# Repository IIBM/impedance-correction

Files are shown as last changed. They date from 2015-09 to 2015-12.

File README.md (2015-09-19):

# impedance-correction

This project involves the design, development and prototyping of an automated
**electrode impedance meter and corrector** for biological applications.

This will be achieved in the context of a basic embedded systems subject of the
Electronic Engineering career at the University of Buenos Aires:
[Laboratorio de Microcomputadoras](http://materias.fi.uba.ar/6609/).

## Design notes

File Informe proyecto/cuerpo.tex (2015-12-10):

%|//////////////////////////////////////|\\\\\\\\\\\\\\\\\\\\\\\\\\\\\\\\\\\\\|%
%|//////////////////////////| Objetivo del Proyecto |\\\\\\\\\\\\\\\\\\\\\\\\\|%
%|//////////////////////////////////////|\\\\\\\\\\\\\\\\\\\\\\\\\\\\\\\\\\\\\|%
\section{Objetivo del Proyecto}
% El objetivo es la respuesta a la pregunta “¿para qué?”; tiene que satisfacer alguna necesidad del usuario.

El presente proyecto consiste en el diseño y desarrollo de un sistema de calibración de impedancia y ajuste por electrodeposición (galvanoplastía). Este instrumento se utilizará en el futuro en aplicaciones biomédicas, más precisamente en la fabricación de electrodos de registro extracelular.

%|//////////////////////////////////////|\\\\\\\\\\\\\\\\\\\\\\\\\\\\\\\\\\\\\|%
%|////////////////////////| Descripción del Proyecto |\\\\\\\\\\\\\\\\\\\\\\\\|%
%|//////////////////////////////////////|\\\\\\\\\\\\\\\\\\\\\\\\\\\\\\\\\\\\\|%
\section{Descripción del Proyecto}
% En esta sección se responde la pregunta “¿cómo?”. Aquí se enumeran las prestaciones, las funciones y el comportamiento o uso del equipo.
El equipo consiste en un circuito con un microcontrolador que genera señales senoidales y continuas para medir y corregir las impedancias, respectivamente. Incluye una cuba conductora, que contiene una solución acuosa donde se colocan los electrodos. Éstos son similares a un filamento de cobre recubierto con esmalte aislante en su totalidad, excepto en los extremos, los cuales uno va sumergido en la solución y el otro conectado al equipo por medio de un conector especial.

El sistema funciona con 1, 4, 8, 12 ó 16 electrodos, corrigiendo de a uno por vez. El usuario coloca los electrodos procurando que no se produzcan cortocircuitos entre los mismos (se debería detectar esto antes de comenzar). Hay tres opciones: medir, calibrar y corregir. La primera permite ver el/los valor/es de la/s impedancia/s colocada/s en los conectores. La segunda, calibrar el equipo, tal como su nombre lo indica. La opción de corregir permite que el usuario seleccione la impedancia final deseada, el tiempo máximo de espera para la corrección y dé la orden de inicio. Luego de algunos chequeos básicos se da comienzo al proceso. Al terminar con todos los electrodos, se muestra la impedancia final de cada uno.

En líneas generales, el sistema consta de módulos de amplificación y filtros de PWM que permiten generar una señal senoidal con el microcontrolador, además de controlar la señal de offset. Asimismo, hay una fuente de corriente controlada por tensión que permite inyectar corriente continua al sistema para poder disminuir las impedancias necesarias por galvanoplastía.

La señal de salida del PWM es una corriente senoidal de \SI{1}{\kilo\hertz}, con uno de los siguientes valores de amplitud: $\{\SI{30}{\nano\ampere}, \SI{80}{\nano\ampere}, \SI{120}{\nano\ampere}, \SI{200}{\nano\ampere}\}$. Éstos se seleccionan con un multiplexor dependiendo del rango de impedancias: $\{0-\SI{2}{\mega\ohm}, 0-\SI{8}{\mega\ohm}, 0-\SI{20}{\mega\ohm}, 0-\SI{60}{\mega\ohm}\}$. Considerando la ley de Ohm y midiendo el valor pico de tensión, se calcula la impedancia del electrodo en estudio como $Z@\SI{1}{\kilo\hertz} = \frac{\hat{v}}{\hat{\imath}}$. Este valor se puede disminuir porque la solución acuosa contiene oro o plata, de modo de que se produce un recubrimiento por galvanoplastía sobre el electrodo y así disminuye la impedancia. Si este proceso es necesario o no, dependerá del resultado previo y de la comparación entre el valor obtenido en la medición y el de referencia establecido previamente por el usuario. Se emplea un multiplexor analógico para ir seleccionando cada electrodo y otro en paralelo con éste, que será eventualmente utilizado para verificar que no haya cortocircuitos entre electrodos.

Cada \SI{1}{\minute} se mide la impedancia y se corrige de ser necesario. Este proceso se repite tantas veces como se requiera hasta llegar al valor de impedancia deseada determinado previamente en la configuración. Los valores aceptables para empezar el proceso están entre \SI{1}{\mega\ohm} y \SI{8}{\mega\ohm}. Además, hay que pautar un tiempo máximo de sensado y corrección, para que el sistema deje de actuar en caso de haber pasado ese tiempo sin haber llegado al valor buscado. Éste puede valer 10, 20, 30, 40, 50 ó 60 minutos.

%|//////////////////////////////////////|\\\\\\\\\\\\\\\\\\\\\\\\\\\\\\\\\\\\\|%
%|/////////////////////////| Periféricos Principales |\\\\\\\\\\\\\\\\\\\\\\\\|%
%|//////////////////////////////////////|\\\\\\\\\\\\\\\\\\\\\\\\\\\\\\\\\\\\\|%

% Los periféricos son los elementos ajenos al microcontrolador con los que interactúa el equipo y deben estar claramente definidos (por ejemplo: motores, display, teclado, puertos de comunicación, sensores, etc.)

El dispositivo tiene una pantalla LCD donde se muestran las opciones de configuración para seleccionar a través de un menú y también los resultados del proceso, además de los mensajes de error o alerta (en caso de ocurrir algún imprevisto o no llegar al valor deseado en el tiempo pautado, por ejemplo). Las opciones se seleccionan desde un teclado de 4 botones (\texttt{ok}, \texttt{cancelar}, \texttt{mover izquierda}, \texttt{mover derecha}).

Además, como periféricos principales están los circuitos mencionados antes, a través de los cuales se interactúa directamente con los electrodos. Asimismo, otros elementos importantes con los que interactúa el microcontrolador son los multiplexores, que tienen 2 ó 4 entradas de control, según sean de 4 canales o 16, y la cuba electrolítica donde se produce la reacción química para disminuir la impedancia, que está compuesta por un material conductor, el cual también debe conectarse.

%|//////////////////////////////////////|\\\\\\\\\\\\\\\\\\\\\\\\\\\\\\\\\\\\\|%
%|///////////////| Características y Especificaciones Mínimas |\\\\\\\\\\\\\\\|%
%|//////////////////////////////////////|\\\\\\\\\\\\\\\\\\\\\\\\\\\\\\\\\\\\\|%

% Las especificaciones acotan las bondades del equipo. Deben listarse los rangos de funcionamiento o requerimientos externos (por ejemplo: tensión de alimentación, consumo, temperatura de funcionamiento, protocolos de comunicaciones, rangos de medición, etc.)

Las especificaciones del sistema son:

\begin{table}[H]
\begin{center}
\begin{tabular}{|r|l|}
    \hline
    Tensión de alimentación &
    \SI{5}{\volt} \\ \hline
    Rango de impedancias de los electrodos medidos &
    \SI{0}{\mega\ohm} - \SI{60}{\mega\ohm} (@ \SI{1}{\kilo\hertz})\\ \hline
    Impedancia buscada & $\simeq$ \SI{1}{\mega\ohm}\\ \hline
    Cantidad de electrodos a conectar &
    1, 4, 8, 12 ó 16 \\ \hline
    Tiempo máximo de corrección por electrodo &
    \SI{90}{\minute} (*)\\ \hline
    Modo medición & señal senoidal, \SI{1}{\kilo\hertz} \\ \hline
    Modo corrección & señal continua, 30/80/120/\SI{200}{\nano\ampere} \\ \hline
    Error de medición / corrección & $<$ 20\% / $<$ 20\% \\ \hline
\end{tabular}
\end{center}
\end{table}

(*) una vez cumplido este tiempo se abandonan los esfuerzos.

%|//////////////////////////////////////|\\\\\\\\\\\\\\\\\\\\\\\\\\\\\\\\\\\\\|%
%|/////////////////////| Diagrama en Bloques (hardware) |\\\\\\\\\\\\\\\\\\\\\|%
%|//////////////////////////////////////|\\\\\\\\\\\\\\\\\\\\\\\\\\\\\\\\\\\\\|%
\pagebreak
\section{Diagrama en Bloques (hardware)}
% El esquema general de interconexión de todos los dispositivos importantes se representa mediante un diagrama en bloques.
El diagrama de bloques aquí abajo muestra la interconexión de los dispositivos más relevantes del sistema.
\begin{center}
    
\end{center}

%|//////////////////////////////////////|\\\\\\\\\\\\\\\\\\\\\\\\\\\\\\\\\\\\\|%
%|//////////////////////| Diagrama de Flujo (firmware) |\\\\\\\\\\\\\\\\\\\\\\|%
%|//////////////////////////////////////|\\\\\\\\\\\\\\\\\\\\\\\\\\\\\\\\\\\\\|%
\section{Diagrama de Flujo  (firmware)}
% El diagrama de flujo ilustra de manera general la interacción entre los distintos bloques (o rutinas) de código.
El diagrama de flujo final del proyecto es el siguiente:
\begin{center}
    
\end{center}

%|//////////////////////////////////////|\\\\\\\\\\\\\\\\\\\\\\\\\\\\\\\\\\\\\|%
%|//////////////////////////| Circuito Esquemático |\\\\\\\\\\\\\\\\\\\\\\\\\\|%
%|//////////////////////////////////////|\\\\\\\\\\\\\\\\\\\\\\\\\\\\\\\\\\\\\|%
\section{Circuito Esquemático}
% La representación del circuito eléctrico final del prototipo debe realizarse en algún sistema CAD; no es necesario el diseño del circuito impreso (PCB), basta con el circuito esquemático.
A continuación se muestra el circuito esquemático correspondiente al prototipo, así como también el diseño del PCB. Ambos fueron realizados con el programa KiCad.\\

\hspace{-1.8cm}
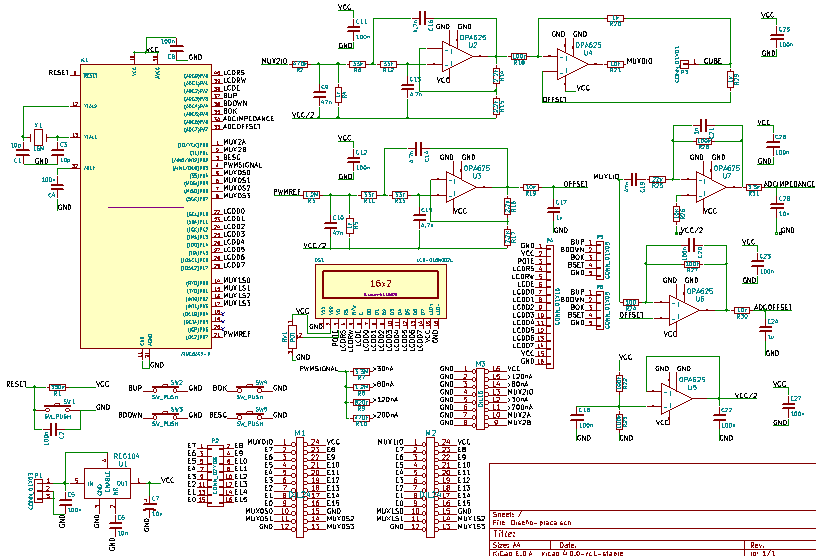
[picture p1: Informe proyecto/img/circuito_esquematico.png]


\hspace{-1cm}
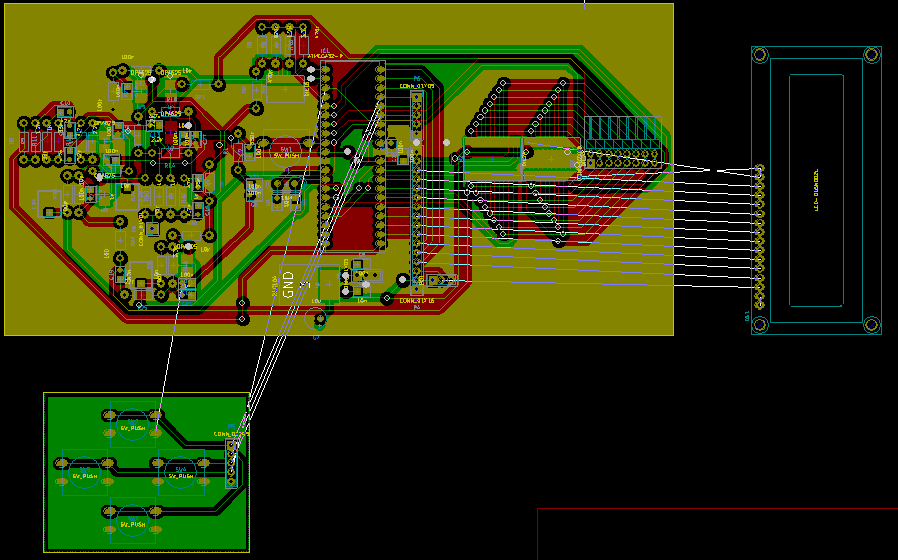
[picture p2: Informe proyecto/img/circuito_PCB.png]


%|//////////////////////////////////////|\\\\\\\\\\\\\\\\\\\\\\\\\\\\\\\\\\\\\|%
%|////////////////| Listado de Componentes y Costos Estimados |\\\\\\\\\\\\\\\|%
%|//////////////////////////////////////|\\\\\\\\\\\\\\\\\\\\\\\\\\\\\\\\\\\\\|%
\section{Listado de Componentes y Costos}
% En esta sección se debe incluir el listado final de componentes con sus respectivos costos. Además deben incorporar la estimación de horas-hombre insumidas en la realización del proyecto.
Los componentes que se emplearon para la construcción del dispositivo se muestran en la tabla siguiente:

\begin{table}[H]
\begin{center}
\begin{tabular}{|l|rr|}
    \hline
    \textbf{Componente} & \multicolumn{2}{c|}{\textbf{Costo}} \\ \hline
    Atmega32            & \hspace{2.8cm}\$ &   164.5 \\ \hline
    OPA625 x6 (*)       & \$               &   166.2 \\ \hline
    REG104 (*)          & \$               &   70.0 \\ \hline
    CD74HC4067 x2 (*)   & \$               &   16.8 \\ \hline
    SN74LV4052 (*)      & \$               &   5.0 \\ \hline
    Resistencias x30    & \$               &   9.6 \\ \hline
    Potenciómetro       & \$               &   6.7 \\ \hline
    Capacitores x31     & \$               &   43.1 \\ \hline
    Display LCD         & \$               &   120.0 \\ \hline
    Pulsadores x5       & \$               &   18.8 \\ \hline
    Cristal 16 Mhz      & \$               &   6.0 \\ \hline
    Conectores          & \$               &   8.6 \\ \hline
    Placa Epoxy         & \$               &   120.0 \\ \hline
    Zócalo              & \$               &   3.0 \\ \hline
    Jack power          & \$               &   3.2 \\ \hline
    TOTAL               & \$               &   761.5 \\ \hline
\end{tabular}
\end{center}
\end{table}

Los componentes marcados con un asterisco(*) son de Texas Instruments y en el marco del IIBM y de la Facultad se obtuvieron como muestras gratis. Por ende, para este trabajo en particular el costo de los componentes utilizados fue de $\$ 503.5$.\\

En cuanto a las horas-hombre involucradas, se puede estimar un número de 300 horas/hombre.

%|//////////////////////////////////////|\\\\\\\\\\\\\\\\\\\\\\\\\\\\\\\\\\\\\|%
%|///////////////////////////////| Resultados |\\\\\\\\\\\\\\\\\\\\\\\\\\\\\\\|%
%|//////////////////////////////////////|\\\\\\\\\\\\\\\\\\\\\\\\\\\\\\\\\\\\\|%
\section{Resultados}
% No siempre se logran los objetivos propuestos (o al menos en su totalidad); es importante que puedan validar y/o ajustar las expectativas indicando las limitaciones finales del prototipo construido.

Debido a las complicaciones en el diseño del hardware y los reiterados cambios que fueron hechos con el desarrollo del proyecto, se modificó el circuito de manera de poder medir impedancias del orden de los $k\Omega$, en vez de $M\Omega$, ya que las señales eran muy pequeñas y no se diferenciaban de las señales de ruido. Los nuevos rangos de medición son: $\{0-\SI{143}{\kilo\ohm}, \SI{143}{\kilo\ohm}-\SI{243}{\kilo\ohm}, \SI{243}{\kilo\ohm}-\SI{335}{\mega\ohm}, \SI{335}{\kilo\ohm}-\SI{900}{\mega\ohm}\}$.

Con estas modificaciones se pudo obtener un funcionamiento acorde a lo esperado, visualizando valores de impedancia en el display con un error aproximado del 15\%. Este error se debe a la alinealidad que genera el circuito. Como hipótesis, es posible considerar que se debe a que la fuente de corriente ya no se comporta linealmente con estos nuevos valores de corriente (se aumentaron 100 veces).

Fue posible observar el correcto funcionamiento de las rutinas de impresión por display, conversión ADC, obtención de la mediana a través de ordenamiento de tablas por burbujeo, utilización de pulsadores externos, timers, interrupciones, PWM. Se pudo observar, con el uso de un osciloscopio, el funcionamiento de la rutina de corrección de electrodos, observando un valor de continua. En la imagen a continuación se puede ver cómo en una primera etapa no hay corriente circulando, luego se observa la senoidal que sirve para medir y finalmente un valor de continua que permite corregir el valor de la impedancia.

\hspace{-1cm}


%|//////////////////////////////////////|\\\\\\\\\\\\\\\\\\\\\\\\\\\\\\\\\\\\\|%
%|//////////////////////////////| Conclusiones |\\\\\\\\\\\\\\\\\\\\\\\\\\\\\\|%
%|//////////////////////////////////////|\\\\\\\\\\\\\\\\\\\\\\\\\\\\\\\\\\\\\|%
\section{Conclusiones}
% En este punto tienen que describir mejoras posibles que podrían hacerse al equipo, cambios sugeridos en función de las experiencias aprendidas  y cualquier otra sugerencia relacionada con el proyecto.
Como mejoras, se puede mencionar que es altamente recomendable contar con una opción más en el menú para determinar si dos electrodos están o no en cortocircuito. Para ello, se emplea el segundo multiplexor (que aparece en el diseño pero no forma parte de este proyecto). Se podría realizar inyectando señal en cada electrodo y chequeando sobre cada uno de los restantes que no se reciba un nivel elevado de ésta. Además, agre

Por otro lado, sería útil para el usuario que hubiera alguna identificación para ver cuándo mide correctamente cada electrodo, si hay dos en cortocircuito y demás cuestiones que momentáneamente sólo aparecen al final del proceso (leds, por pantalla, etc), así el usuario no tiene que esperar hasta el final para ver si funcionó correctamente o no.

%|//////////////////////////////////////|\\\\\\\\\\\\\\\\\\\\\\\\\\\\\\\\\\\\\|%
%|////////////////////////////////| Apéndices |\\\\\\\\\\\\\\\\\\\\\\\\\\\\\\\|%
%|//////////////////////////////////////|\\\\\\\\\\\\\\\\\\\\\\\\\\\\\\\\\\\\\|%
\section{Apéndices}
% Como complemento al informe, en esta sección deben agregar el listado completo de software, las hojas de datos principales y cualquier otra información, referencia o cálculo relacionada con el proyecto (por ejemplo el uso de interrupciones).

\subsection{Cálculos}
A continuación se muestran los cálculos involucrados en la obtención de los parámetros $p$ por el que habrá que multiplicar a la medición del valor pico para obtener la impedancia. Vale aclarar que estos son valores iniciales y luego serán corregidos durante la calibración automática del equipo.

Los valores de lectura del ADC (8 bits), se procesan de la siguiente manera, para obtener un único valor pico, $\hat{L}$:
\begin{enumerate}
    \item Se muestrean 9 períodos.
    \item Se obtienen los máximos y mínimos locales de cada período.
    \item Se ordenan dichos máximos y mínimos en dos tablas, de menor a mayor.
    \item Se obtiene la mediana de cada tabla, eligiendo el valor central de la tabla ordenada.
    \item Se calcula $\hat{L} = \frac{<MAX>\,-\,<MIN>}{2}$.
\end{enumerate}

Una vez realizado esto se tiene en cuenta lo siguiente:
\begin{itemize}
    \item Como se dijo, $\hat{L}$ es el valor pico (en 8 bits) obtenido luego de procesar la señal muestreada.
    \item $k_{ADC}$ es la constante que lleva desde valores de lectura de 8 bits del ADC a \emph{volts}.
    \item $G$ es la ganancia de tensión del amplificador del ADC.
\end{itemize}

Entonces:
$$
    Z = \frac{\hat{v}}{\hat{\imath}} = \frac{G\,\hat{v}_{ADC}}{\hat{\imath}} = \frac{G\,k_{ADC}}{\hat{\imath}}\,\hat{L} = \alpha\,\hat{L}
$$

Como se ha visto, más allá de los factores que intervienen en la constante, la impedancia es proporcional al valor pico de lectura. Ahora, como la unidad interna de representación son \emph{décimas de mega ohm}, lo que se obtiene es $\beta = \frac{\alpha}{\SI{0.1}{\mega\ohm}}$, de forma tal que $\beta\,\hat{L}$ es la impedancia en la unidad deseada.

Dado que $\beta$ resulta menor a 1, y que no se dispone de una operación de división por hardware, se utilizará el parámetro $p = \lceil \gamma\,\beta \rceil$, donde $\gamma$ es una potencia de dos. En este caso se eligió $\gamma = 2^8 = 256$ y en consecuencia:
$$
    Z\ [[decimegohm]] = \beta\,\hat{L} = \frac{p\,\hat{L}}{\gamma} = \frac{p\,\hat{L}}{256} =  (p\,\hat{L})>>8
$$

Entonces el valor del parámetro $p$ está dado por:
$$
    p = \lceil \gamma\,\beta \rceil = \left\lceil \gamma\,\frac{\alpha}{\SI{0.1}{\mega\ohm}} \right\rceil = \left\lceil \gamma\,\frac{G\,k_{ADC}}{\SI{0.1}{\mega\ohm}\,\hat{\imath}} \right\rceil
$$

Dado que depende de $\hat{\imath}$, la cual es distinta en cada rango de medición, para esto y algunos cálculos extras de errores se utilizó la siguiente planilla.

\hspace{-2cm}

\subsection{Hojas de datos}

Los componentes empleados son:
\begin{table}[H]
\begin{center}
\begin{tabular}{|l|c|}
    \hline
    \textbf{Componente} & \textbf{Hoja de datos} \\ \hline
    Atmega32      & \url{http://www.atmel.com/images/doc2503.pdf} \\ \hline
    OPA625        & \url{http://www.ti.com/lit/ds/symlink/opa625.pdf} \\ \hline
    REG104        & \url{http://www.ti.com/lit/ds/symlink/reg104.pdf} \\ \hline
    CD74HC4067    & \url{http://www.ti.com/lit/ds/symlink/cd74hc4067.pdf} \\ \hline
    SN74LV4052    & \url{http://www.ti.com/lit/ds/symlink/sn74lv4052a.pdf} \\ \hline
    Display LCD   & \url{http://elmicro.com/files/lcd/gdm1602a\_datasheet.pdf} \\ \hline
\end{tabular}
\end{center}
\end{table}

%------------------------------------------------------------------------------%
%------------------------------- Códigos Fuente -------------------------------%
%------------------------------------------------------------------------------%
\subsection{Códigos fuente}
En las siguientes páginas se incluyen a modo de apéndice todos los archivos que conforman el firmware de equipo.

\subsubsection{configs.asm}
    \lstinputlisting[language=asmAVR]{src/configs.asm}

\subsubsection{main.asm}
    \lstinputlisting[language=asmAVR]{src/main.asm}

\subsubsection{MENU.asm}
    \lstinputlisting[language=asmAVR]{src/MENU.asm}

\subsubsection{MEDIR.asm}
    \lstinputlisting[language=asmAVR]{src/MEDIR.asm}

\subsubsection{CORREGIR\_FIN.asm}
    \lstinputlisting[language=asmAVR]{src/CORREGIR_FIN.asm}

\subsubsection{BCD.asm}
    \lstinputlisting[language=asmAVR]{src/BCD.asm}

\subsubsection{LCD.asm}
    \lstinputlisting[language=asmAVR]{src/LCD.asm}

\subsubsection{pwm.asm}
    \lstinputlisting[language=asmAVR]{src/pwm.asm}

\subsubsection{adc.asm}
    \lstinputlisting[language=asmAVR]{src/adc.asm}

\subsubsection{measure\_routines.asm}
    \lstinputlisting[language=asmAVR]{src/measure_routines.asm}

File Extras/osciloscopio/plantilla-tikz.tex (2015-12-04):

\documentclass{standalone}
\usepackage[utf8]{inputenc}
\usepackage[spanish]{babel}
\usepackage{siunitx}
\sisetup{output-decimal-marker = {,}} % Coma en vez de punto decimal
\usepackage{tikz}

\begin{document}
\newcommand{\Leg}[1]{{\footnotesize #1}}
\newcommand{\M}[1]{\Leg{$#1$}}

\input{_TIKZ_IMAGE_}
\end{document}

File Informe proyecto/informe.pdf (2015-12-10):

# F i u b a

# Facultad de Ingeniería

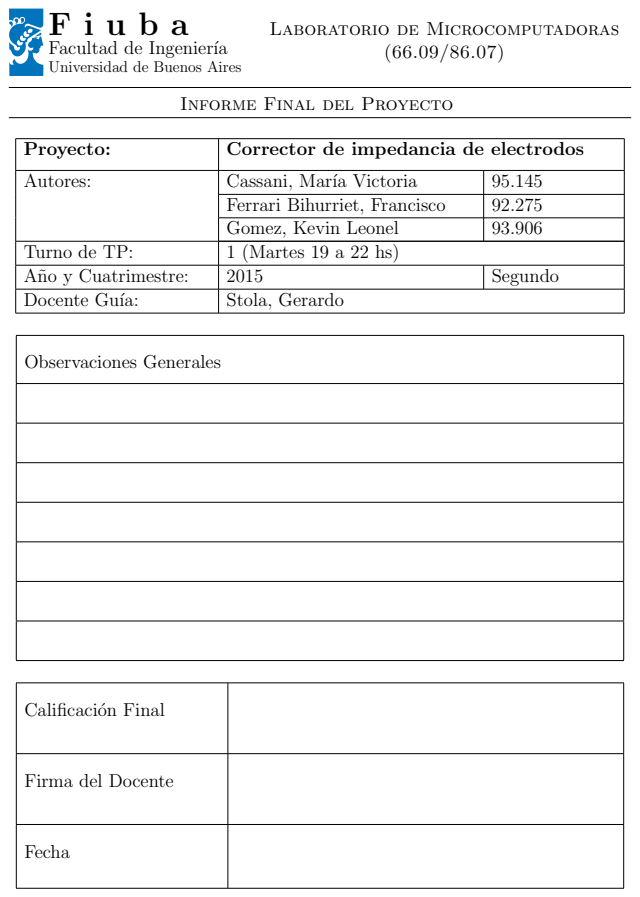
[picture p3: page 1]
Observaciones Generales

Laboratorio de Microcomputadoras

Universidad de Buenos Aires

Informe Final del Proyecto

Proyecto: | Corrector de impedancia de electrodos

Autores: | Cassani, María Victoria | 95.145

Ferrari Bihurriet, Francisco | 92.275
Gomez, Kevin Leonel | 93.906

Turno de TP: | 1 (Martes 19 a 22 hs)
Año y Cuatrimestre: | 2015 | Segundo
Docente Guía: | Stola, Gerardo

Calificación Final

Firma del Docente

Fecha

66.09/86.07 - Laboratorio de Microcomputadoras | Corrector de impedancia de electrodos

# Índice

1. Objetivo del Proyecto | 2
2. Descripción del Proyecto | 2
3. Diagrama en Bloques (hardware) | 4
4. Diagrama de Flujo (firmware) | 5
5. Circuito Esquemático | 6
6. Listado de Componentes y Costos | 7
7. Resultados | 8
8. Conclusiones | 9
9. Apéndices | 9
Cassani - Ferrari Bihurriet - Gomez | 1

# 1. Objetivo del Proyecto

## El presente proyecto consiste en el diseño y desarrollo de un sistema de calibración de

impedancia y ajuste por electrodeposición (galvanoplastía). Este instrumento se utilizará en el futuro en aplicaciones biomédicas, más precisamente en la fabricación de electrodos de registro extracelular.

# 2. Descripción del Proyecto

El equipo consiste en un circuito con un microcontrolador que genera señales senoidales y continuas para medir y corregir las impedancias, respectivamente. Incluye una cuba conducto-ra, que contiene una solución acuosa donde se colocan los electrodos. Estos son similares a un ´ filamento de cobre recubierto con esmalte aislante en su totalidad, excepto en los extremos, los cuales uno va sumergido en la solución y el otro conectado al equipo por medio de un conector especial.

## El sistema funciona con 1, 4, 8, 12 ó 16 electrodos, corrigiendo de a uno por vez. El

usuario coloca los electrodos procurando que no se produzcan cortocircuitos entre los mismos (se debería detectar esto antes de comenzar). Hay tres opciones: medir, calibrar y corregir. La primera permite ver el/los valor/es de la/s impedancia/s colocada/s en los conectores. La segunda, calibrar el equipo, tal como su nombre lo indica. La opción de corregir permite que el usuario seleccione la impedancia final deseada, el tiempo máximo de espera para la corrección y dé la orden de inicio. Luego de algunos chequeos básicos se da comienzo al proceso. Al terminar con todos los electrodos, se muestra la impedancia final de cada uno.

## En líneas generales, el sistema consta de módulos de amplificación y filtros de PWM que permiten generar una señal senoidal con el microcontrolador, además de controlar la

señal de offset. Asimismo, hay una fuente de corriente controlada por tensión que permite inyectar corriente continua al sistema para poder disminuir las impedancias necesarias por galvanoplastía.

## La señal de salida del PWM es una corriente senoidal de 1 kHz, con uno de los siguientes

valores de amplitud: {30 nA, 80 nA, 120 nA, 200 nA}. Estos se seleccionan con un multiplexor ´

## dependiendo del rango de impedancias: {0 − 2 MΩ, 0 − 8 MΩ, 0 − 20 MΩ, 0 − 60 MΩ}. Con-

siderando la ley de Ohm y midiendo el valor pico de tensión, se calcula la impedancia del

## electrodo en estudio como Z@1 kHz = vˆ

î

## . Este valor se puede disminuir porque la solución

acuosa contiene oro o plata, de modo de que se produce un recubrimiento por galvanoplastía sobre el electrodo y así disminuye la impedancia. Si este proceso es necesario o no, depen-derá del resultado previo y de la comparación entre el valor obtenido en la medición y el de referencia establecido previamente por el usuario. Se emplea un multiplexor analógico para ir seleccionando cada electrodo y otro en paralelo con éste, que será eventualmente utilizado para verificar que no haya cortocircuitos entre electrodos.

Cada 1 min se mide la impedancia y se corrige de ser necesario. Este proceso se repite tantas veces como se requiera hasta llegar al valor de impedancia deseada determinado previamente en la configuración. Los valores aceptables para empezar el proceso están entre 1 MΩ y 8 MΩ.

Además, hay que pautar un tiempo máximo de sensado y corrección, para que el sistema deje de actuar en caso de haber pasado ese tiempo sin haber llegado al valor buscado. Este puede ´ valer 10, 20, 30, 40, 50 ó 60 minutos.

## El dispositivo tiene una pantalla LCD donde se muestran las opciones de configuración

para seleccionar a través de un menú y también los resultados del proceso, además de los mensajes de error o alerta (en caso de ocurrir algún imprevisto o no llegar al valor deseado en el tiempo pautado, por ejemplo). Las opciones se seleccionan desde un teclado de 4 botones (ok, cancelar, mover izquierda, mover derecha).

Además, como periféricos principales están los circuitos mencionados antes, a través de los cuales se interactúa directamente con los electrodos. Asimismo, otros elementos importantes con los que interactúa el microcontrolador son los multiplexores, que tienen 2 ó 4 entradas de control, según sean de 4 canales o 16, y la cuba electrolítica donde se produce la reacción química para disminuir la impedancia, que está compuesta por un material conductor, el cual también debe conectarse.

## Las especificaciones del sistema son:

Tensión de alimentación | 5 V
Rango de impedancias de los electrodos medidos | 0 MΩ - 60 MΩ (@ 1 kHz)
Impedancia buscada | ' 1 MΩ
Cantidad de electrodos a conectar | 1, 4, 8, 12 ó 16
Tiempo máximo de corrección por electrodo | 90 min (*)
Modo medición | señal senoidal, 1 kHz
Modo corrección | señal continua, 30/80/120/200 nA
Error de medición / corrección | < 20 % / < 20 %

(*) una vez cumplido este tiempo se abandonan los esfuerzos.

# 3. Diagrama en Bloques (hardware)

El diagrama de bloques aquí abajo muestra la interconexión de los dispositivos más rele-vantes del sistema.

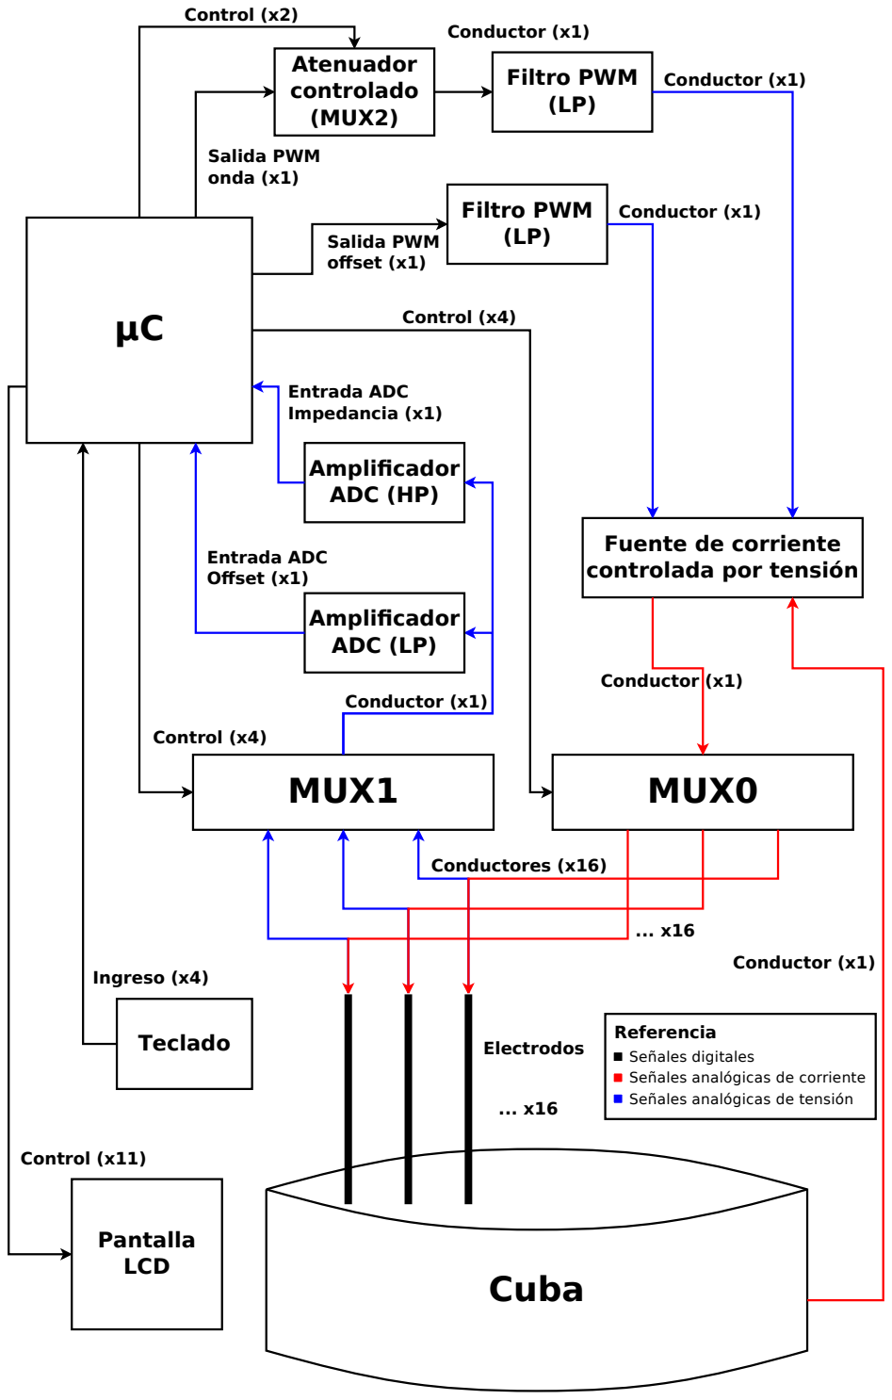
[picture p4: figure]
Fuente de corriente controlada por tensión; MUX1; MUX0; Teclado; Pantalla LCD; Control (x4); Entrada ADC Impedancia (x1); Ingreso (x4); Salida PWM onda (x1); Control (x2); Conductor (x1); Conductores (x16); Control (x11); Filtro PWM (LP); Atenuador controlado (MUX2); Amplificador ADC (HP); Amplificador ADC (LP); Cuba; Salida PWM offset (x1); Entrada ADC Offset (x1); Electrodos; Señales digitales Señales analógicas de corriente Señales analógicas de tensión; Referencia

# 4. Diagrama de Flujo (firmware)

## El diagrama de flujo final del proyecto es el siguiente:

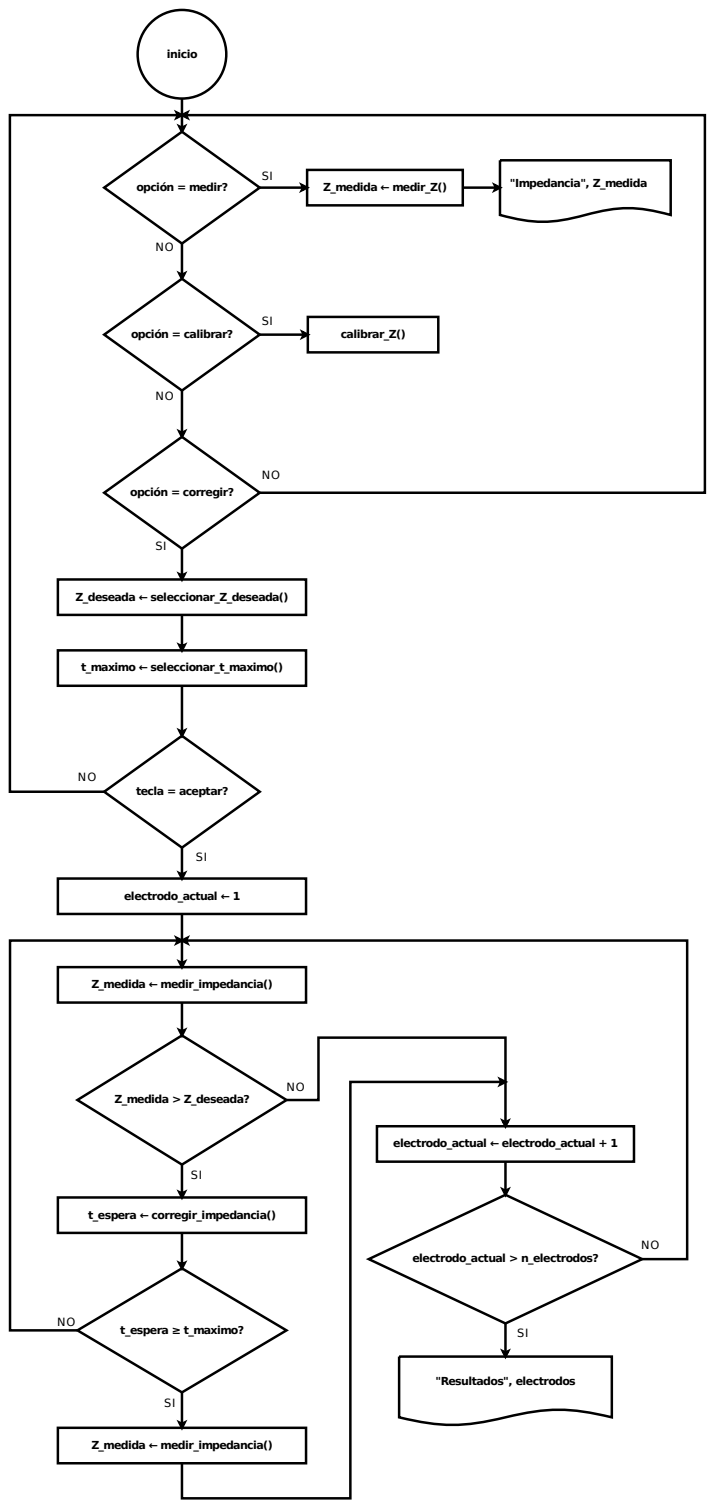
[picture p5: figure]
"Impedancia", Z_medida; inicio; Z_deseada ← seleccionar_Z_deseada(); t_maximo ← seleccionar_t_maximo(); tecla = aceptar?; electrodo_actual ← 1; Z_medida > Z_deseada?; t_espera ← corregir_impedancia(); t_espera ≥ t_maximo?; Z_medida ← medir_impedancia(); electrodo_actual ← electrodo_actual + 1; electrodo_actual > n_electrodos?; "Resultados", electrodos; opción = medir?; Z_medida ← medir_Z(); opción = calibrar?; calibrar_Z(); opción = corregir?

# 5. Circuito Esquemático

A continuación se muestra el circuito esquemático correspondiente al prototipo, así como

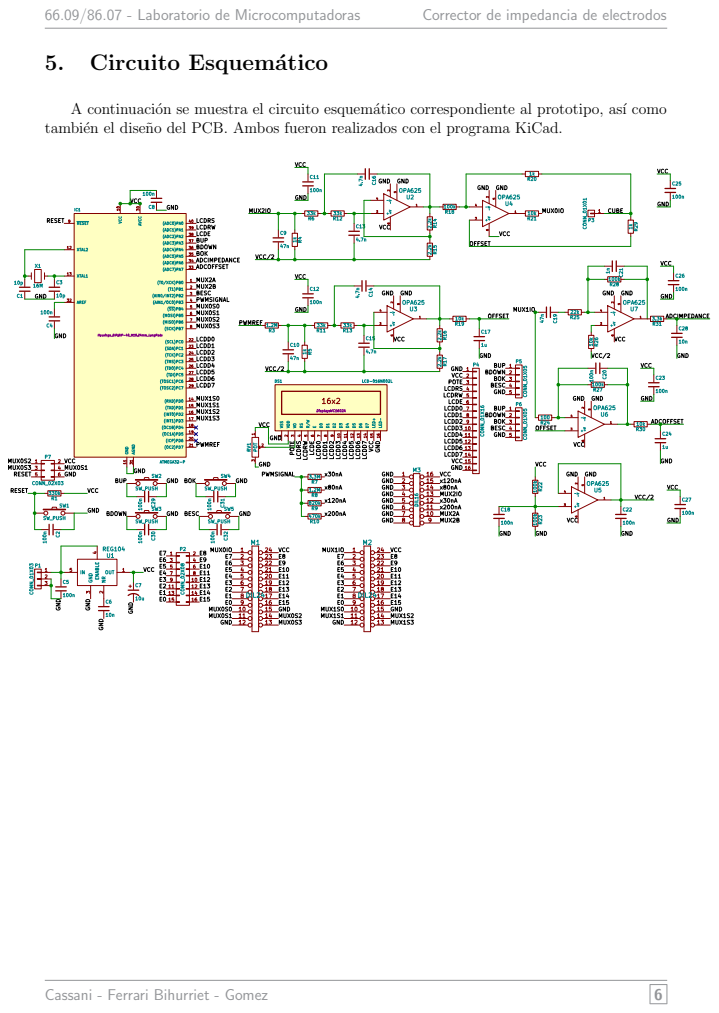
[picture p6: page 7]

también el diseño del PCB. Ambos fueron realizados con el programa KiCad.

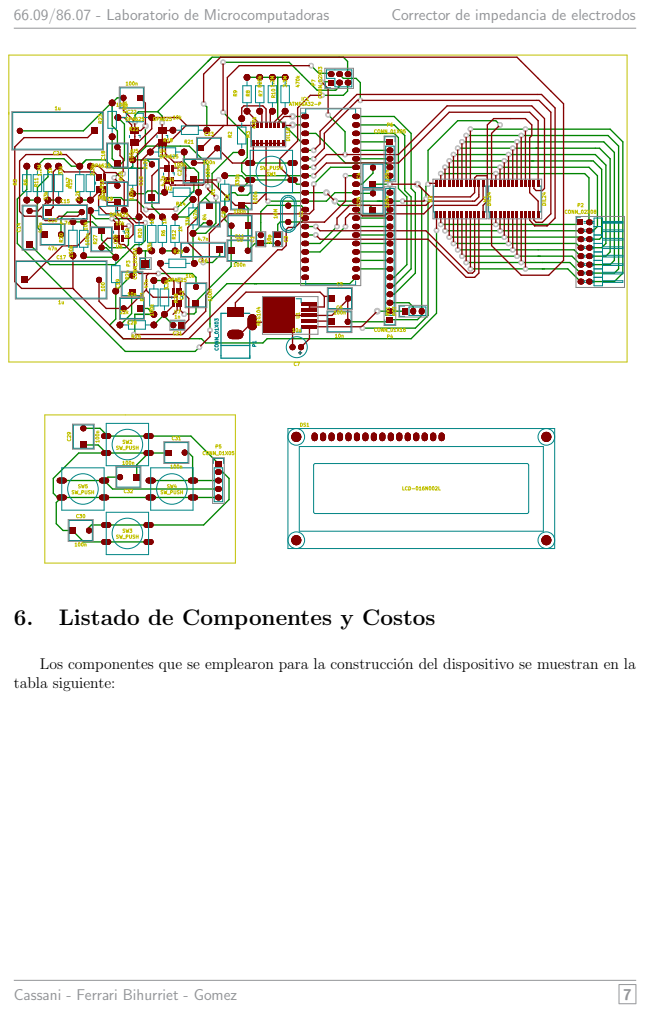
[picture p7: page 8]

6. Listado de Componentes y Costos

Los componentes que se emplearon para la construcción del dispositivo se muestran en la
tabla siguiente:

Componente | Costo
Atmega32 | $ 164.5
OPA625 x6 (*) | $ 166.2
REG104 (*) | $ 70.0
CD74HC4067 x2 (*) | $ 16.8
SN74LV4052 (*) | $ 5.0
Resistencias x30 | $ 9.6
Potenciómetro | $ 6.7
Capacitores x31 | $ 43.1
Display LCD | $ 120.0
Pulsadores x5 | $ 18.8
Cristal 16 Mhz | $ 6.0
Conectores | $ 8.6
Placa Epoxy | $ 120.0
Zócalo | $ 3.0
Jack power | $ 3.2
TOTAL | $ 761.5

## Los componentes marcados con un asterisco(*) son de Texas Instruments y en el marco

del IIBM y de la Facultad se obtuvieron como muestras gratis. Por ende, para este trabajo en particular el costo de los componentes utilizados fue de $503,5.

## En cuanto a las horas-hombre involucradas, se puede estimar un número de 300 hora-

s/hombre.

# 7. Resultados

## Debido a las complicaciones en el diseño del hardware y los reiterados cambios que fueron hechos con el desarrollo del proyecto, se modificó el circuito de manera de poder medir impedancias del orden de los kΩ, en vez de MΩ, ya que las señales eran muy pe-

queñas y no se diferenciaban de las señales de ruido. Los nuevos rangos de medición son: {0 − 143 kΩ, 143 kΩ − 243 kΩ, 243 kΩ − 335 MΩ, 335 kΩ − 900 MΩ}.

## Con estas modificaciones se pudo obtener un funcionamiento acorde a lo esperado, visua-

lizando valores de impedancia en el display con un error aproximado del 15 %. Este error se debe a la alinealidad que genera el circuito. Como hipótesis, es posible considerar que se debe a que la fuente de corriente ya no se comporta linealmente con estos nuevos valores de corriente (se aumentaron 100 veces).

Fue posible observar el correcto funcionamiento de las rutinas de impresión por display, conversión ADC, obtención de la mediana a través de ordenamiento de tablas por burbujeo, utilización de pulsadores externos, timers, interrupciones, PWM. Se pudo observar, con el uso de un osciloscopio, el funcionamiento de la rutina de corrección de electrodos, observando un valor de continua. En la imagen a continuación se puede ver cómo en una primera etapa no hay corriente circulando, luego se observa la senoidal que sirve para medir y finalmente un valor de continua que permite corregir el valor de la impedancia.

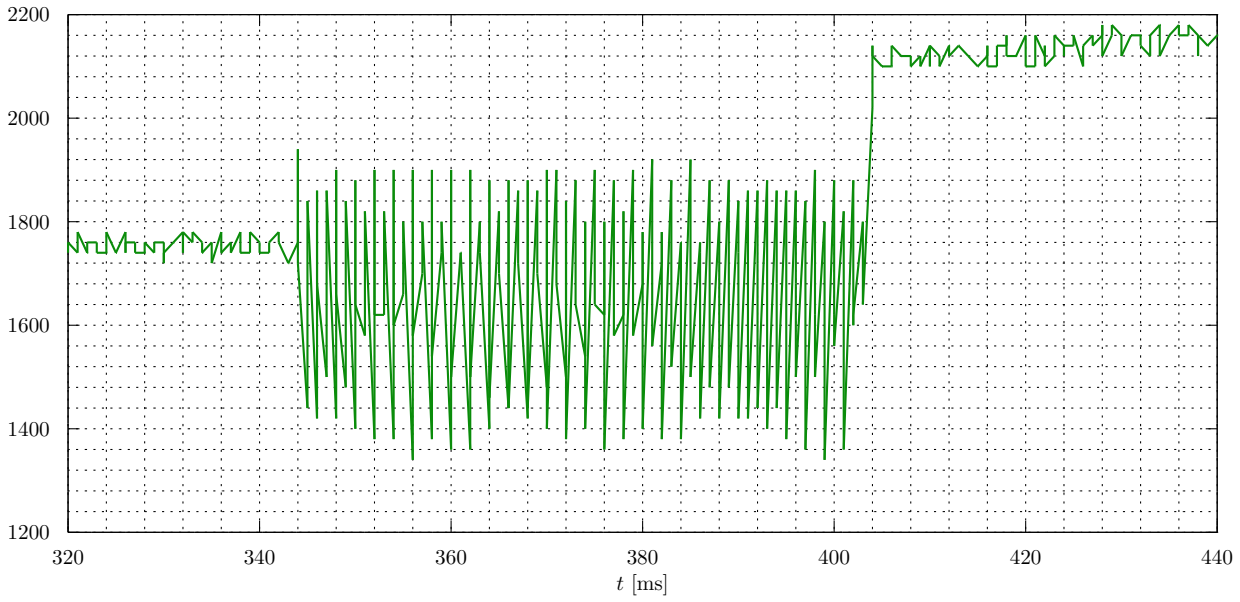
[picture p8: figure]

## V [mV]

# 8. Conclusiones

## Como mejoras, se puede mencionar que es altamente recomendable contar con una opción

más en el menú para determinar si dos electrodos están o no en cortocircuito. Para ello, se emplea el segundo multiplexor (que aparece en el diseño pero no forma parte de este proyecto). Se podría realizar inyectando señal en cada electrodo y chequeando sobre cada uno de los

## restantes que no se reciba un nivel elevado de ésta. Además, agre

Por otro lado, sería útil para el usuario que hubiera alguna identificación para ver cuándo mide correctamente cada electrodo, si hay dos en cortocircuito y demás cuestiones que mo-mentáneamente sólo aparecen al final del proceso (leds, por pantalla, etc), así el usuario no tiene que esperar hasta el final para ver si funcionó correctamente o no.

# 9. Apéndices

# 9.1. Cálculos

A continuación se muestran los cálculos involucrados en la obtención de los parámetros p por el que habrá que multiplicar a la medición del valor pico para obtener la impedancia. Vale aclarar que estos son valores iniciales y luego serán corregidos durante la calibración automática del equipo.

## Los valores de lectura del ADC (8 bits), se procesan de la siguiente manera, para obtener un único valor pico, Lˆ:

1. Se muestrean 9 períodos.
2. Se obtienen los máximos y mínimos locales de cada período.
3. Se ordenan dichos máximos y mínimos en dos tablas, de menor a mayor.
4. Se obtiene la mediana de cada tabla, eligiendo el valor central de la tabla ordenada.

## 5. Se calcula Lˆ =

<MAX> − <MIN>
2

## Una vez realizado esto se tiene en cuenta lo siguiente:

Como se dijo, Lˆ es el valor pico (en 8 bits) obtenido luego de procesar la señal muestreada.

kADC es la constante que lleva desde valores de lectura de 8 bits del ADC a volts.

G es la ganancia de tensión del amplificador del ADC.

## Entonces:

Z =

vˆ
î

=

## G vÂDC

î

=

G kADC
î

## Lˆ = α Lˆ

Como se ha visto, más allá de los factores que intervienen en la constante, la impedancia es proporcional al valor pico de lectura. Ahora, como la unidad interna de representación son

## décimas de mega ohm, lo que se obtiene es β =

α

## 0,1 MΩ, de forma tal que β Lˆ es la impedancia

en la unidad deseada.

## Dado que β resulta menor a 1, y que no se dispone de una operación de división por

hardware, se utilizará el parámetro p = dγ βe, donde γ es una potencia de dos. En este caso

## se eligió γ = 2⁸ = 256 y en consecuencia:

## Z [[decimegohm]] = β Lˆ =

## p Lˆ

γ

=

## p Lˆ

256

## = (p Lˆ) >> 8

## Entonces el valor del parámetro p está dado por:

## p = dγ βe =

γ

α

0,1 MΩ
=
γ

G kADC

## 0,1 MΩî

Dado que depende de î, la cual es distinta en cada rango de medición, para esto y algunos cálculos extras de errores se utilizó la siguiente planilla.

Rango [MΩ] | I máx [nA] | Escala: x/128 (por soft) | I [nA] | ΔV [mV] si ΔZ = 0,1MΩ | ΔZ [MΩ] si ΔV = kADC | ΔZ [MΩ] si ΔV = 96,5mV | Vexcursión [V] | α [kΩ] | β = α / 0,1 MΩ | p = γ β ⌈ ⌉ | Error absoluto [kΩ] | Error relativo [%]
0 2 | | 200,00 212,31 | 128 100,00% | 200,00 212,31 | 90,91 96,51 | 0,021 0,020 | 0,106 0,100 | 1,82 1,93 | 21,48 20,24 | 0,215 0,202 | 55 52 | 100 100 | 10,00% 10,00%
0 8 | | 80,00 83,26 | 84 65,63% | 52,50 54,64 | 23,86 24,84 | 0,082 0,079 | 0,404 0,389 | 1,91 1,99 | 81,85 78,64 | 0,818 0,786 | 210 202 | 100 100 | 2,50% 2,50%
0 | 20 | 30,00 30,29 | 92 71,88% | 21,56 21,77 | 9,80 9,90 | 0,199 0,197 | 0,985 0,975 | 1,96 1,98 | 199,28 197,34 | 1,993 1,973 | 511 506 | 100 200 | 1,00% 2,00%
0 | 60 | 30,00 30,29 | 30 23,44% | 7,03 7,10 | 3,20 3,23 | 0,611 0,605 | 3,020 2,990 | 1,92 1,94 | 611,11 605,18 | 6,111 6,052 | 1565 1550 | 100 400 | 0,33% 1,33%
G OpAmp ADC | Vexcursión deseado [V] | kADC [mV] | γ = 2^k
4,55 | 2,00 | 19,53 | 256
Corriente deseada [nA] | R multiplexada [kΩ] | Corriente final [nA]
30 | 3300 | 30,29
80 | 1200 | 83,26
120 | 820 | 121,80
200 | 470 | 212,31

# 9.2. Hojas de datos

## Los componentes empleados son:

Componente | Hoja de datos
Atmega32 | http://www.atmel.com/images/doc2503.pdf
OPA625 | http://www.ti.com/lit/ds/symlink/opa625.pdf
REG104 | http://www.ti.com/lit/ds/symlink/reg104.pdf
CD74HC4067 | http://www.ti.com/lit/ds/symlink/cd74hc4067.pdf
SN74LV4052 | http://www.ti.com/lit/ds/symlink/sn74lv4052a.pdf
Display LCD | http://elmicro.com/files/lcd/gdm1602a_datasheet.pdf

# 9.3. Códigos fuente

En las siguientes páginas se incluyen a modo de apéndice todos los archivos que conforman el firmware de equipo.

## 9.3.1. configs.asm

1 ; ||||||||||||||||||||||||||||||||||||||||||||||||||||||||||||||||||||||||||||||; 2 ; ||||||||||||||||||||||||||||||||| Constantes |||||||||||||||||||||||||||||||||; 3 ; ||||||||||||||||||||||||||||||||||||||||||||||||||||||||||||||||||||||||||||||;

4
5 ; ---------------------------- Configuraci ón del PWM -- ---- ----- ----- ---- ----- --;
6 ;
7 ; Compare Output Mode : COMn1 : COMn0 = 1:0 => Clear OCn on compare match
8 ; Waveform Generation Mode : WGMn1 : WGMn0 1:1 => Fast PWM
9 ; Clock select : CSn2 : CSn1 : CSn0 = 0:0:1 => CPU clock , no prescaling
10 ;
11 ; * Timer / Counter -n Control Register : (n = 0 , 2. Timer / Counter0 , Timer / Counter2 )
12 ; | | | FOCn | | | WGMn0 | | COMn1 | | COMn0 | | WGMn1 | | CSn2 | | | CSn1 | | | CSn0 | |
13 ; | | | 0 | | | 1 | | | 1 | | | 0 | | | 1 | | | 0 | | | 0 | | | 1 | |

14 ;
15 ; Timer0 Overflow Interrupt Enable : TOIE0 = 1 = > Enabled
16 ; Timer2 Overflow Interrupt Enable : TOIE2 = 0 = > Disabled
17 ;
18 ; * Timer / Counter Interrupt Mask Register :
19 ; | | | OCIE2 | | TOIE2 | TICIE1 | OCIE1A | OCIE1B | | TOIE1 | | OCIE0 | | TOIE0 |
20 ; | | | x | | | 0 | | | x | | | x | | | x | | | x | | | x | | | 1 | |

21 ;
22 .equ PWM_FAST_PWM_CONFIG_T1 = (1 < < COM01 ) | (1 < < WGM01 ) | (1 < < WGM00 ) | (1 < < CS00 )
23 .equ PWM_FAST_PWM_CONFIG_T2 = (1 < < COM21 ) | (1 < < WGM21 ) | (1 < < WGM20 ) | (1 < < CS20 )
24 .equ PWM_OFF_PWM_CONFIG | = 0
25 .equ PWM_OV_INTERRUPT_MASK | = (1 < < TOIE0 )
26 .equ PWM_SINE_TABLE_LEN | = 62
27 .equ PWM_SINE_MEDIAN | = 127

28
29 ; --------------------- Configuraci ón del Timer1 (16 bits ) -- ----- ----- ---- -----;

30 ;
31 ; Waveform Generation Mode : WGM13 : WGM12 : WGM11 : WGM10 0:0:0:0 => Normal mode
32 ; Clock select : CS12 : CS11 : CS10 = 0:1:1 => CPU clock , divided by 64 -> 250 kHz
33 ;
34 ; * Timer / Counter1 Control Register A:
35 ; | | COM1A1 | COM1A0 | COM1B1 | COM1B0 | | FOC1A | | FOC1B | | WGM11 | | WGM10 |
36 ; | | | 0 | | | 0 | | | 0 | | | 0 | | | 0 | | | 0 | | | 0 | | | 0 | |

37 ;
38 ; * Timer / Counter1 Control Register B:
39 ; | | | ICNC1 | | ICES1 | | * Res * | | WGM13 | | WGM12 | | CS12 | | | CS11 | | | CS10 | |

40 ; | | | 0 | | | 0 | | | 0 | | | 0 | | | 0 | | | 0 | | | 1 | | | 1 | |

41 ;
42 .equ TIMER1_CLOCK_64_PRESCALER = (1 < < CS11 ) | (1 < < CS10 )
43 .equ TIMER1_OFF | = 0
44 .equ TIMER1_50ms_DELAY_START | = -12500 ; 12500 / 250 kHz = 50 ms

45
46 ; ---------------------------- Configuraci ón del ADC -- ---- ----- ----- ---- ----- --;
47 ;
48 ; Reference Selection : REFS1 : REFS0 = 0:1 => AVCC with ext capacitor at AREF pin 49 ; ADC Left Adjust Result : ADLAR = 1 => On (8 bits precision reading ADCH only ) 50 ; Analog Channel and Gain Selection Bits : MUX4 : MUX3 : MUX2 : MUX1 : MUX0
51 ; | 1) ImpedanceMeasure | = 6
52 ; | 2) OffsetCalibration = 7

53 ;
54 ; * ADC Multiplexer Selection Register :
55 ; | | | REFS1 | | REFS0 | | ADLAR | | MUX4 | | | MUX3 | | | MUX2 | | | MUX1 | | | MUX0 | |
56 ; | | | 0 | | | 1 | | | 1 | | | 0 | | | 0 | | | x | | | x | | | x | |

57 ;
58 ; ADC enable : ADEN = 1 => Enabled
59 ; ADC Auto Trigger Mode : ADATE = 0 => Disabled
60 ; ADC Interrupt Enable : ADIE = 1 => Enabled
61 ; ADC Prescaler Select Bits : ADPS2 : ADPS1 : ADPS0 = 1:0:1 => fCk_ADC = fCk /32

62 ;
63 ; * ADC Control and Status Register A:
64 ; | | | ADEN | | | ADSC | | | ADATE | | ADIF | | | ADIE | | | ADPS2 | | ADPS1 | | ADPS0 |
65 ; | | | 1 | | | 0 | | | 0 | | | 0 | | | 1 | | | 1 | | | 0 | | | 1 | |

66 ;

67
68 .equ ADC_AREF_LEFT_ADJUST_CONFIG = (1 < < REFS0 ) | (1 < < ADLAR )
69 .equ ADC_ENABLE_AUTO_INT_PRESC | = (1 < < ADEN ) | | (1 < < ADIE ) | \
70 | (1 < < ADPS2 ) | (1 < < ADPS0 )
71 .equ ADC_DISABLE | = 0
72 .equ ADC_PERIODS_TO_SAMPLE | = 9
73 .equ ADC_SAMPLES_PER_PERIOD = 37 ; Ya que fADC = 37 ,037 kHz ( sampling freq ) 74 .equ ADC_SAMPLES_TABLE_LEN = ADC_PERIODS_TO_SAMPLE * ADC_SAMPLES_PER_PERIOD

75
76 ; Enumerativo para la entrada a medir
77 .equ ADC_IMPEDANCE_MEASURE = 6
78 .equ ADC_OFFSET_CALIBRATION = 7

79
80 ; --------------------- Configuraci ón de rangos de medici ón --- ---- ----- ----- ---; 81 ; Valores del multiplexor MUX2
82 .equ MUX2_x30nA | = 0
83 .equ MUX2_x80nA | = 1
84 .equ MUX2_x120nA = 2
85 .equ MUX2_x200nA = 3

86
87 ; Enumerativo para los rangos de medici ón 88 .equ MEAS_RANGE_1 = 0
89 .equ MEAS_RANGE_2 = 1
90 .equ MEAS_RANGE_3 = 2
91 .equ MEAS_RANGE_4 = 3
92 ; ---------------------------- Registros especiales --- ---- ----- ----- ---- ----- --;
93 .def tmp | = R16 | ; Temporario , siempre se podr á pisar sin salvarlo
94 .def param = R17 | ; Par á metro para rutinas
95 .def iter | = R18 | ; Iterador , mú ltiple uso , salvar al pisarlo
96 .def iter2 = R19 | ; Iterador , mú ltiple uso , salvar al pisarlo

97
98 ; XXX XXX XXX XXX XXX XXX -- NOTE -- XXX XXX XXX XXX XXX XXX
99 ; Registros siempre en uso por interrupciones , no usar para otra cosa durante 100 ; las mediciones ! --> R20 , X ( R27 : R26 ), R25:R24 , Y (R29 :R28)
101 .def tbl_i = R20 ; Iterador de tabla en RAM , en uso durante mediciones !
102 .def tbl_jl = R24 ; Iterador de 16 - bits ( parte baja ), en uso durante mediciones ! 103 .def tbl_jh = R25 ; Iterador de 16 - bits ( parte alta ), en uso durante mediciones !

104
105
106 ; |//////////////////////////////////////|\\\\\\\\\\\\\\\\\\\\\\\\\\\\\\\\\\\\\|; 107 ; |//////////////////////| Direcciones reservadas en RAM |\\\\\\\\\\\\\\\\\\\\\|; 108 ; |//////////////////////////////////////|\\\\\\\\\\\\\\\\\\\\\\\\\\\\\\\\\\\\\|;
109 .dseg

110 .org SRAM_START

111
112 ; Tabla : seno escalado , listo para actualizar el PWM 113 PWM_SINE_RAM_TABLE :
114 | .byte PWM_SINE_TABLE_LEN

115
116 ; Tabla : entrada del ADC muestreada durante ADC_PERIODS_TO_SAMPLE per í odos 117 ADC_SAMPLES_RAM_TABLE :
118 | .byte ADC_SAMPLES_TABLE_LEN

119
120 ; Tabla : má ximos de cada per íodo , luego se ordenar á para obtener la mediana 121 ADC_MAXS_RAM_TABLE :
122 | .byte ADC_PERIODS_TO_SAMPLE

123
124 ; Tabla : mí nimos de cada per íodo , luego se ordenar á para obtener la mediana 125 ADC_MINS_RAM_TABLE :
126 | .byte ADC_PERIODS_TO_SAMPLE

127
128 ; Conversi ón de BCD a ASCII , en esta posici ón queda el resultado en ASCII 129 BCD_TO_ASCII_CONVERT_RAM :
130 | .byte 5*16

131
132
133 ; |//////////////////////////////////////|\\\\\\\\\\\\\\\\\\\\\\\\\\\\\\\\\\\\\|; 134 ; |////////////////////////| Vector de interrupciones |\\\\\\\\\\\\\\\\\\\\\\\\|; 135 ; |//////////////////////////////////////|\\\\\\\\\\\\\\\\\\\\\\\\\\\\\\\\\\\\\|;
136 .cseg

137
138 ; Interrupci ón reset -> MAIN
139 .org 0 x0
140 | jmp | MAIN

141
142 ; Interrupci ón de overflow del Timer0 143 .org OVF0addr
144 | jmp | PWM_DUTY_CYCLE_UPDATE_ISR

145
146 ; Interrupci ón de conversi ón completa del ADC 147 .org ADCCaddr
148 | jmp | ADC_SAMPLE_STORE_TO_RAM_ISR

149
150 ; Interrupci ón de bot ón de ESC ( INT2 ) 151 .org INT2addr
152 | jmp | INT2_ESC_BUTTON_ISR

153
154 ; Final del vector de interrupciones 155 .org INT_VECTORS_SIZE

156
157
158 ; |//////////////////////////////////////|\\\\\\\\\\\\\\\\\\\\\\\\\\\\\\\\\\\\\|; 159 ; |/////////////////////////////| Datos en flash |\\\\\\\\\\\\\\\\\\\\\\\\\\\\\|; 160 ; |//////////////////////////////////////|\\\\\\\\\\\\\\\\\\\\\\\\\\\\\\\\\\\\\|;
161 PWM_SINE_FLASH_TABLE :
162 | .db 0 x00 , 0 x0D , 0 x19 , 0 x26 , 0 x32 , 0 x3D , 0 x48 , 0 x52 , 0 x5B , 0 x64 , 0 x6B , 0 x72
163 | .db 0 x77 , 0 x7B , 0 x7D , 0 x7F , 0 x7F , 0 x7E , 0 x7B , 0 x78 , 0 x73 , 0 x6D , 0 x66 , 0 x5E
164 | .db 0 x55 , 0 x4B , 0 x40 , 0 x35 , 0 x29 , 0 x1C , 0 x10 , 0 x03 , 0 xF6 , 0 xEA , 0 xDD , 0 xD1
165 | .db 0 xC6 , 0 xBB , 0 xB0 , 0 xA7 , 0 x9E , 0 x97 , 0 x90 , 0 x8B , 0 x86 , 0 x83 , 0 x81 , 0 x81
166 | .db 0 x82 , 0 x84 , 0 x87 , 0 x8C , 0 x91 , 0 x98 , 0 xA0 , 0 xA9 , 0 xB3 , 0 xBD , 0 xC8 , 0 xD4
167 | .db 0 xE0 , 0 xED

168
169 ; === Multiplexor MUX2 para cada rango de medici ón ===
170 MEAS_RANGE_FLASH_SIN_MUX2_VALUES :
171 | .db MUX2_x200nA , MUX2_x120nA , MUX2_x80nA , MUX2_x30nA

172
173 ; === Valor de amplitud para cada rango de medici ón === 174 ; 128 --> 100 ,0 % --> 200 ,0 nA de corriente pico
175 ; | 84 --> | 65 ,6 % --> | 52 ,5 nA de corriente pico
176 ; | 92 --> | 71 ,9 % --> | 21 ,6 nA de corriente pico
177 ; | 30 --> | 23 ,4 % --> | 7 ,0 nA de corriente pico
178 MEAS_RANGE_FLASH_SINAMPS :
179 | .db 128 , 128 , 128 , 128

180
181 ; === Valores de piso para cada rango de medici ón, en kilo ohm (16 bit !) === 182 MEAS_RANGE_FLASH_FLOOR_VALUES :
183 | .dw 0, 143 , 243 , 335 ; Unidad : kohm

184
185 ; === Valores del par á metro p inicial para cada rango de medici ón (16 bit !) === 186 MEAS_RANGE_FLASH_P_FACTOR_DEFAULTS :
187 | .dw 421 , 649 , 901 , 2607

188
189 ; === Valores de continua de correcci ón para cada rango de medici ón === 190 MEAS_RANGE_FLASH_CONTINUE_MUX2_VALUES :
191 | .db MUX2_x30nA , MUX2_x80nA , MUX2_x120nA , MUX2_x200nA

192
193 ; === Valor inicial de calibraci ón del PWM de Offset === 194 PWM_OFFSET_FLASH_CALIB_VALUE :
195 | .db 210 , 218 , 218 , 223

## 9.3.2. main.asm

1 # ifdef AVRA
2 | .nolist
3 | .include " m32def.inc "
4 | .list
5 # endif

6
7
8 .include " configs.asm "
9 .include " pwm.asm "
10 .include " adc.asm "
11 .include " measure_routines.asm " 12 .include " MEDIR.asm "
13 .include " BCD.asm "
14 .include " LCD.asm "
15 .include " MENU.asm "
16 .include " CORREGIR_FIN.asm "

17
18
19 ; ||||||||||||||||||||||||||||||||||||||||||||||||||||||||||||||||||||||||||||||; 20 ; |||||||||||||||||||||||||||||||||||| Main ||||||||||||||||||||||||||||||||||||; 21 ; ||||||||||||||||||||||||||||||||||||||||||||||||||||||||||||||||||||||||||||||;
22 MAIN :
23 | ldi | tmp , HIGH ( RAMEND )
24 | out | SPH , tmp
25 | ldi | tmp , LOW ( RAMEND )
26 | out | SPL , tmp | ; Stack pointer
27 | sei | ; Habilita las interrupciones ( global )

28
29 ; ------------------------ Configuraci ón de los puertos -- ----- ----- ---- ----- ---;
30 ;
31 ; | PA0 --> RS | | | PC0 --> D0 | |
32 ; | PA1 --> R/W | LCD | PC1 --> D1 | |
33 ; | PA2 --> E | | | PC2 --> D2 | |
34 ; | PA3 <-- ButtonLeft | PC3 --> D3 | | LCD
35 ; | PA4 <-- ButtonRight | PC4 --> D4 | |
36 ; | PA5 <-- ButtonOk | PC5 --> D5 | |
37 ; | PA6 <== ADC : ImpedanceMeasure | PC6 --> D6 | |
38 ; | PA7 <== ADC : OffsetCalibration | PC7 --> D7 | |

39 ;
40 ;
41 ; | PB0 --> A | | MUX2 | PD0 --> S0 | |
42 ; | PB1 --> B | | | PD1 --> S1 | | MUX1
43 ; | PB2 <== INT2 : ButtonEsc | PD2 --> S2 | |
44 ; | PB3 == > OC0 : PWMSineWave | PD3 --> S3 | |
45 ; | PB4 --> S0 | | | PD4 * Unused *
46 ; | PB5 --> S1 | | MUX0 | PD5 * Unused *
47 ; | PB6 --> S2 | | | PD6 * Unused *
48 ; | PB7 --> S3 | | | PD7 == > OC2 : PWMOffsetAdjust

49 ;
50 | ; Salidas y entradas

51 | ldi | tmp ,0 b00000111
52 | out | DDRA , tmp
53 | ldi | tmp ,0 b11111011
54 | out | DDRB , tmp
55 | ldi | tmp ,0 b11111111
56 | out | DDRC , tmp
57 | ldi | tmp ,0 b10001111
58 | out | DDRD , tmp

59
60 | ; Resistencias pull -up
61 | ldi | tmp ,0 b00111000
62 | out | PORTA , tmp
63 | ldi | tmp ,0 b00000100
64 | out | PORTB , tmp
65 | ldi | tmp ,0 b01110000
66 | out | PORTD , tmp

67
68 | ; Interrupci ón de escape
69 | ldi | tmp ,(1 < < INT2 ) ; Interrupci ón INT2 ( flanco descendente por defecto )
70 | out | GICR , tmp

71
72 ; - ----- ---- ----- ----- ---- ----- ----- ---- ----- ----- ---- ----- ----- ---- ----- ----- --;
73 | jmp | MENU

74
75 | rjmp | MAIN ; Si se llega hasta aqu í por error , se comienza de nuevo

76
77
78 ; |//////////////////////////////////////|\\\\\\\\\\\\\\\\\\\\\\\\\\\\\\\\\\\\\|; 79 ; |////////////////////////| Delay de 50 milisegundos |\\\\\\\\\\\\\\\\\\\\\\\\|; 80 ; |//////////////////////////////////////|\\\\\\\\\\\\\\\\\\\\\\\\\\\\\\\\\\\\\|;

81 ;
82 ; Utiliza el Timer1. Solo usa el registro temporal , este nunca se salva.
83 ;
84 DELAY_50ms :
85 | ldi | tmp , HIGH ( TIMER1_50ms_DELAY_START )
86 | out | TCNT1H , tmp
87 | ldi | tmp , LOW ( TIMER1_50ms_DELAY_START )
88 | out | TCNT1L , tmp | ; Carga del contador del Timer1

89
90 | ldi | tmp , TIMER1_CLOCK_64_PRESCALER
91 | out | TCCR1B , tmp | ; Activaci ón del Timer1

92
93 keep_waiting :
94 | in | tmp , TIFR
95 | sbrs | tmp , TOV1 | ; Saltea si el flag de overflow está encendido
96 | rjmp | keep_waiting

97
98 | ldi | tmp , TIMER1_OFF
99 | out | TCCR1B , tmp | ; Desactivaci ón del Timer1
100 | ldi | tmp ,(1 < < TOV1 )
101 | out | TIFR , tmp | ; Borrado del flag de overflow

102
103 | ret

104
105
106 ; |//////////////////////////////////////|\\\\\\\\\\\\\\\\\\\\\\\\\\\\\\\\\\\\\|; 107 ; |///////////////////////| Delay en segundos (1 a 255) |\\\\\\\\\\\\\\\\\\\\\\|; 108 ; |//////////////////////////////////////|\\\\\\\\\\\\\\\\\\\\\\\\\\\\\\\\\\\\\|;

109 ;
110 ; param ( R17 ) <- cantidad de segundos , 1 < param < 255
111 ; Utiliza la rutina de delay de 50 ms. Salva todos los registros que arruina.
112 ;
113 DELAY_PARAM_SECONDS :
114 | push | iter
115 | push | iter2 ; Registros salvados en el stack

116
117 | mov | iter , param ; Contador de segundos , se carga con el par á metro
118 loop_1s :
119 | ldi | iter2 ,20 | ; Contador de 50 milisegundos : 20 * 50 ms = 1000 ms = 1 s
120 loop_50ms :

121 | rcall | DELAY_50ms
122 | dec | iter2 | ; Decremento del contador de 50 milisegundos
123 | brne | loop_50ms | ; Si se contaron 20 vueltas de 50 ms se deja de repetir
124 | dec | iter | ; Decremento del contador de segundos
125 | brne | loop_1s | ; Si se contaron 60 vueltas de 1 s se deja de repetir

126
127 | pop | iter2
128 | pop | iter | ; Registros recuperados del stack
129 | ret

## 9.3.3. MENU.asm

1 INT2_ESC_BUTTON_ISR :
2 | POP R16
3 | POP R16
4 | SEI | ; Deshace los cambios de la llamada a la interrupci ón y contin úa hacia
MENU

5
6 MENU :
7 | LDI param , MEAS_RANGE_4
8 | CALL PWM_SINE_STOP | ; Se inicializa el PWM de senoidal
9 | CALL PWM_OFFSET_START ; Se inicializa la referencia del OpAmp

10
11 | ; Se limpia la RAM de pantalla LCD
12 | LDI R16 ,80
13 | LDI ZH , HIGH ( BCD_TO_ASCII_CONVERT_RAM )
14 | LDI ZL , LOW ( BCD_TO_ASCII_CONVERT_RAM )
15 | LDI R17 ,'*'
16 LCD_RAM_INIT :
17 | ST Z+ , R17
18 | DEC R16
19 | BRNE LCD_RAM_INIT
20 | CALL LCD_INIT

21
22 MED :
23 | LDI R16 , 0 X01
24 | CALL CMNDWRT | ; Pone el cursor al principio de la 1ra lí nea
25 | CALL DELAY_1_6ms

26
27
28 | LDI R16 ,'M'
29 | CALL DATAWRT
30 | LDI R16 ,'E'
31 | CALL DATAWRT
32 | LDI R16 ,'D'
33 | CALL DATAWRT
34 | LDI R16 ,'I'
35 | CALL DATAWRT
36 | LDI R16 ,'R'
37 | CALL DATAWRT
38 | LDI R16 ,' '
39 | CALL DATAWRT
40 | LDI R16 ,' '
41 | CALL DATAWRT
42 | LDI R16 ,' '
43 | CALL DATAWRT
44 | LDI R16 ,'O'
45 | CALL DATAWRT
46 | LDI R16 ,'K'
47 | CALL DATAWRT

48
49
50 | LDI R16 , $C0
51 | CALL CMNDWRT

52
53 | LDI R16 ,60
54 | CALL DATAWRT
55 | LDI R16 ,62
56 | CALL DATAWRT

57
58 BOTONES :

59
60 | IN R17 , PINA
61 | BST R17 ,3
62 | BRTC CALIBRAR_1
63 | BST R17 ,4
64 | BRTC CORREGIR_JMP
65 | BST R17 ,5
66 | BRTC MEDIR_JMP

67
68 JMP BOTONES

69
70 MEDIR_JMP :
71 | JMP MEDIR_MENU

72
73 CORREGIR_JMP :
74 | JMP CORREGIR_1

75
76 CALIBRAR_1 :
77 | LDI R16 , 0 X01
78 | CALL CMNDWRT | ; Pone el cursor al principio de la 1ra lí nea
79 | CALL DELAY_1_6ms

80
81
82 | LDI R16 ,'C'
83 | CALL DATAWRT
84 | LDI R16 ,'A'
85 | CALL DATAWRT
86 | LDI R16 ,'L'
87 | CALL DATAWRT
88 | LDI R16 ,'I'
89 | CALL DATAWRT
90 | LDI R16 ,'B'
91 | CALL DATAWRT
92 | LDI R16 ,'R'
93 | CALL DATAWRT
94 | LDI R16 ,'A'
95 | CALL DATAWRT
96 | LDI R16 ,'R'
97 | CALL DATAWRT
98 | LDI R16 ,' '
99 | CALL DATAWRT
100 | LDI R16 ,' '
101 | CALL DATAWRT
102 | LDI R16 ,' '
103 | CALL DATAWRT
104 | LDI R16 ,'O'
105 | CALL DATAWRT
106 | LDI R16 ,'K'
107 | CALL DATAWRT

108
109
110 | LDI R16 , $C0
111 | CALL CMNDWRT

112
113 | LDI R16 ,60
114 | CALL DATAWRT
115 | LDI R16 ,62
116 | CALL DATAWRT

117
118 | CALL DELAY_50ms
119 BOT :
120 | IN R17 , PINA
121 | BST R17 ,3
122 | BRTC CORREGIR_1
123 | BST R17 ,4
124 | BRTC MED_JMP
125 | BST R17 ,5
126 | BRTC CALIBRAR_JMP

127 JMP BOT

128
129 CALIBRAR_JMP :
130 | JMP CALIBRAR

131
132 MED_JMP :
133 | JMP MED

134
135
136 MEDIR_MENU :
137 | CALL MEDIR
138 | JMP RESULTADOS_INIC
139 | RET

140
141 CALIBRAR :
142 | RJMP CALIBRAR

143
144 CORREGIR_1 :
145 | LDI R16 , 0 X01
146 | CALL CMNDWRT | ; Pone el cursor al principio de la 1ra lí nea
147 | CALL DELAY_1_6ms

148
149
150 | LDI R16 ,'C'
151 | CALL DATAWRT
152 | LDI R16 ,'O'
153 | CALL DATAWRT
154 | LDI R16 ,'R'
155 | CALL DATAWRT
156 | LDI R16 ,'R'
157 | CALL DATAWRT
158 | LDI R16 ,'E'
159 | CALL DATAWRT
160 | LDI R16 ,'G'
161 | CALL DATAWRT
162 | LDI R16 ,'I'
163 | CALL DATAWRT
164 | LDI R16 ,'R'
165 | CALL DATAWRT
166 | LDI R16 ,' '
167 | CALL DATAWRT
168 | LDI R16 ,' '
169 | CALL DATAWRT
170 | LDI R16 ,' '
171 | CALL DATAWRT
172 | LDI R16 ,'O'
173 | CALL DATAWRT
174 | LDI R16 ,'K'
175 | CALL DATAWRT

176
177
178 | LDI R16 , $C0
179 | CALL CMNDWRT

180
181 | LDI R16 ,60
182 | CALL DATAWRT
183 | LDI R16 ,62
184 | CALL DATAWRT

185
186 | CALL DELAY_50ms
187 BOT2 :
188 | IN R17 , PINA
189 | BST R17 ,3
190 | BRTC MED_JMP1
191 | BST R17 ,4
192 | BRTC CALIBRAR_JMP1
193 | BST R17 ,5
194 | BRTC CORREGIR
195 JMP BOT2

196

197 MED_JMP1 :
198 | JMP MED

199
200 CALIBRAR_JMP1 :
201 | JMP CALIBRAR_1

202
203 CORREGIR :
204 | LDI R22 , 0
205 | LDI R16 , 0 X01
206 | CALL CMNDWRT
207 | CALL DELAY_1_6ms

208
209 | LDI R16 ,'I'
210 | CALL DATAWRT
211 | LDI R16 ,'M'
212 | CALL DATAWRT
213 | LDI R16 ,'P'
214 | CALL DATAWRT
215 | LDI R16 ,'E'
216 | CALL DATAWRT
217 | LDI R16 ,'D'
218 | CALL DATAWRT
219 | LDI R16 ,'A'
220 | CALL DATAWRT
221 | LDI R16 ,'N'
222 | CALL DATAWRT
223 | LDI R16 ,'C'
224 | CALL DATAWRT
225 | LDI R16 ,'I'
226 | CALL DATAWRT
227 | LDI R16 ,'A'
228 | CALL DATAWRT

229
230 | LDI R16 , $C0
231 | CALL CMNDWRT

232
233 | LDI R16 ,0 X30
234 | CALL DATAWRT
235 | LDI R16 ,0 X30
236 | CALL DATAWRT
237 | LDI R16 ,'k'
238 | CALL DATAWRT
239 | LDI R16 ,'O'
240 | CALL DATAWRT
241 | LDI R16 ,'h'
242 | CALL DATAWRT
243 | LDI R16 ,'m'
244 | CALL DATAWRT

245
246 | CALL DELAY_50ms

247
248 | LDI R20 ,0
249 | LDI R21 ,0

250
251 BOTONES_2 :
252 | IN R17 ,PINA
253 | BST R17 ,3 | ; Pin 3 del puerto A ( AUMENTAR )
254 | BRTC AUMENTAR
255 | BST R17 ,4 | ; Pin 4 del puerto A ( REDUCIR )
256 | BRTC REDUCIR_OK
257 | BST R17 ,5 | ; PIN 5 DEL PUERTO A (OK)
258 | BRTC TMAX_OK
259 JMP BOTONES_2

260
261 REDUCIR_OK :JMP REDUCIR ; CON EL BRANCH NO ALCANZA PARA SALTAR 262 TMAX_OK :JMP TMAX

263
264 AUMENTAR :
265 | INC R20
266 | CPI R20 ,10

267 | BRNE AUMENTAR_A
268 | INC R21
269 | LDI R20 ,0

270
271
272 AUMENTAR_A :

273
274 | CPI | R21 ,8 | ; DEJA HASTA 7 ,9 MOHM
275 | BRSH BOTONES_2

276
277 | LDI R16 , 0 X01
278 | CALL CMNDWRT
279 | CALL DELAY_1_6ms

280
281 | LDI R16 ,'I'
282 | CALL DATAWRT
283 | LDI R16 ,'M'
284 | CALL DATAWRT
285 | LDI R16 ,'P'
286 | CALL DATAWRT
287 | LDI R16 ,'E'
288 | CALL DATAWRT
289 | LDI R16 ,'D'
290 | CALL DATAWRT
291 | LDI R16 ,'A'
292 | CALL DATAWRT
293 | LDI R16 ,'N'
294 | CALL DATAWRT
295 | LDI R16 ,'C'
296 | CALL DATAWRT
297 | LDI R16 ,'I'
298 | CALL DATAWRT
299 | LDI R16 ,'A'
300 | CALL DATAWRT

301
302 | LDI R16 , $C0
303 | CALL CMNDWRT

304
305 | LDI R22 ,48 | ; PARA PASAR A ASCII
306 | ADD R21 , R22
307 | ADD R20 , R22

308
309 | MOV R16 , R21
310 | CALL DATAWRT
311 | MOV R16 , R20
312 | CALL DATAWRT
313 | LDI R16 ,'k'
314 | CALL DATAWRT
315 | LDI R16 ,'O'
316 | CALL DATAWRT
317 | LDI R16 ,'h'
318 | CALL DATAWRT
319 | LDI R16 ,'m'
320 | CALL DATAWRT

321
322 | SUB R21 , R22 | ; VUELVO A LA VARIABLE
323 | SUB R20 , R22

324
325 | CALL DELAY_50ms
326 | CALL DELAY_50ms

327
328 | JMP BOTONES_2

329
330 REDUCIR :
331 | CPI R20 ,0
332 | BREQ REDUCIR_B
333 | DEC R20
334 | JMP REDUCIR_A
335 REDUCIR_B :
336 | CPI R21 ,0

337 | BREQ SALIDA
338 | DEC R21
339 | LDI R20 ,9
340 | JMP REDUCIR_A
341 SALIDA :
342 | JMP BOTONES_2

343
344
345
346 REDUCIR_A :

347
348 | LDI R16 , 0 X01
349 | CALL CMNDWRT
350 | CALL DELAY_1_6ms

351
352 | LDI R16 ,'I'
353 | CALL DATAWRT
354 | LDI R16 ,'M'
355 | CALL DATAWRT
356 | LDI R16 ,'P'
357 | CALL DATAWRT
358 | LDI R16 ,'E'
359 | CALL DATAWRT
360 | LDI R16 ,'D'
361 | CALL DATAWRT
362 | LDI R16 ,'A'
363 | CALL DATAWRT
364 | LDI R16 ,'N'
365 | CALL DATAWRT
366 | LDI R16 ,'C'
367 | CALL DATAWRT
368 | LDI R16 ,'I'
369 | CALL DATAWRT
370 | LDI R16 ,'A'
371 | CALL DATAWRT

372
373 | LDI R16 , $C0
374 | CALL CMNDWRT

375
376 | LDI R22 ,48 | ; PARA PASAR A ASCII
377 | ADD R21 , R22
378 | ADD R20 , R22

379
380 | MOV R16 , R21 | ; CAMBIAR
381 | CALL DATAWRT
382 | MOV R16 , R20 | ; CAMBIAR
383 | CALL DATAWRT
384 | LDI R16 ,'k'
385 | CALL DATAWRT
386 | LDI R16 ,'O'
387 | CALL DATAWRT
388 | LDI R16 ,'h'
389 | CALL DATAWRT
390 | LDI R16 ,'m'
391 | CALL DATAWRT

392
393 | SUB R21 , R22 | ; VUELVO A LA VARIABLE
394 | SUB R20 , R22

395
396 | CALL DELAY_50ms
397 | CALL DELAY_50ms

398
399 | JMP BOTONES_2

400
401 TMAX :
402 | LDI R16 , 0 X01
403 | CALL CMNDWRT
404 | CALL DELAY_1_6ms

405
406 | LDI R16 ,'T'

407 | CALL DATAWRT
408 | LDI R16 ,'M'
409 | CALL DATAWRT
410 | LDI R16 ,'A'
411 | CALL DATAWRT
412 | LDI R16 ,'X'
413 | CALL DATAWRT

414
415 | LDI R16 , $C0
416 | CALL CMNDWRT

417
418 | LDI R16 ,0 X30
419 | CALL DATAWRT
420 | LDI R16 ,0 X30
421 | CALL DATAWRT

422
423 | LDI R16 ,'M'
424 | CALL DATAWRT
425 | LDI R16 ,'I'
426 | CALL DATAWRT
427 | LDI R16 ,'N'
428 | CALL DATAWRT

429
430 | LDI R23 ,0
431 | LDI R22 ,48

432
433 | CALL DELAY_50ms

434
435
436 | BOTONES_3 :
437 | IN R17 ,PINA
438 | BST R17 ,3 | ;Pin 3 del puerto A ( AUMENTAR )
439 | BRTC AUMENTAR_T
440 | BST R17 ,4 | ;Pin 4 del puerto A ( REDUCIR )
441 | BRTC REDUCIR_T
442 | BST R17 ,5 | ;PIN 5 DEL PUERTO A (OK)
443 | BRTC FIN
444 | JMP BOTONES_3
445 | FIN :
446 | LDI R16 , 0 X01
447 | CALL CMNDWRT
448 | CALL DELAY_1_6ms

449
450 | LDI R16 ,'E'
451 | CALL DATAWRT
452 | LDI R16 ,'S'
453 | CALL DATAWRT
454 | LDI R16 ,'P'
455 | CALL DATAWRT
456 | LDI R16 ,'E'
457 | CALL DATAWRT
458 | LDI R16 ,'R'
459 | CALL DATAWRT
460 | LDI R16 ,'E'
461 | CALL DATAWRT
462 | LDI R16 ,'.'
463 | CALL DATAWRT
464 | LDI R16 ,'.'
465 | CALL DATAWRT
466 | LDI R16 ,'.'
467 | CALL DATAWRT
468 | JMP CORREGIR_ELECTRODO

469
470 | REDUCIR_T :

471
472 | CPI R23 ,0
473 | BRNE REDUCIR_TP
474 | JMP BOTONES_3

475
476

477 | AUMENTAR_T :
478 | CPI R23 ,9
479 | BRSH BOTONES_3
480 | INC R23

481
482
483 | AUMENTAR_TP :

484
485 | LDI R16 , 0 X01
486 | CALL CMNDWRT
487 | CALL DELAY_1_6ms

488
489 | LDI R16 ,'T'
490 | CALL DATAWRT
491 | LDI R16 ,'M'
492 | CALL DATAWRT
493 | LDI R16 ,'A'
494 | CALL DATAWRT
495 | LDI R16 ,'X'
496 | CALL DATAWRT

497
498 | LDI R16 , $C0
499 | CALL CMNDWRT

500
501 | ADD R23 , R22

502
503 | MOV R16 , R23
504 | CALL DATAWRT
505 | LDI R16 ,0 X30
506 | CALL DATAWRT

507
508 | LDI R16 ,'M'
509 | CALL DATAWRT
510 | LDI R16 ,'I'
511 | CALL DATAWRT
512 | LDI R16 ,'N'
513 | CALL DATAWRT

514
515 | SUB R23 , R22

516
517 | CALL DELAY_50ms

518
519 | JMP BOTONES_3

520
521
522 | REDUCIR_TP :

523
524 | DEC R23
525 | LDI R16 , 0 X01
526 | CALL CMNDWRT
527 | CALL DELAY_1_6ms

528
529 | LDI R16 ,'T'
530 | CALL DATAWRT
531 | LDI R16 ,'M'
532 | CALL DATAWRT
533 | LDI R16 ,'A'
534 | CALL DATAWRT
535 | LDI R16 ,'X'
536 | CALL DATAWRT

537
538 | LDI R16 , $C0
539 | CALL CMNDWRT

540
541 | ADD R23 , R22

542
543 | MOV R16 , R23
544 | CALL DATAWRT
545 | LDI R16 ,'0'
546 | CALL DATAWRT

547
548 | LDI R16 ,'M'
549 | CALL DATAWRT
550 | LDI R16 ,'I'
551 | CALL DATAWRT
552 | LDI R16 ,'N'
553 | CALL DATAWRT

554
555 | SUB R23 , R22

556
557 | CALL DELAY_50ms

558
559 | JMP BOTONES_3

560
561
562
563
564 | FIN2 : RJMP FIN2

565
566 | ;
| ***************************************************************************************************************************

567
568 | LCD_INIT :
569 | CBI PORTA ,2
570 | CALL DELAY_50ms
571 | LDI R16 ,0 X38
572 | CALL CMNDWRT
573 | LDI R16 ,0 X0E
574 | CALL CMNDWRT
575 | LDI R16 ,0 X01
576 | CALL CMNDWRT
577 | CALL DELAY_50ms
578 | LDI R16 ,0 X06
579 | CALL CMNDWRT
580 | RET

581
582 | ;
| **********************************************************************************************************************************

583
584 | DELAY_40ms :
585 | | LDI R17 ,25
586 | DR2 :
587 | | CALL DELAY_1_6ms
588 | | DEC R17
589 | | BRNE DR2
590 | | RET

591
592 | ;
| | *********************************************************************************************************************************
593 | DELAY_1_6ms :
594 | | PUSH R17
595 | | LDI R17 ,16
596 | DR1 :
597 | CALL DELAY_100us
598 | DEC R17
599 | BRNE DR1
600 | POP R17
601 | RET

602
603 | ;
| | ********************************************************************************************************************************
604 | DELAY_100us :
605 | | PUSH R17
606 | | LDI R17 ,13
607 | DR0 : | CALL SDELAY
608 | DEC R17

609 | BRNE DR0
610 | POP R17
611 | RET

612
613 | ;
| **************************************************************************************************************************

614
615 | SDELAY :
616 | NOP
617 | NOP
618 | RET

619
620 | ;
| **************************************************************************************************************************
621 | CMNDWRT :
622 | OUT PORTC , R16
623 | CBI PORTA ,0
624 | CBI PORTA ,1
625 | SBI PORTA ,2
626 | CALL DELAY_100us
627 | CBI PORTA ,2
628 | CALL DELAY_50ms
629 | RET
630 | ;
| *************************************************************************************************************************
631 | DATAWRT :
632 | OUT PORTC , R16
633 | SBI PORTA ,0
634 | CBI PORTA ,1
635 | SBI PORTA ,2
636 | CALL DELAY_100us
637 | CBI PORTA ,2
638 | CALL DELAY_50ms
639 | RET

## 9.3.4. MEDIR.asm

1 MEDIR :
2 | ldi | param , MEAS_RANGE_4
3 | call | PWM_OFFSET_START

4
5 medir_gral :
6 | call | PWM_SINE_START
7 | call | DELAY_50ms
8 | call | ADC_SAMPLING_TO_RAM_FROM_IMPEDANCE_MEASURE_IN
9 | call | PWM_SINE_STOP
10 | call | GET_THE_PEAK_VALUE_IN_R2_FROM_ADC_RAM_TABLE
11 | call | GET_DECIMEG_IMPEDANCE_FROM_PARAM_RANGE_R2_PEAK_VALUE_IN_R1_R0

12
13 | ldi | ZH , HIGH ( MEAS_RANGE_FLASH_FLOOR_VALUES < <1)
14 | ldi | ZL , LOW ( MEAS_RANGE_FLASH_FLOOR_VALUES < <1)

15
16 | mov | R2 , param
17 | lsl | R2 | ; R2 = param * 2
18 | clr | tmp
19 | add | ZL , R2 | ; Z = Z + param * 2
20 | adc | ZH , tmp | ; Actualizaci ón de la parte alta con el carry ( tmp = 0)

21
22 | lpm | R2 ,Z+ ; Lectura del par á metro P desde flash , little - endian (L)
23 | lpm | R3 ,Z | ; Lectura del par á metro P desde flash , little - endian (H)

24
25 | cp | R0 , R2 | ; Comparaci ón, parte baja
26 | cpc | R1 , R3 | ; Comparaci ón, parte alta
27 | brsh | medir_listo ; Si R1:R0 ( medici ón actual ) >= R3:R2 ( piso de rango )
28 | dec | param | ; Si no , paso a un rango más bajo
29 | brne | medir_gral | ; Repetir medici ón

30
31 medir_listo :
32 | call | BCD
33 | ret

## 9.3.5. CORREGIR FIN.asm

1 CORREGIR_ELECTRODO :
2 | ; R21 -> R11 Tiene las decenas de la impedancia en kohms
3 | ; R20 -> R10 Tiene la unidad de la impedancia en kohms
4 | ; R23 -> R12 Tiene TMAX en cantidades de a 10 min

5
6 | clr | iter | ; iterador de la cantidad de minutos de correcci ón
7 | mov | R10 , R20 ; copia hacia registros no utilizados por las rutinas
8 | mov | R11 , R21 ; copia hacia registros no utilizados por las rutinas
9 | mov | R12 , R23 ; copia hacia registros no utilizados por las rutinas

10
11 continuar_corrigiendo :
12 | ; Se mide para saber en qué rango corregir ( queda en param )
13 | ; o si no es necesario hacerlo ( medici ón en R1:R0)
14 | call | MEDIR

15
16 | ; Se copia la impedancia medida hacia R3:R2
17 | mov | R3 , R1
18 | mov | R2 , R0

19
20 | ; Verificaci ón de la impedancia
21 | ldi | tmp ,10
22 | mul | tmp , R11 ; R1:R0 <- Decenas de la impedancia en kohms * 10
23 | add | R0 , R10 | ; R1:R0 <- R1:R0 + Unidad de la impedancia en kohms
24 | clr | tmp
25 | adc | R1 , tmp | ; Suma del carry a la parte alta (ya que tmp = 0)

26
27 | ; R1:R0 <- valor de impedancia deseada que se comparar á con R3:R2 ( medida )
28 | cp | R0 , R2
29 | cpc | R1 , R3
30 | brsh | final_correccion ; Si R1:R0 ( deseada ) >= R3:R2 ( medida )

31
32 | call | PWM_CONTINUE_CORRECTION_START
33 | ldi | param ,60
34 | call | DELAY_PARAM_SECONDS
35 | inc | iter

36
37 | ; Verificaci ón de TMAX
38 | ldi | tmp ,10
39 | mul | tmp , R12 ; R1:R0 <- TMAX en minutos , como es < 90 , sólo interesa R0
40 | ; Aquí: R0 = TMAX ; iter = TACTUAL (en minutos )
41 | cp | iter , R0
42 | brsh | final_correccion ; Si iter >= R0 , se ha cumplido el tiempo má ximo

43
44 | rjmp | continuar_corrigiendo

45
46 final_correccion :
47 | call | PWM_SINE_STOP
48 | call | DELAY_50ms
49 | call | MEDIR
50 | jmp | RESULTADOS_INIC

## 9.3.6. BCD.asm

1
2 | BCD :

3
4 | LDI ZH , HIGH ( BCD_TO_ASCII_CONVERT_RAM )
5 | LDI ZL , LOW ( BCD_TO_ASCII_CONVERT_RAM )
6 | .def rBin1H = r1 | ; REGISTROS MULTIPLICACION
7 | .def rBin1L = r0
8 | .def rBin2H = r19

9 | .def rBin2L = r20
10 | .def rmp = r18

11
12
13 | Bin2ToAsc5 :
14 | rcall Bin2ToBcd5
15 | ldi rmp ,4
16 | mov rBin2L , rmp
17 Bin2ToAsc5a :
18 | ld rmp ,z
19 | tst rmp
20 | brne Bin2ToAsc5b
21 | ldi rmp ,' '
22 | st z+ , rmp
23 | dec rBin2L
24 | brne Bin2ToAsc5a
25 | ld rmp ,z
26 Bin2ToAsc5b :
27 | inc rBin2L
28 Bin2ToAsc5c :
29 | subi rmp ,-'0'
30 | st z+ , rmp
31 | ld rmp ,z
32 | dec rBin2L ;
33 | brne Bin2ToAsc5c
34 | sbiw ZL ,5 ; DIRECCI ÓN FINAL
35 | ret

36
37
38
39 | Bin2ToBcd5 :
40 | push rBin1H
41 | push rBin1L
42 | ldi rmp , HIGH (10000)
43 | mov rBin2H , rmp
44 | ldi rmp , LOW (10000)
45 | mov rBin2L , rmp
46 | rcall Bin2ToDigit
47 | ldi rmp , HIGH (1000)
48 | mov rBin2H , rmp
49 | ldi rmp , LOW (1000)
50 | mov rBin2L , rmp
51 | rcall Bin2ToDigit
52 | ldi rmp , HIGH (100)
53 | mov rBin2H , rmp
54 | ldi rmp , LOW (100)
55 | mov rBin2L , rmp
56 | rcall Bin2ToDigit
57 | ldi rmp , HIGH (10)
58 | mov rBin2H , rmp
59 | ldi rmp , LOW (10)
60 | mov rBin2L , rmp
61 | rcall Bin2ToDigit
62 | st z , rBin1L
63 | sbiw ZL ,4
64 | pop rBin1L
65 | pop rBin1H
66 | ret

67
68
69 Bin2ToDigit :
70 | clr rmp
71 Bin2ToDigita :
72 | cp rBin1H , rBin2H
73 | brcs Bin2ToDigitc
74 | brne Bin2ToDigitb
75 | cp rBin1L , rBin2L
76 | brcs Bin2ToDigitc
77 Bin2ToDigitb :
78 | sub rBin1L , rBin2L

79 | sbc rBin1H , rBin2H
80 | inc rmp
81 | rjmp Bin2ToDigita
82 Bin2ToDigitc :
83 | st z+ , rmp
84 | ret

## 9.3.7. LCD.asm

1
2
3 RESULTADOS_INIC :
4 | LDI R19 ,1 ; Electrodo 1
5 | LDI ZH , HIGH ( BCD_TO_ASCII_CONVERT_RAM )
6 | LDI ZL , LOW ( BCD_TO_ASCII_CONVERT_RAM )
7 | LDI R22 ,48

8
9
10 RESULTADOS :

11
12 | CALL LCD_INIT ; Funcion para inicializar la LCD
13 | MOV R21 , R19

14
15 | CPI R21 ,10
16 | BRLO RESULTADOS_1

17
18 | DIEZ : JMP DIEZ_I

19
20 RESULTADOS_1 :

21
22 | ADD R19 , R22
23 | LDI R16 ,'E'
24 | CALL DATAWRT
25 | LDI R16 ,'l'
26 | CALL DATAWRT
27 | LDI R16 ,'e'
28 | CALL DATAWRT
29 | LDI R16 ,'c'
30 | CALL DATAWRT
31 | LDI R16 ,'t'
32 | CALL DATAWRT
33 | LDI R16 ,'r'
34 | CALL DATAWRT
35 | LDI R16 ,'o'
36 | CALL DATAWRT
37 | LDI R16 ,'d'
38 | CALL DATAWRT
39 | LDI R16 ,'o'
40 | CALL DATAWRT
41 | LDI R16 ,' '
42 | CALL DATAWRT
43 | MOV R16 , R19 | ;El numero del electrodo (1 ,2 , ..16 )
44 | CALL DATAWRT
45 | LDI R16 , $C0 | ; Esto hay que revisarlo , es para bajar a la segunda linea del
| LCD
46 | CALL CMNDWRT
47 | LD R16 ,Z+ | ;El resultado de la correcci ón
48 | CALL DATAWRT
49 | LD R16 ,Z+ | ;El resultado de la correcci ón
50 | CALL DATAWRT
51 | LD R16 ,Z+ | ;El resultado de la correcci ón
52 | CALL DATAWRT
53 | LD R16 ,Z+ | ;El resultado de la correcci ón
54 | CALL DATAWRT
55 | LD R16 ,Z | ;El resultado de la correcci ón
56 | CALL DATAWRT
57 | LDI R16 ,'k'
58 | CALL DATAWRT
59 | LDI R16 ,'O'

60 | CALL DATAWRT
61 | LDI R16 ,'h'
62 | CALL DATAWRT
63 | LDI R16 ,'m'
64 | CALL DATAWRT
65 | SUB R19 , R22

66
67 | LDI R16 ,0 X0F
68 | CALL CMNDWRT

69
70 | CALL DELAY_50ms

71
72
73 BOTONES_4 :
74 | IN R17 , PINA
75 | BST R17 ,3 | ;Pin 3 del puerto A ( AUMENTAR )
76 | BRTC SUBIR
77 | BST R17 ,4 | ;Pin 4 del puerto A ( REDUCIR )
78 | BRTC BAJAR
79 JMP BOTONES_4

80
81 SUBIR :
82 | ADIW ZL ,1 ; Avanza el puntero
83 | INC R19
84 | CPI R19 ,17 ;Si se pasa del 16 , vuelve al 1
85 | BREQ PRIMERO
86 | JMP RESULTADOS
87 PRIMERO :
88 | LDI R19 ,16
89 | SBIW ZL ,1
90 | JMP BOTONES_4
91 BAJAR :
92 | DEC R19
93 | CPI R19 ,0 | ; Si se pasa del 1, vuelve al 16
94 | BREQ ULTIMO
95 | SBIW ZL ,9 | ; Retrocede el puntero
96 | JMP RESULTADOS
97 ULTIMO :
98 | LDI R19 ,1
99 | LDI ZH , HIGH ( BCD_TO_ASCII_CONVERT_RAM )
100 | LDI ZL , LOW ( BCD_TO_ASCII_CONVERT_RAM )
101 | LDI R16 , 0 X01
102 | CALL CMNDWRT | ; Pone el cursor al principio de la 1ra lí nea
103 | CALL DELAY_1_6ms
104 | JMP RESULTADOS_1

105
106
107 DIEZ_I :
108 | SUBI R21 ,10
109 | ADD R21 , R22

110
111 | LDI R16 ,'E'
112 | CALL DATAWRT
113 | LDI R16 ,'l'
114 | CALL DATAWRT
115 | LDI R16 ,'e'
116 | CALL DATAWRT
117 | LDI R16 ,'c'
118 | CALL DATAWRT
119 | LDI R16 ,'t'
120 | CALL DATAWRT
121 | LDI R16 ,'r'
122 | CALL DATAWRT
123 | LDI R16 ,'o'
124 | CALL DATAWRT
125 | LDI R16 ,'d'
126 | CALL DATAWRT
127 | LDI R16 ,'o'
128 | CALL DATAWRT
129 | LDI R16 ,' '

130 | CALL DATAWRT
131 | LDI R16 ,0 x31
132 | CALL DATAWRT
133 | MOV R16 , R21 | ;El numero del electrodo (1 ,2 , ..16 )
134 | CALL DATAWRT
135 | LDI R16 , $C0 | ; Esto hay que revisarlo , es para bajar a la segunda linea del
LCD
136 | CALL CMNDWRT
137 | | LD R16 ,Z+ | ;El resultado de la correcci ón
138 | CALL DATAWRT
139 | | LD R16 ,Z+ | ;El resultado de la correcci ón
140 | CALL DATAWRT
141 | | LD R16 ,Z+ | ;El resultado de la correcci ón
142 | CALL DATAWRT
143 | | LD R16 ,Z+ | ;El resultado de la correcci ón
144 | CALL DATAWRT
145 | | LD R16 ,Z | ;El resultado de la correcci ón
146 | CALL DATAWRT
147 | LDI R16 ,'k'
148 | CALL DATAWRT
149 | LDI R16 ,'O'
150 | CALL DATAWRT
151 | LDI R16 ,'h'
152 | CALL DATAWRT
153 | LDI R16 ,'m'
154 | CALL DATAWRT

155
156 | SUB R21 , R22 | ; VUELVO A LA VARIABLE

157
158
159 | LDI R16 ,0 X0F
160 | CALL CMNDWRT

161
162 | CALL DELAY_50ms

163
164
165 | JMP BOTONES_4

## 9.3.8. pwm.asm

1 ; ||||||||||||||||||||||||||||||||||||||||||||||||||||||||||||||||||||||||||||||;
2 ; ||||||||| Interrupci ón de actualizaci ón del ciclo de trabajo del PWM |||||||||; 3 ; ||||||||||||||||||||||||||||||||||||||||||||||||||||||||||||||||||||||||||||||;
4 PWM_DUTY_CYCLE_UPDATE_ISR :
5 | push | tmp ; En una interrupci ón hay que salvar el registro temporal
6 | in | tmp , SREG
7 | push | tmp ; Tambi én hay que salvar el status register

8
9 | ld | tmp , X+ | ; Pró ximo valor del ciclo de trabajo desde RAM
10 | out | OCR0 , tmp | ; Valor actualizado de ciclo de trabajo
11 | dec | tbl_i | ; Decremento del iterador de la tabla en RAM
12 | brne | skip_go_beginning ; Saltea si tbl_i no es cero
13 | ; Go beginning
14 | rcall | SINE_RAM_TABLE_GO_BEGINNING
15 skip_go_beginning :
16 | pop | tmp
17 | out | SREG , tmp ; Se recupera el status register
18 | pop | tmp ; Se recupera el registro temporal
19 | reti

20
21
22 ; |//////////////////////////////////////|\\\\\\\\\\\\\\\\\\\\\\\\\\\\\\\\\\\\\|;
23 ; |///| Apuntado de la tabla del seno en RAM e inicializaci ón del contador |\\\|; 24 ; |//////////////////////////////////////|\\\\\\\\\\\\\\\\\\\\\\\\\\\\\\\\\\\\\|;

25 ;
26 ; NOTA : tbl_i ( R18 ) y X ( R27 : R26 ) siempre en uso.

27 ;
28 SINE_RAM_TABLE_GO_BEGINNING :
29 | ldi | XH , HIGH ( PWM_SINE_RAM_TABLE )

30 | ldi | XL , LOW ( PWM_SINE_RAM_TABLE ) ; Tabla de onda escalada en RAM
31 | ldi | tbl_i , PWM_SINE_TABLE_LEN | ; Iterador de la tabla en RAM
32 | ret

33
34
35 ; |//////////////////////////////////////|\\\\\\\\\\\\\\\\\\\\\\\\\\\\\\\\\\\\\|; 36 ; |///////////////////////| Carga de la tabla del seno |\\\\\\\\\\\\\\\\\\\\\\\|; 37 ; |//////////////////////////////////////|\\\\\\\\\\\\\\\\\\\\\\\\\\\\\\\\\\\\\|;

38 ;
39 ; param ( R17 ) <- escalado de amplitud x 128 , ejemplo : 25 % = 32/128 = > param = 32 40 ; Al finalizar la tabla estar á cargada en PWM_SINE_RAM_TABLE , escalada por
41 ; param /128 y con un valor medio de PWM_SINE_MEDIAN. Salva todos los registros 42 ; que arruina.
43 ;
44 LOAD_SINE_RAM_TABLE_SCALED :
45 | push | R0
46 | push | R1
47 | push | tbl_i
48 | push | ZH
49 | push | ZL
50 | push | XH
51 | push | XL ; Registros salvados en el stack

52
53 | ldi | ZH , HIGH ( PWM_SINE_FLASH_TABLE < <1)
54 | ldi | ZL , LOW ( PWM_SINE_FLASH_TABLE < <1) ; Inicializaci ón de puntero en flash
55 | rcall | SINE_RAM_TABLE_GO_BEGINNING ; Carga el puntero X y el contador tbl_i

56
57 loop_sine_table :
58 | lpm | tmp , Z+ | ; Lectura desde flash , del sample original
59 | mulsu | tmp , param ; Sample escalado y multiplicado x 128 en R1:R0
60 | rol | R0 ;> Divisi ón por 128: se multiplica por 2 el entero de 16 bits
61 | rol | R1 ;> con shifts y luego se divide por 256 qued á ndose con R1 ( MSB )
62 | ldi | tmp , PWM_SINE_MEDIAN
63 | add | R1 , tmp | ; En R1 queda el sample más la media
64 | st | X+, R1 | ; Carga en RAM del sample final
65 | dec | tbl_i | ; Decremento del contador
66 | brne | loop_sine_table

67
68 | pop | XL
69 | pop | XH
70 | pop | ZL
71 | pop | ZH
72 | pop | tbl_i
73 | pop | R1
74 | pop | R0 ; Registros recuperados del stack
75 | ret

76
77
78 ; -- ---- ----- ---- ----- ----- ---- ----- ----- ---- ----- ----- ---- ----- ----- ---- ----- --; 79 ; ---------------- Macros que utilizar án las siguientes rutinas - ----- ---- ----- -; 80 ; - ----- ----- ---- ----- ----- ---- ----- ----- ---- ----- ----- ---- ----- ----- ---- ----- --;

81
82 ; Carga en el puntero Z la direcci ón de flash recibida como argumento + param 83 .macro flash_point_Z_plus_param
84 | ldi | ZH , HIGH (@0 < <1)
85 | ldi | ZL , LOW (@0 < <1) ; Puntero en flash
86 | clr | tmp | ; Se borra el registro temporario
87 | add | ZL , param ; Se desplaza en la tabla seg ún el par á metro de entrada
88 | adc | ZH , tmp | ; Se suma el acarreo a la parte alta ( tmp = 0)
89 .endmacro

90
91 ; Escribe el valor del MUX2 según R0 , sin chequear su contenido
92 .macro set_MUX2_with_R0_value
93 | cli | ; Se desactivan las interrupciones para hacer el cambio
94 | in | tmp , PORTB | ; Lectura desde el puerto B
95 | cbr | tmp ,(1 < < PORTB0 ) |(1 < < PORTB1 ) ; Limpieza de los bit del MUX2
96 | or | tmp , R0 | ; Se graban los bit del MUX2 con R0
97 | out | PORTB , tmp | ; Escritura hacia el puerto B
98 | sei | ; Se vuelven a activar las interrupciones
99 .endmacro

100
101
102 ; |//////////////////////////////////////|\\\\\\\\\\\\\\\\\\\\\\\\\\\\\\\\\\\\\|;
103 ; |/////////| Encender la senoidal , para el rango de medici ón deseado |\\\\\\\\|; 104 ; |//////////////////////////////////////|\\\\\\\\\\\\\\\\\\\\\\\\\\\\\\\\\\\\\|;

105 ;
106 ; param ( R17 ) <- rango , 4 opciones : MEAS_RANGE_X con X en {1 , 2, 3, 4}
107 ; Encender á el PWM de la senoidal para un rango de medici ón determinado ,
108 ; especificado en el pará metro de entrada , por medio de un valor " enumerativo " 109 ; MEAS_RANGE_X , no hace chequeos de borde , se asume que se recibe un valor 110 ; correcto. Salva todos los registros que arruina.
111 ;
112 PWM_SINE_START :
113 | push | R0
114 | push | param
115 | push | ZH
116 | push | ZL ; Registros salvados en el stack

117
118 | ; Selecci ón del multiplexor MUX2
119 | flash_point_Z_plus_param MEAS_RANGE_FLASH_SIN_MUX2_VALUES
120 | lpm | R0 ,Z
121 | set_MUX2_with_R0_value

122
123 | ; Creaci ón de tabla en RAM
124 | flash_point_Z_plus_param MEAS_RANGE_FLASH_SINAMPS
125 | lpm | param ,Z | ; Valor correspondiente de amplitud para la rutina
126 | rcall | LOAD_SINE_RAM_TABLE_SCALED

127
128 | ; Inicializaci ón del puntero X y el contador tbl_i , no se pueden usar más!
129 | rcall | SINE_RAM_TABLE_GO_BEGINNING

130
131 | ; Configuraci ón del Timer0 como PWM
132 | ldi | tmp , PWM_FAST_PWM_CONFIG_T1
133 | out | TCCR0 , tmp | ; Habilita el PWM en modo rá pido
134 | in | tmp , TIMSK
135 | sbr | tmp , PWM_OV_INTERRUPT_MASK
136 | out | TIMSK , tmp | ; Habilita la interrupci ón de overflow Timer0

137
138 | pop | ZL
139 | pop | ZH
140 | pop | param
141 | pop | R0 ; Registros recuperados del stack
142 | ret

143
144
145 ; |//////////////////////////////////////|\\\\\\\\\\\\\\\\\\\\\\\\\\\\\\\\\\\\\|;
146 ; |////////////| Apagar la onda de salida ( dejar PWM al 50 % fijo ) |\\\\\\\\\\\|; 147 ; |//////////////////////////////////////|\\\\\\\\\\\\\\\\\\\\\\\\\\\\\\\\\\\\\|;

148 ;
149 ; Apaga la onda del PWM , es decir que deja lo deja en su valor medio de forma 150 ; constante (50 % de duty cycle ). Salva todos los registros que arruina.

151 ;
152 PWM_SINE_STOP :
153 | push | R0 ; Registros salvados en el stack

154
155 | ; Se pone el MUX2 en x30nA para minimizar errores de offset
156 | ldi | tmp , MUX2_x30nA
157 | mov | R0 , tmp
158 | set_MUX2_with_R0_value

159
160 | ; Configuraci ón del Timer0 como PWM
161 | ldi | tmp , PWM_FAST_PWM_CONFIG_T1
162 | out | TCCR0 , tmp | ; Habilita el PWM en modo rá pido
163 | in | tmp , TIMSK
164 | cbr | tmp , PWM_OV_INTERRUPT_MASK
165 | out | TIMSK , tmp | ; Deshabilita la interrupci ón de overflow Timer0

166
167 | ldi | tmp , PWM_SINE_MEDIAN
168 | out | OCR0 , tmp | ; Pone el valor medio en la salida

169

170 | pop | R0 ; Registros recuperados del stack
171 | ret

172
173
174 ; |//////////////////////////////////////|\\\\\\\\\\\\\\\\\\\\\\\\\\\\\\\\\\\\\|;
175 ; |//| Encender la continua de correcci ón, para el rango de medici ón deseado |\|; 176 ; |//////////////////////////////////////|\\\\\\\\\\\\\\\\\\\\\\\\\\\\\\\\\\\\\|;

177 ;
178 ; param ( R17 ) <- rango , 4 opciones : MEAS_RANGE_X con X en {1 , 2, 3, 4}
179 ; Encender á el PWM en el modo de correcci ón, es decir , se~n ales continuas. Seg ún 180 ; el rango especificado en el par á metro de entrada , por medio de un valor
181 ; " enumerativo " MEAS_RANGE_X , no hace chequeos de borde , se asume que se recibe 182 ; un valor correcto. Salva todos los registros que arruina.
183 ;
184 PWM_CONTINUE_CORRECTION_START :
185 | push | R0
186 | push | ZH
187 | push | ZL ; Registros salvados en el stack

188
189 | ; Selecci ón del multiplexor MUX2
190 | flash_point_Z_plus_param MEAS_RANGE_FLASH_CONTINUE_MUX2_VALUES
191 | lpm | R0 ,Z
192 | set_MUX2_with_R0_value

193
194 | ; Deshabilitaci ón del Timer0 como PWM
195 | ldi | tmp , PWM_OFF_PWM_CONFIG
196 | out | TCCR0 , tmp | ; Deshabilita el PWM en modo rá pido
197 | in | tmp , TIMSK
198 | cbr | tmp , PWM_OV_INTERRUPT_MASK
199 | out | TIMSK , tmp | ; Deshabilita la interrupci ón de overflow Timer0

200
201 | ; Corriente continua máxima , 0 en un sentido , 1 en otro
202 | ; TODO : ver cuál es el correcto
203 | sbi | PORTB , PORTB3
204 | ; cbi | PORTB , PORTB3

205
206 | pop | ZL
207 | pop | ZH
208 | pop | R0 ; Registros recuperados del stack
209 | ret

210
211
212 ; |//////////////////////////////////////|\\\\\\\\\\\\\\\\\\\\\\\\\\\\\\\\\\\\\|; 213 ; |/////////////////| Encender el PWM de Offset de referencia |\\\\\\\\\\\\\\\\|; 214 ; |//////////////////////////////////////|\\\\\\\\\\\\\\\\\\\\\\\\\\\\\\\\\\\\\|;

215 ;
216 ; param ( R17 ) <- rango , 4 opciones : MEAS_RANGE_X con X en {1 , 2, 3, 4}
217 ; Lee desde flash ( TODO : EEPROM ) los datos de calibraci ón de Offset.
218 ; Salva todos los registros que arruina. Incluso param (R17) y R2.

219 ;
220 PWM_OFFSET_START :
221 | push | ZH
222 | push | ZL ; Registros salvados en el stack

223
224 | ; Configuraci ón del Timer2 como PWM
225 | ldi | tmp , PWM_FAST_PWM_CONFIG_T2
226 | out | TCCR2 , tmp | ; Habilita el PWM en modo rá pido

227
228 | flash_point_Z_plus_param PWM_OFFSET_FLASH_CALIB_VALUE
229 | lpm | tmp , Z | ; Carga el valor medio ( duty cycle ) desde flash
230 | out | OCR2 , tmp | ; Pone el valor medio en la salida

231
232 | pop | ZL
233 | pop | ZH ; Registros recuperados del stack
234 | ret

## 9.3.9. adc.asm

1 ; ||||||||||||||||||||||||||||||||||||||||||||||||||||||||||||||||||||||||||||||;

2 ; ||||||||||||| Interrupci ón del ADC para cada conversi ón realizada ||||||||||||; 3 ; ||||||||||||||||||||||||||||||||||||||||||||||||||||||||||||||||||||||||||||||;
4 ADC_SAMPLE_STORE_TO_RAM_ISR :
5 | push | tmp ; En una interrupci ón hay que salvar el registro temporal

6
7 | in | tmp , ADCH | ; Muestra de 8 bits , ya que el ajuste es a izquierda
8 | st | Y+, tmp
9 | sbiw | tbl_jl ,1 | ; Decremento del contador de 16 bits
10 | brne | skip_stop_sampling ; Saltea si tbl_j no es cero
11 | ; Stop sampling
12 | clt ; El borrado del flag T indica que la conversi ón ha terminado
13 | ldi | tmp , ADC_DISABLE
14 | out | ADCSRA , tmp ; Se desactiva el ADC
15 | out | ADCSRA , tmp ; Se desactiva el ADC
16 | rjmp | skip_adc_reenabling

17
18 skip_stop_sampling :
19 | sbi | ADCSRA , ADSC ; Inicio de la conversi ón
20 skip_adc_reenabling :
21 | pop | tmp ; Se recupera el registro temporal

22
23 | reti

24
25
26 ; |//////////////////////////////////////|\\\\\\\\\\\\\\\\\\\\\\\\\\\\\\\\\\\\\|;
27 ; |/////////| Registro de 9 per í odos en RAM a 37 muestras por per í odo |\\\\\\\\|; 28 ; |//////////////////////////////////////|\\\\\\\\\\\\\\\\\\\\\\\\\\\\\\\\\\\\\|;

29 ;
30 ; Al finalizar la tabla estar á cargada en ADC_SAMPLES_RAM_TABLE con
31 ; ADC_SAMPLES_TABLE_LEN muestras. Salva todos los registros que arruina.
32 ;
33 ADC_SAMPLING_TO_RAM_FROM_IMPEDANCE_MEASURE_IN :
34 | ldi | YH , HIGH ( ADC_SAMPLES_RAM_TABLE )
35 | ldi | YL , LOW ( ADC_SAMPLES_RAM_TABLE ) | ; Inicializaci ón del puntero
36 | ldi | tbl_jh , HIGH ( ADC_SAMPLES_TABLE_LEN )
37 | ldi | tbl_jl , LOW ( ADC_SAMPLES_TABLE_LEN ) ; Inicializaci ón del contador
38 | set ; El flag T de SREG indicar á que el muestreo est á en curso

39
40 | ldi | tmp , ADC_AREF_LEFT_ADJUST_CONFIG | ADC_IMPEDANCE_MEASURE
41 | out | ADMUX , tmp

42
43 | ldi | tmp , ADC_ENABLE_AUTO_INT_PRESC
44 | out | ADCSRA , tmp

45
46 | sbi | ADCSRA , ADSC ; Inicio de la conversi ón

47
48 | ; Esperar hasta que todo esté muestreado en RAM
49 wait_for_sampling_completion :
50 | brts | wait_for_sampling_completion

51
52 | ret

## 9.3.10. measure routines.asm

1 ; |//////////////////////////////////////|\\\\\\\\\\\\\\\\\\\\\\\\\\\\\\\\\\\\\|;
2 ; |///////| Bú squeda de extremos locales (má ximo y mí nimo por per í odo ) |\\\\\\\|; 3 ; |//////////////////////////////////////|\\\\\\\\\\\\\\\\\\\\\\\\\\\\\\\\\\\\\|;

4 ;
5 ; Genera ADC_MAXS_RAM_TABLE y ADC_MINS_RAM_TABLE con los má ximos y mí nimos
6 ; locales de cada per íodo , luego las tablas son ordenadas por otra rutina para 7 ; encontrar ambas medianas. Salva todos los registros que arruina.
8 ;
9 SEARCH_FOR_LOCAL_EXTREMES_AND_LOAD_MIN_MAX_TABLES :
10 | push | R1
11 | push | R2
12 | push | R3
13 | push | iter
14 | push | iter2
15 | push | XH

16 | push | XL
17 | push | YH
18 | push | YL
19 | push | ZH
20 | push | ZL ; Registros salvados en el stack

21
22 | ldi | XH , HIGH ( ADC_SAMPLES_RAM_TABLE )
23 | ldi | XL , LOW ( ADC_SAMPLES_RAM_TABLE ) ; Puntero a la tabla de muestras
24 | ldi | YH , HIGH ( ADC_MAXS_RAM_TABLE )
25 | ldi | YL , LOW ( ADC_MAXS_RAM_TABLE ) | ; Puntero a la tabla de má ximos
26 | ldi | ZH , HIGH ( ADC_MINS_RAM_TABLE )
27 | ldi | ZL , LOW ( ADC_MINS_RAM_TABLE ) | ; Puntero a la tabla de mí nimos

28
29 | ldi | iter , ADC_PERIODS_TO_SAMPLE | ; Contador para cada per í odo
30 loop_periods :
31 | ldi | iter2 , ADC_SAMPLES_PER_PERIOD | ; Contador para cada sample
32 | ld | R2 ,X | ; Registro para alojar el máximo , se carga con el primer valor
33 | ld | R3 ,X | ; Registro para alojar el mínimo , se carga con el primer valor
34 loop_samples_one_period :
35 | ; Se buscar á mí nimo y má ximo ( enteros no signados ) dentro de este loop
36 | ld | R1 ,X + ; Carga de un sample y post incremento
37 | cp | R2 , R1 ; Si R2 >= R1 NO hay que actualizar el má ximo (R2)
38 | brsh | skip_update_max
39 | mov | R2 , R1 ; Actualizaci ón del máximo , si R1 > R2
40 skip_update_max :
41 | cp | R1 , R3 ; Si R1 >= R3 NO hay que actualizar el mí nimo (R3)
42 | brsh | skip_update_min
43 | mov | R3 , R1 ; Actualizaci ón del mínimo , si R1 < R3
44 skip_update_min :
45 | dec | iter2 ; Decremento del contador de samples
46 | brne | loop_samples_one_period
47 | ; En este punto , el má ximo del per í odo est á en R2 y el mí nimo en R3
48 | st | Y+, R2 ; Agregado del má ximo en la tabla y post incremento
49 | st | Z+, R3 ; Agregado del mí nimo en la tabla y post incremento
50 | dec | iter | ; Decremento del contador de per í odos
51 | brne | loop_periods

52
53 | pop | ZL
54 | pop | ZH
55 | pop | YL
56 | pop | YH
57 | pop | XL
58 | pop | XH
59 | pop | iter2
60 | pop | iter
61 | pop | R3
62 | pop | R2
63 | pop | R1 ; Registros recuperados del stack
64 | ret

65
66
67 ; |//////////////////////////////////////|\\\\\\\\\\\\\\\\\\\\\\\\\\\\\\\\\\\\\|;
68 ; |///| Obtenci ón de la mediana de la tabla apuntada por Z, de largo param |\\\|; 69 ; |//////////////////////////////////////|\\\\\\\\\\\\\\\\\\\\\\\\\\\\\\\\\\\\\|;

70 ;
71 ; param ( R17 ) <- largo de la tabla apuntada por Z
72 ; Ordena por el mé todo de burbujeo una tabla de enteros no signados en memoria , 73 ; apuntada por Z, de largo param ( R17 ). Luego toma el valor del medio para el 74 ; caso en que la cantidad de elementos sea impar , o el izquierdo de los dos
75 ; centrales , en el caso en que la cantidad de elementos es par. De esta forma 76 ; devuelve la mediana en R1. Salva todos los registros que arruina , incluso R17 77 ; y Z. NOTA : en el caso en que la cantidad de elementos fuera par , deber ía
78 ; devolver la media aritm é tica de ambos valores centrales , pero este caso no se 79 ; va a dar.
80 ;
81 CALCULATE_TO_R1_MEDIAN_IN_TABLE_POINTED_BY_Z_LENGTH_IN_PARAM :
82 | push | R2
83 | push | R3
84 | push | iter
85 | push | YH

86 | push | YL ; Registros salvados en el stack

87
88 | ; Ordenamiento por burbujeo , en una tabla peque ~na no es un algoritmo tan
89 | ; ineficiente , para la aplicaci ón se justifica
90 table_has_changed_loop :
91 | clt ; El flag T de SREG indicar á si la tabla ha cambiado , en principio no
92 | mov | iter , param ; Se inicializa el contador
93 | dec | iter | ; Se mirar á uno hacia adelante , se recorrer á uno menos
94 | mov | YH , ZH
95 | mov | YL , ZL | ; Se inicializa el puntero Y en Z
96 loop_table_elements :
97 | ld | R2 ,Y | ; Carga un elemento de la tabla
98 | ldd | R3 ,Y +1 | ; Carga el siguiente elemento de la tabla
99 | cp | R3 , R2 | ; Compara , si R3 >= R2 , no hay que intercambiarlos
100 | brsh | do_not_interchange
101 | set ; La tabla va a cambiar , entonces se indica en el flag T
102 | st | Y , R3 | ; En la primera posici ón se pone la segunda
103 | std | Y +1 , R2 | ; En la segunda posici ón se pone la primera
104 do_not_interchange :
105 | adiw | YL ,1 | ; Incremento de Y
106 | dec | iter | ; Decremento del contador
107 | brne | loop_table_elements
108 | brts | table_has_changed_loop

109
110 | ; En este punto la tabla est á ordenada , ahora la mediana se obtendr á de
111 | ; la mitad de la misma
112 | clr | R2
113 | mov | tmp , param
114 | asr | tmp | ; tmp /2: í ndice de la mitad de la tabla
115 | mov | YH , ZH
116 | mov | YL , ZL | ; Se inicializa el puntero Y en Z
117 | add | YL , tmp | ; Se le suma a Y el lugar de la mitad de la tabla
118 | adc | YH , R2 | ; Se suma el acarreo a la parte alta (R2 = 0)
119 | ld | R1 ,Y | ; Finalmente se obtiene la mediana en R1 para devolverla

120
121 | pop | YL
122 | pop | YH
123 | pop | iter
124 | pop | R3
125 | pop | R2 ; Registros recuperados del stack
126 | ret

127
128
129 ; |//////////////////////////////////////|\\\\\\\\\\\\\\\\\\\\\\\\\\\\\\\\\\\\\|;
130 ; |////| Procesamiento de muestras del ADC en RAM para obtener valor pico |\\\\|; 131 ; |//////////////////////////////////////|\\\\\\\\\\\\\\\\\\\\\\\\\\\\\\\\\\\\\|;

132 ;
133 ; Al finalizar , R2 contendr á el valor pico en bits , de la medici ón muestreada en 134 ; RAM por el ADC. Salva todos los registros que arruina.
135 ;
136 GET_THE_PEAK_VALUE_IN_R2_FROM_ADC_RAM_TABLE :
137 | push | R1
138 | push | param
139 | push | ZH
140 | push | ZL ; Registros salvados en el stack

141
142 | rcall | SEARCH_FOR_LOCAL_EXTREMES_AND_LOAD_MIN_MAX_TABLES

143
144 | ldi | param , ADC_PERIODS_TO_SAMPLE ; Cantidad de elementos en tablas
145 | ldi | ZH , HIGH ( ADC_MAXS_RAM_TABLE )
146 | ldi | ZL , LOW ( ADC_MAXS_RAM_TABLE ) | ; Puntero a la tabla de má ximos
147 | rcall | CALCULATE_TO_R1_MEDIAN_IN_TABLE_POINTED_BY_Z_LENGTH_IN_PARAM
148 | mov | R2 , R1 | ; R2 = MAX

149
150 | ldi | ZH , HIGH ( ADC_MINS_RAM_TABLE )
151 | ldi | ZL , LOW ( ADC_MINS_RAM_TABLE ) | ; Puntero a la tabla de mí nimos
152 | rcall | CALCULATE_TO_R1_MEDIAN_IN_TABLE_POINTED_BY_Z_LENGTH_IN_PARAM
153 | sub | R2 , R1 | ; R1 = MIN , valor pico = (MAX - MIN )/2
154 | lsr | R2 | ; R2 contiene el valor pico medido

155

156 | pop | ZL
157 | pop | ZH
158 | pop | param
159 | pop | R1 ; Registros recuperados del stack
160 | ret

161
162
163 ; |//////////////////////////////////////|\\\\\\\\\\\\\\\\\\\\\\\\\\\\\\\\\\\\\|;
164 ; |///| Obtener impedancia en dé cimas de mega ohms , seg ún rango de medici ón |\\|; 165 ; |//////////////////////////////////////|\\\\\\\\\\\\\\\\\\\\\\\\\\\\\\\\\\\\\|;

166 ;
167 ; param ( R17 ) <- rango , 4 opciones : MEAS_RANGE_X con X en {2 , 8, 20 , 60}
168 ; R2 <- valor pico de la medici ón en bits ( valor de lectura L)
169 ; Al finalizar R1:R0 contendr á el valor de impedancia en dé cimas de mega ohm. 170 ; Lee desde flash ( TODO : EEPROM ) los datos de calibraci ón de cada rango.
171 ; Salva todos los registros que arruina. Incluso param (R17) y R2.

172 ;
173 GET_DECIMEG_IMPEDANCE_FROM_PARAM_RANGE_R2_PEAK_VALUE_IN_R1_R0 :
174 | push | R2
175 | push | R3
176 | push | R4
177 | push | R5
178 | push | R6
179 | push | R7
180 | push | param
181 | push | ZH
182 | push | ZL ; Registros salvados en el stack

183
184 | ldi | ZH , HIGH ( MEAS_RANGE_FLASH_P_FACTOR_DEFAULTS < <1)
185 | ldi | ZL , LOW ( MEAS_RANGE_FLASH_P_FACTOR_DEFAULTS < <1)

186
187 | lsl | param | ; param = param * 2
188 | clr | tmp
189 | add | ZL , param | ; Z = Z + param
190 | adc | ZH , tmp | ; Actualizaci ón de la parte alta con el carry ( tmp = 0)

191
192 | lpm | R6 ,Z + ; Lectura del par á metro P desde flash , little - endian (L)
193 | lpm | R7 ,Z | ; Lectura del par á metro P desde flash , little - endian (H)

194
195 | ; Multiplicaci ón: R2:R1:R0 = R7:R6 * R2
196 | mul | R7 , R2 | ; R1:R0 = R2 * R7 , parte alta del producto
197 | mov | R5 , R1 | ; Se va a salvar en R5:R4
198 | mov | R4 , R0 | ; R5:R4 = R1:R0
199 | mul | R6 , R2 | ; R1:R0 = R2 * R6 , parte baja del producto
200 | clr | R2 | ; R2 = 0
201 | add | R1 , R4 | ; R1 = R1 + R4 , suma de ambas partes del producto
202 | adc | R2 , R5 | ; R2 = R5 + carry

203
204 | ; Divisi ón por 256 (el par á metro P fue calculado para esto )
205 | mov | R0 , R1 | ; Basta con desplazar los dos registros
206 | mov | R1 , R2 | ; Resultado de la medici ón en dé cimas de mega ohm en R1:R0

207
208 | pop | ZL
209 | pop | ZH
210 | pop | param
211 | pop | R7
212 | pop | R6
213 | pop | R5
214 | pop | R4
215 | pop | R3
216 | pop | R2 ; Registros recuperados del stack
217 | ret

218
219
220 ; ;;;;;;;;;;;;;;;;;;;;;;;;;;;;;;;;;;;;;;;;;;;;;;;;;;;;;;;;;;;;;;;;;;;;;;;;;;;;;;; 221 ; ;;;; Solo para testear , se cargan estos datos en RAM , generados con octave ;;;; 222 ; ;;;;;;;;;;;;;;;;;;;;;;;;;;;;;;;;;;;;;;;;;;;;;;;;;;;;;;;;;;;;;;;;;;;;;;;;;;;;;;; 223 ; TEST_SAMPLES_FLASH_TABLE :
224 ; | .db 0x81 , 0x90 , 0xA2 , 0xAF , 0xC0 , 0xC9 , 0xD5 , 0xDB , 0xE2 , 0xE4 , 0xE5 , 0 xDE
225 ; | .db 0xD9 , 0xD2 , 0xC4 , 0xB7 , 0xAB , 0x98 , 0x87 , 0x77 , 0x66 , 0x56 , 0x48 , 0 x3B

226 ; | .db 0x30 , 0x29 , 0x1F , 0x1E , 0x1B , 0x1C , 0x22 , 0x2A , 0x36 , 0x40 , 0x50 , 0 x5E
227 ; | .db 0x6F , 0x7E , 0x92 , 0xA2 , 0xAF , 0xBF , 0xCC , 0xD3 , 0xDD , 0xE0 , 0xE4 , 0 xE4
228 ; | .db 0xE0 , 0xD9 , 0xD1 , 0xC6 , 0xB9 , 0xA9 , 0x99 , 0x8B , 0x77 , 0x67 , 0x57 , 0 x48
229 ; | .db 0x3D , 0x2F , 0x25 , 0x20 , 0x1B , 0x1E , 0x20 , 0x23 , 0x2C , 0x34 , 0x40 , 0 x4E
230 ; | .db 0x5F , 0x6F , 0x80 , 0x8F , 0xA2 , 0xB1 , 0xC0 , 0xCB , 0xD5 , 0xDA , 0xE3 , 0 xE3
231 ; | .db 0xE2 , 0xDF , 0xDA , 0xD0 , 0xC5 , 0xBA , 0xAC , 0x9D , 0x89 , 0x79 , 0x69 , 0 x56
232 ; | .db 0x4A , 0x3C , 0x31 , 0x29 , 0x22 , 0x1D , 0x1D , 0x1E , 0x21 , 0x2B , 0x34 , 0 x41
233 ; | .db 0x4C , 0x5E , 0x6F , 0x7C , 0x8F , 0xA0 , 0xAD , 0xBF , 0xC9 , 0xD5 , 0xDA , 0 xE1
234 ; | .db 0xE3 , 0xE5 , 0xE0 , 0xDB , 0xD2 , 0xC6 , 0xB9 , 0xAC , 0x9B , 0x8B , 0x7C , 0 x67
235 ; | .db 0x5A , 0x4C , 0x3D , 0x30 , 0x29 , 0x23 , 0x1E , 0x1B , 0x1C , 0x24 , 0x28 , 0 x35
236 ; | .db 0x3D , 0x4B , 0x5E , 0x6C , 0x7F , 0x8D , 0xA0 , 0xAE , 0xBF , 0xCA , 0xD6 , 0 xDA
237 ; | .db 0xE3 , 0xE4 , 0xE2 , 0xE0 , 0xDB , 0xD1 , 0xC7 , 0xBB , 0xAE , 0x9B , 0x8C , 0 x79
238 ; | .db 0x68 , 0x5A , 0x4A , 0x3C , 0x2F , 0x2A , 0x22 , 0x1C , 0x1B , 0x1F , 0x24 , 0 x28
239 ; | .db 0x31 , 0x3F , 0x4C , 0x5D , 0x6C , 0x7E , 0x8F , 0x9D , 0xAE , 0xBC , 0xC8 , 0 xD2
240 ; | .db 0xDD , 0xE1 , 0xE4 , 0xE2 , 0xE2 , 0xDD , 0xD3 , 0xC9 , 0xBD , 0xAE , 0x9B , 0 x8C
241 ; | .db 0x7B , 0x6A , 0x59 , 0x4A , 0x3F , 0x32 , 0x27 , 0x20 , 0x1E , 0x1C , 0x1E , 0 x22
242 ; | .db 0x2B , 0x32 , 0x3F , 0x4C , 0x5D , 0x6C , 0x7B , 0x8E , 0x9F , 0xAD , 0xBB , 0 xCA
243 ; | .db 0xD2 , 0xDB , 0xDF , 0xE3 , 0xE4 , 0xE0 , 0xDA , 0xD2 , 0xC8 , 0xBB , 0xAD , 0 x9E
244 ; | .db 0x8C , 0x7B , 0x6A , 0x5A , 0x4C , 0x3F , 0x31 , 0x29 , 0x22 , 0x1D , 0x1D , 0 x1D
245 ; | .db 0x22 , 0x2A , 0x33 , 0x3D , 0x4A , 0x5C , 0x6A , 0x7B , 0x8C , 0x9C , 0xAC , 0 xBC
246 ; | .db 0xC7 , 0xD4 , 0xDA , 0xE2 , 0xE2 , 0xE4 , 0xE2 , 0xDC , 0xD5 , 0xCA , 0xBD , 0 xAE
247 ; | .db 0x9E , 0x8C , 0x7C , 0x6B , 0x59 , 0x4C , 0x3D , 0x31 , 0x2B , 0x20 , 0x1F , 0 x1D
248 ; | .db 0x1E , 0x23 , 0x29 , 0x31 , 0x3F , 0x4C , 0x5C , 0x6A , 0x79 , 0x8E , 0x9D , 0 xAD
249 ; | .db 0xBB , 0xC8 , 0xD3 , 0xDB , 0xDF , 0xE3 , 0xE2 , 0xE1 , 0xDA , 0xD3 , 0xCB , 0 xBC
250 ; | .db 0xB0 , 0xA0 , 0x8F , 0x7E , 0x6E , 0x5C , 0x4B , 0x3E , 0x34 , 0x2B , 0x21 , 0 x1C
251 ; | .db 0x1E , 0x1D , 0x20 , 0x29 , 0x30 , 0x3F , 0x4B , 0x59 , 0x69 , 0 x00
252 ;
253 ; TEST_SAMPLES_FLASH :
254 ; | ldi | ZH , HIGH ( TEST_SAMPLES_FLASH_TABLE < <1)
255 ; | ldi | ZL , LOW ( TEST_SAMPLES_FLASH_TABLE < <1)
256 ; | ldi | XH , HIGH ( ADC_SAMPLES_RAM_TABLE )
257 ; | ldi | XL , LOW ( ADC_SAMPLES_RAM_TABLE )
258 ; | ldi | YH , HIGH ( ADC_SAMPLES_TABLE_LEN ) ; Ojo : no es un puntero !
259 ; | ldi | YL , LOW ( ADC_SAMPLES_TABLE_LEN ) | ; Es un contador de 16 bits !
260 ; loop_test_samples_table :
261 ; | lpm | tmp ,Z+
262 ; | st | X+, tmp
263 ; | sbiw | YL ,1 ; Decremento del contador
264 ; | brne | loop_test_samples_table
265 ;
266 ; | rcall | GET_THE_PEAK_VALUE_IN_R2_FROM_ADC_RAM_TABLE
267 ; here :
268 ; | rjmp | here
269 ; ;;;;;;;;;;;;;;;;;;;;;;;;;;;;;;;;;;;;;;;;;;;;;;;;;;;;;;;;;;;;;;;;;;;;;;;;;;;;;;; 270 ; ;;;;;;;;;;;;;;;;;;;;;;;;;;;;;;;;;;;;;;;;;;;;;;;;;;;;;;;;;;;;;;;;;;;;;;;;;;;;;;;

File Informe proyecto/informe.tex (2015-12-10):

%||||||||||||||||||||||||||||||||||||||||||||||||||||||||||||||||||||||||||||||%
%|||||||||||||||||||||||||||||| Carga de paquetes |||||||||||||||||||||||||||||%
%||||||||||||||||||||||||||||||||||||||||||||||||||||||||||||||||||||||||||||||%

% Acá se define el tamaño de letra principal:
\documentclass[12pt]{article}

% Definición del tamaño de página y los márgenes:
\usepackage[a4paper,scale={0.80,0.80},
            headheight=15pt,headsep=20pt,voffset=15pt,footskip=50pt]{geometry}

% Vamos a escribir en castellano:
\usepackage[utf8x]{inputenc}
\usepackage[spanish]{babel}
\selectlanguage{spanish}

% El paquete amsmath agrega algunas funcionalidades extra a las fórmulas.
% Además defino la numeración de las tablas y figuras al estilo "Figura 2.3",
% en lugar de "Figura 7". (Por lo tanto, aunque no uses fórmulas, si querés
% este tipo de numeración dejá el paquete amsmath descomentado).
\usepackage{amsmath}
\numberwithin{equation}{section}
\numberwithin{figure}{section}
\numberwithin{table}{section}

% Agregado de algunos símbolos matemáticos
\usepackage{amssymb}

% Para tener cabecera y pie de página con un estilo personalizado:
\usepackage{fancyhdr}

% Para poner el texto "Figura X" en negrita:
% (Si no tenés el paquete 'caption2', probá con 'caption').
\usepackage[hang,bf]{caption}

% Para poder usar subfiguras: (al estilo Figura 2.3(b) )
%\usepackage{subfigure}

% Para poder agregar notas al pie en tablas:
%\usepackage{threeparttable}

% Para incluir imágenes, el siguiente código carga el paquete graphicx
% según se esté generando un archivo dvi o un pdf (con pdflatex).
%
% Para generar dvi, descomentá la linea siguiente:
%\usepackage[dvips]{graphicx}
%
% Para generar pdf, descomentá las dos lineas siguientes:
\usepackage[pdftex]{graphicx}
\pdfcompresslevel=9

% Directorio de imágenes:
\graphicspath{{\imgdir/}}

% Para ubicar las imágenes en un lugar específico
\usepackage{float}

% Para la utilización de colores
\usepackage[usenames,dvipsnames]{xcolor, colortbl}

% Para insertar codigo fuente (configuración en archivo externo)
\input{listings_config.tex}

% Para utilizar hipervínculos
\usepackage{hyperref}

% Para dibujar gráficos vectoriales (también añade el bucle 'for')
\usepackage{tikz}

% Agregado de caligrafía matemática
\usepackage{bbold}

% Tablas con filas y columnas colapsadas
\usepackage{multirow}

% Unidades del SI
\usepackage{siunitx}
\sisetup{per-mode=fraction} % Fración en vez de exponente -1
\sisetup{output-decimal-marker = {,}} % Coma en vez de punto decimal
\ifx \bit \undefined % Definición de bit, si falta
    \DeclareSIUnit\bit{bit}
\fi

% Flechas largas
% \usepackage{extarrows}

% Configuración de párrafos
\usepackage{parskip}
\setlength{\parindent}{20pt}

%------------------- Datos modificables desde archivo aparte ------------------%
\newcommand\integrante[3]{
    & #1, #2 & #3 \\ \cline{2-3}
}
\input{datos.tex}
%------------------------------------------------------------------------------%

% Título y autor(es):
\title{\titulo}
\author{\autores}

%||||||||||||||||||||||||||||||||||||||||||||||||||||||||||||||||||||||||||||||%
%|||||||||||||||||||||||||||| Inicio del documento ||||||||||||||||||||||||||||%
%||||||||||||||||||||||||||||||||||||||||||||||||||||||||||||||||||||||||||||||%
\begin{document}

% Estilo de encabezado y pie de página:
\pagestyle{fancy}
\renewcommand{\headrule}{\vspace{-3mm}\textcolor{Gray}{\hrule}}
\renewcommand{\footrule}{\textcolor{Gray}{\hrule}\vspace{1mm}}
\lhead{\textcolor{Gray}{\textsf{\codmateria\ - \nommateria}}}
\chead{}
\rhead{\textcolor{Gray}{\textsf{\titulo}}}
\lfoot{\textcolor{Gray}{\textsf{\autores}}}
\cfoot{}
\rfoot{\textcolor{Gray}{\boxed{\textbf{\textsf{\thepage}}}}}

% Carátula:
\begin{titlepage}

    \thispagestyle{empty}

    \begin{center}

        \minipage{0.4\textwidth}
            \minipage{0.16\textwidth}
                
            \endminipage
            \minipage{0.84\textwidth}
                \huge{\textbf{F\ i\ u\ b\ a}}\\
                \large{\textrm{Facultad de Ingeniería}}\\
                \normalsize{\textrm{Universidad de Buenos Aires}}
            \endminipage
        \endminipage
        \minipage{0.6\textwidth}
            \begin{center}
                \large{\textsc{\nommateria\\(\codmateria)}}
            \end{center}
        \endminipage

        \vfill

        \hrule
        \large{\textsc{Informe Final del Proyecto}}
        \vspace{2mm}\hrule

        \vfill

        \begin{tabular}{|p{0.3\textwidth}|p{0.4\textwidth}|p{0.2\textwidth}|}
            \hline
            \textbf{Proyecto:} &
                \multicolumn{2}{p{0.6\textwidth}|}{\textbf{\titulo}}\\[6pt]
            \hline
            Autores: \integrantes
            \hline
            Turno de TP: &
                \multicolumn{2}{p{0.6\textwidth}|}{\turno}\\
            \hline
            Año y Cuatrimestre: & \anio & \cuatrim \\
            \hline
            Docente Guía: &
                \multicolumn{2}{p{0.6\textwidth}|}{\docente}\\
            \hline
        \end{tabular}

        \vfill

        \begin{tabular}{|p{0.95\textwidth}|}
            \hline \vfill
            Observaciones Generales
            \\[6pt] \hline
            \\[12pt] \hline
            \\[12pt] \hline
            \\[12pt] \hline
            \\[12pt] \hline
            \\[12pt] \hline
            \\[12pt] \hline
            \\[12pt] \hline
        \end{tabular}

        \vfill

        \begin{tabular}{|p{0.314\textwidth}|p{0.61\textwidth}|}
            \hline
            \vfill Calificación Final \vfill & \\[36pt]
            \hline
            \vfill Firma del Docente \vfill & \\[36pt]
            \hline
            \vfill Fecha \vfill & \\[6pt]
            \hline
        \end{tabular}

    \end{center}

\end{titlepage}

% Hago que las páginas se comiencen a contar desde aquí
\setcounter{page}{1}

% Pongo el índice en una página aparte:
\ifx \indice \undefined
\else
    \tableofcontents
    \newpage
\fi

%||||||||||||||||||||||||||||||||||||||||||||||||||||||||||||||||||||||||||||||%
%||||||||||||||||||||||||| Definiciones para abreviado ||||||||||||||||||||||||%
%||||||||||||||||||||||||||||||||||||||||||||||||||||||||||||||||||||||||||||||%

% Gráficos comunes:
% \figuregraph{escala}{nombre/etiqueta}{pie de imagen}
\newcommand{\figuregraph}[3]{
    \begin{figure}[H]
        \center
        
        \caption{#3}\label{#2}
    \end{figure}
}

% Dos gráficos horizontales:
% \twofigures{escala1}{nombre/etiqueta1}{pie1}{escala2}{nombre/etiqueta2}{pie2}
\newcommand{\twofigures}[6]{
    \begin{figure}[H]
        \minipage{0.5\textwidth}
            \center
            
            \caption{#3}\label{#2}
        \endminipage
        \minipage{0.5\textwidth}
            \center
            
            \caption{#6}\label{#5}
        \endminipage
    \end{figure}
}

%------------------- Cuerpo del documento en archivo aparte -------------------%
\input{cuerpo.tex}
%------------------------------------------------------------------------------%

\end{document} % Fin!
%%%%%%%%%%%%%%%%%%%%%%%%%%%%%%%%%%%%%%%%%%%%%%%%%%%%%%%%%%%%%%%%%%%%%%%%%%%%%%%%

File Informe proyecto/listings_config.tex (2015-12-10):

% Paquete para insertar código fuente:
\usepackage{listings}

% Necesario para imprimir las comillas rectas y no las de LaTeX:
\usepackage{textcomp}

% ------------------------- Configuraciones generales ------------------------ %
\lstset
{
    extendedchars=\true,%               Incluir caracteres extendidos
    inputencoding=utf8x,%               Codificación utilizada
    linewidth=\textwidth,%              Ancho máximo de una linea de código
    xleftmargin=16pt,%                  Margen izquierdo
    xrightmargin=5pt,%                  Margen derecho
    breaklines=true,%                   Corte de lineas largas
    numbers=left,%                      Números de línea a la izquierda
    stepnumber=1,%                      Avance de los números de línea de a 1
    numbersep=5pt,%                     Separación de los números de línea
    tabsize=4,showtabs=false,%          Los TABs miden 4 espacios, y no se ven
    showstringspaces=false,%            Los espacios en las cadenas no se marcan
    upquote=true,%                      Impresión correcta de las comillas
    numberstyle=\tiny,%                 Estilo de los números de línea
    basicstyle=\ttfamily\scriptsize,%   Estilo básico del código fuente
    commentstyle=\color{Gray},%         Estilo de los comentarios
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

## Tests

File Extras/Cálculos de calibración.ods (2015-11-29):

Rango [MΩ] |  | I máx [nA] | Escala: x/128 (por soft) | I [nA] | ΔV [mV] si ΔZ = 0,1MΩ | ΔZ [MΩ] si ΔV = kADC | ΔZ [MΩ] si ΔV = 96,5mV | Vexcursión [V] | α [kΩ] | β = α / 0,1 MΩ | p = ⌈γ β⌉ | Error absoluto [kΩ] | Error relativo [%]
0 | 2 | 200,00 | 128 | 200,00 | 90,91 | 0,021 | 0,106 | 1,82 | 21,48 | 0,215 | 55 | 100 | 10,00%
0 |  | 212,31 | 100,00% | 212,31 | 96,51 | 0,020 | 0,100 | 1,93 | 20,24 | 0,202 | 52 | 100 | 10,00%
0 | 8 | 80,00 | 84 | 52,50 | 23,86 | 0,082 | 0,404 | 1,91 | 81,85 | 0,818 | 210 | 100 | 2,50%
 |  | 83,26 | 65,63% | 54,64 | 24,84 | 0,079 | 0,389 | 1,99 | 78,64 | 0,786 | 202 | 100 | 2,50%
0 | 20 | 30,00 | 92 | 21,56 | 9,80 | 0,199 | 0,985 | 1,96 | 199,28 | 1,993 | 511 | 100 | 1,00%
 |  | 30,29 | 71,88% | 21,77 | 9,90 | 0,197 | 0,975 | 1,98 | 197,34 | 1,973 | 506 | 200 | 2,00%
0 | 60 | 30,00 | 30 | 7,03 | 3,20 | 0,611 | 3,020 | 1,92 | 611,11 | 6,111 | 1565 | 100 | 0,33%
 |  | 30,29 | 23,44% | 7,10 | 3,23 | 0,605 | 2,990 | 1,94 | 605,18 | 6,052 | 1550 | 400 | 1,33%
 |  |  |  |  | G OpAmp ADC | Vexcursión deseado [V] | kADC [mV] | γ = 2^k
 |  |  |  |  | 4,55 | 2,00 | 19,53 | 256
 |  |  |  |  | Corriente deseada [nA] | R multiplexada [kΩ] | Corriente final [nA]
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

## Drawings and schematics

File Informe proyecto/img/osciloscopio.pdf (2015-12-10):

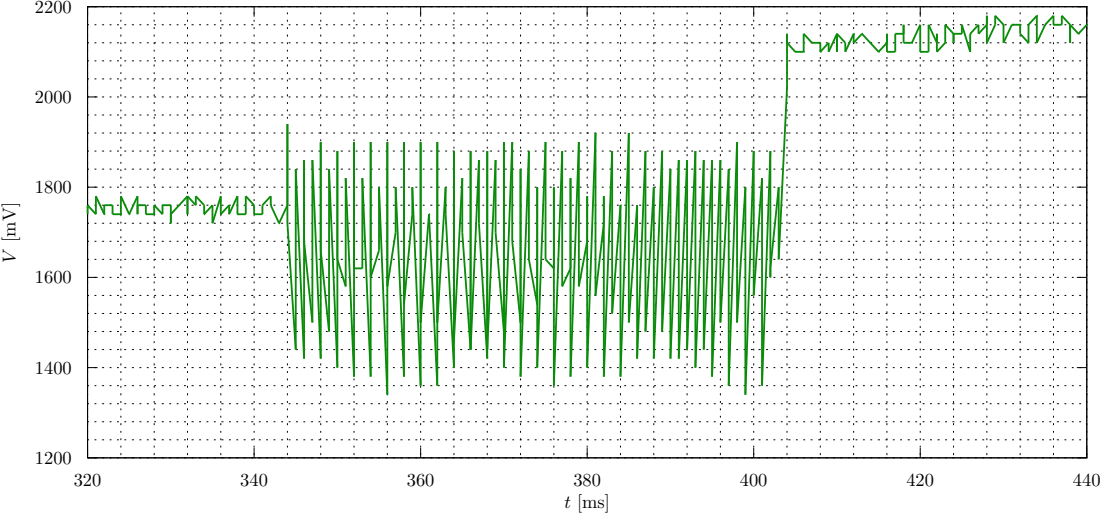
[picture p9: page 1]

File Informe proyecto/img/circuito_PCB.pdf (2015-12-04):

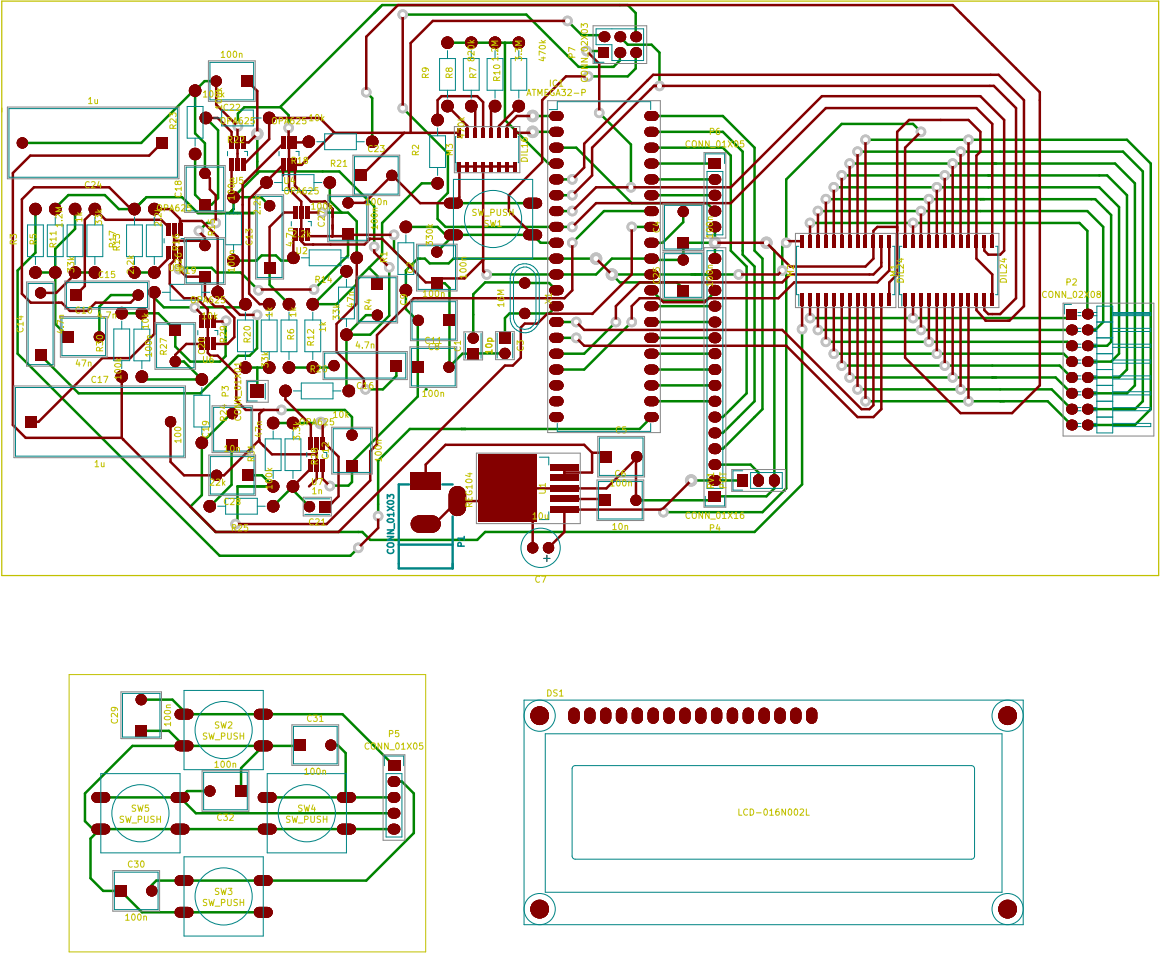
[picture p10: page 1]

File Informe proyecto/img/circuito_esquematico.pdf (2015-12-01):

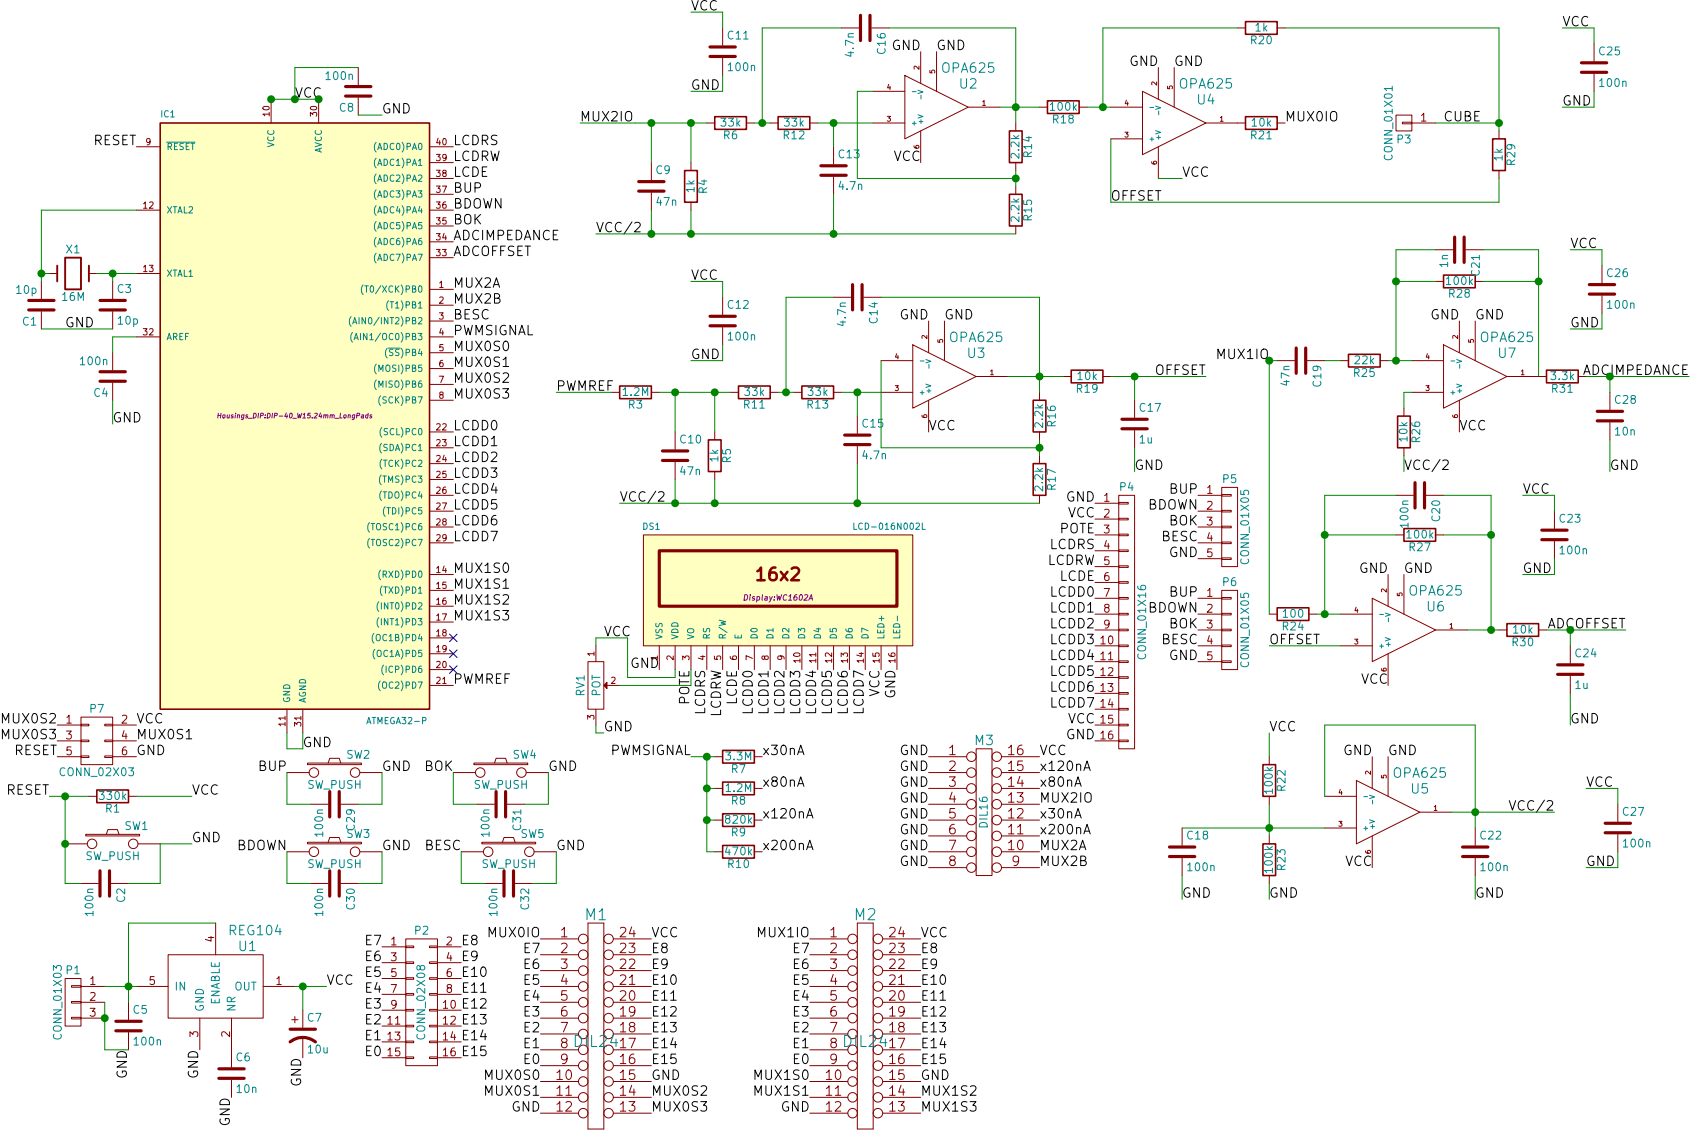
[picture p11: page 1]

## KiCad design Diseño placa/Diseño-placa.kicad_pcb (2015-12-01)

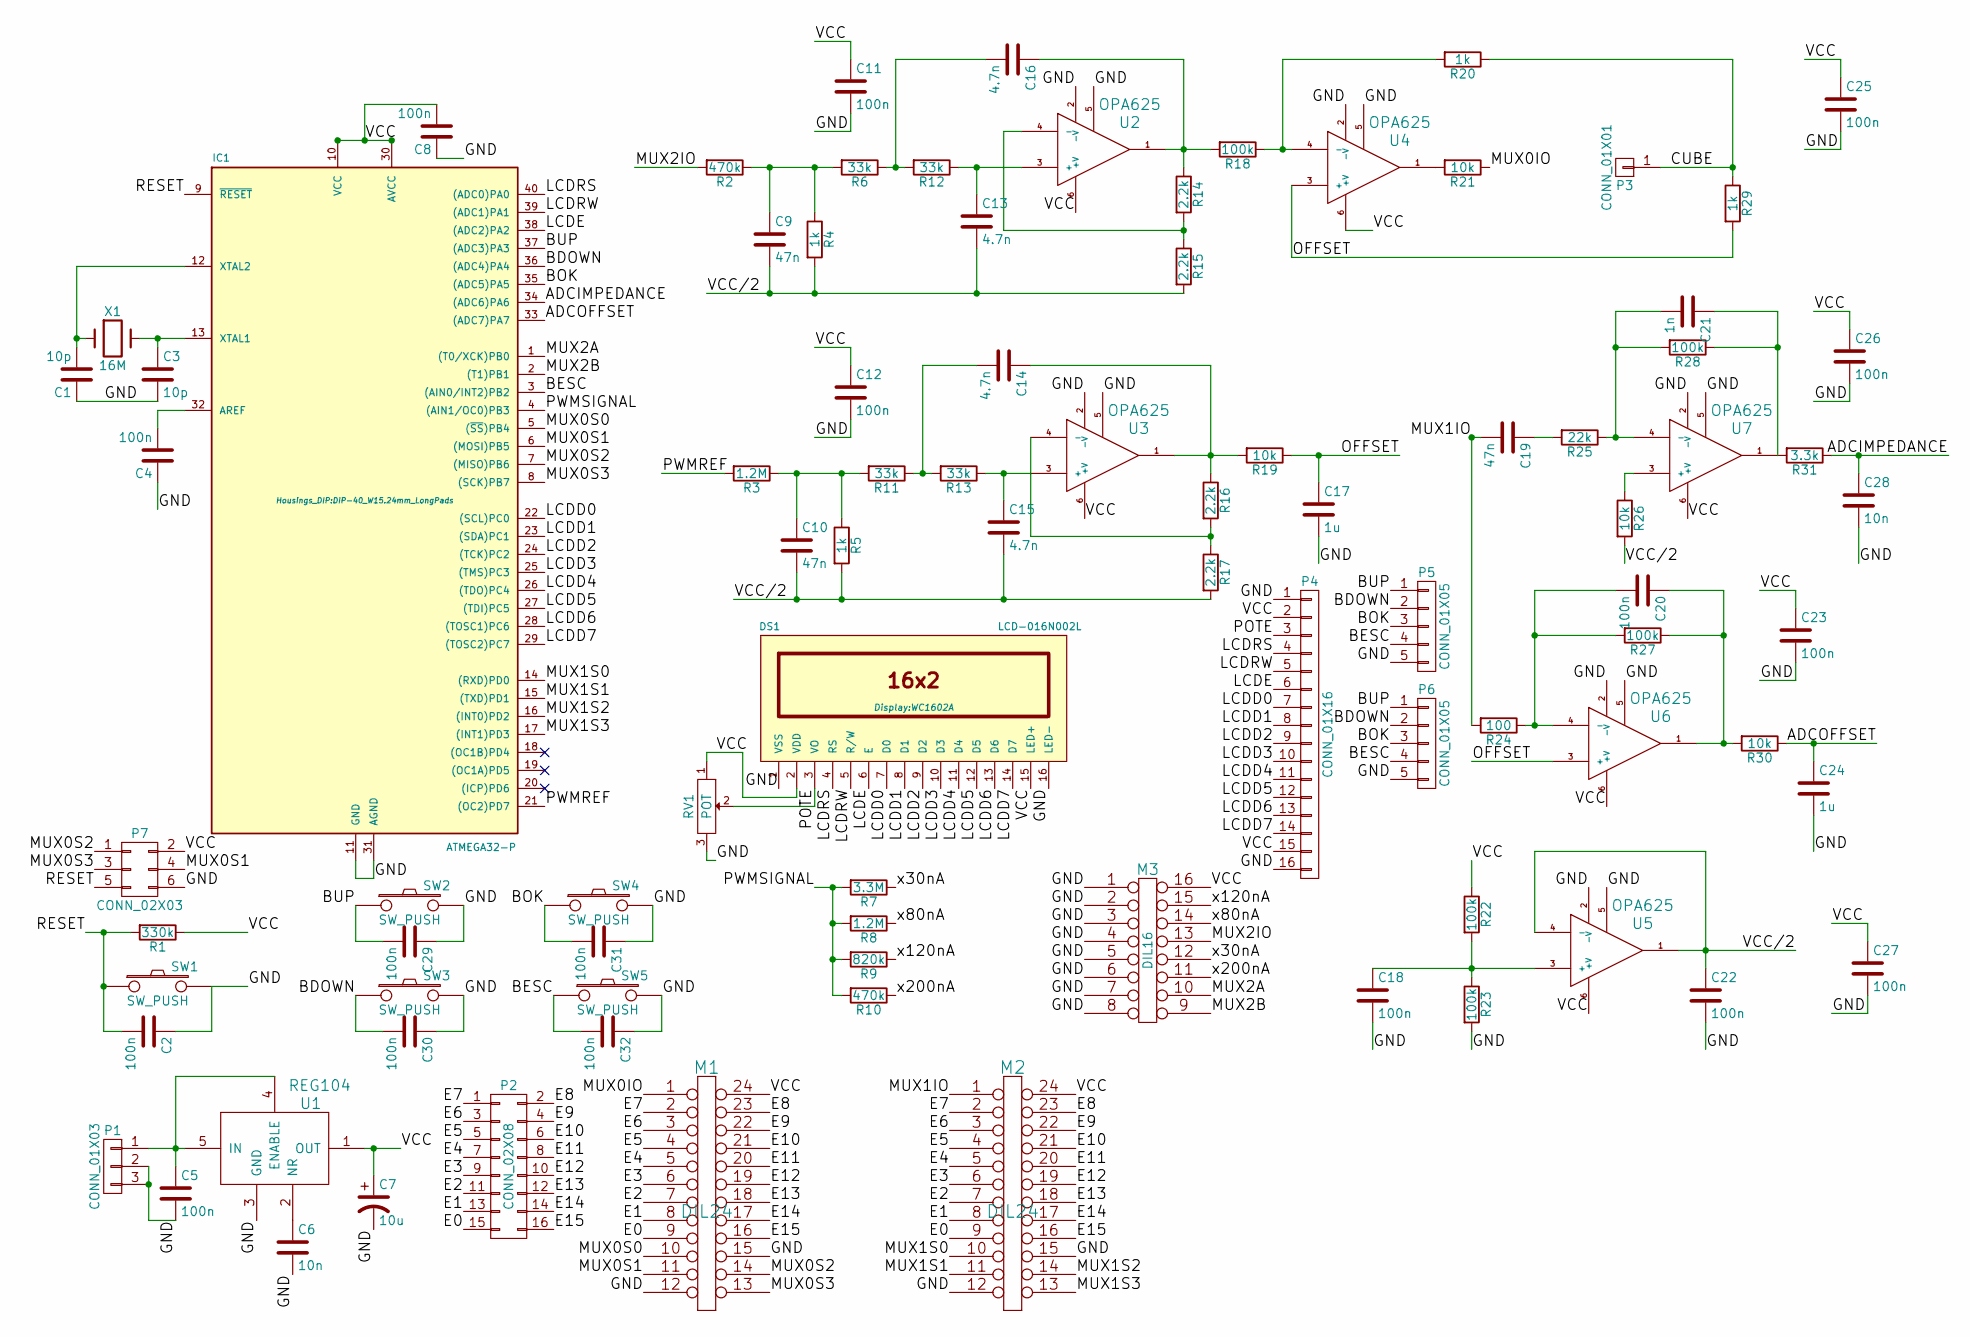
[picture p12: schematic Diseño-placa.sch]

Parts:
C1, C3: 10p; C_Rect_L4_W2.5_P2.5
C2, C4, C5, C8, C11, C12, C18, C20, C22, C23, C25, C26, C27, C29, C30, C31, C32: 100n; C_Rect_L7_W6_P5
C6, C28: 10n; C_Rect_L7_W6_P5
C7: 10u; Elko_vert_11.2x6.3mm_RM2.5
C9, C10, C19: 47n; C_Rect_L7_W6_P5
C13, C14, C15, C16: 4.7n; C_Rect_L13_W4_P10
C17, C24: 1u; C_Rect_L27_W11_P22
C21: 1n; C_Rect_L4_W2.5_P2.5
DS1: LCD-016N002L; WC1602A
IC1: ATMEGA32-P; DIP-40_W15.24mm_LongPads
M1, M2: DIL24; SOIC-24_7.5x15.4mm_Pitch1.27mm
M3: DIL16; SOIC-16_3.9x9.9mm_Pitch1.27mm
P1: CONN_01X03; JACK_PWR
P2: CONN_02X08; Pin_Header_Angled_2x08
P3: CONN_01X01; Pin_Header_Straight_1x01
P4: CONN_01X16; Pin_Header_Straight_1x16
P5, P6: CONN_01X05; Pin_Header_Straight_1x05
P7: CONN_02X03; Pin_Header_Straight_2x03
R1: 330k; Resistor_Horizontal_RM10mm
R2, R10: 470k; Resistor_Horizontal_RM10mm
R3, R8: 1.2M; Resistor_Horizontal_RM10mm
R4, R5, R20, R29: 1k; Resistor_Horizontal_RM10mm
R6, R11, R12, R13: 33k; Resistor_Horizontal_RM10mm
R7: 3.3M; Resistor_Horizontal_RM10mm
R9: 820k; Resistor_Horizontal_RM10mm
R14, R15, R16, R17: 2.2k; Resistor_Horizontal_RM10mm
R18, R22, R23, R27, R28: 100k; Resistor_Horizontal_RM10mm
R19, R21, R26, R30: 10k; Resistor_Horizontal_RM10mm
R24: 100; Resistor_Horizontal_RM10mm
R25: 22k; Resistor_Horizontal_RM10mm
R31: 3.3k; Resistor_Horizontal_RM10mm
RV1: POT; Pin_Header_Straight_1x03
SW1, SW2, SW3, SW4, SW5: SW_PUSH; SW_PUSH-12mm
U1: REG104; TO-263-5Lead
U2, U3, U4, U5, U6, U7: OPA625; TSOT-6-MK06A_Handsoldering
X1: 16M; Crystal_HC49-U_Vertical

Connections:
/ADCIMPEDANCE: C28.1, IC1.34 ((ADC6)PA6), R31.1
/ADCOFFSET: C24.1, IC1.33 ((ADC7)PA7), R30.1
/BDOWN: C30.2, IC1.36 ((ADC4)PA4), P5.2, P6.2, SW3.1
/BESC: C32.2, IC1.3 ((AIN0/INT2)PB2), P5.4, P6.4, SW5.1
/BOK: C31.2, IC1.35 ((ADC5)PA5), P5.3, P6.3, SW4.1
/BUP: C29.2, IC1.37 ((ADC3)PA3), P5.1, P6.1, SW2.1
/CUBE: P3.1, R20.1, R29.1
/E0: M1.9, M2.9, P2.15
/E1: M1.8, M2.8, P2.13
/E2: M1.7, M2.7, P2.11
/E3: M1.6, M2.6, P2.9
/E4: M1.5, M2.5, P2.7
/E5: M1.4, M2.4, P2.5
/E6: M1.3, M2.3, P2.3
/E7: M1.2, M2.2, P2.1
/E8: M1.23, M2.23, P2.2
/E9: M1.22, M2.22, P2.4
/E10: M1.21, M2.21, P2.6
/E11: M1.20, M2.20, P2.8
/E12: M1.19, M2.19, P2.10
/E13: M1.18, M2.18, P2.12
/E14: M1.17, M2.17, P2.14
/E15: M1.16, M2.16, P2.16
/GND: C1.1, C2.1, C3.2, C4.1, C5.2, C6.2, C7.2, C8.1, C11.2, C12.2, C17.2, C18.2, C22.2, C23.2, C24.2, C25.2, C26.2, C27.2, C28.2, C29.1, C30.1, C31.1, C32.1, DS1.1 (VSS), DS1.16 (LED-), IC1.11 (GND), IC1.31 (AGND), M1.12, M1.15, M2.12, M2.15, M3.1, M3.2, M3.3, M3.4, M3.5, M3.6, M3.7, M3.8, P1.2, P1.3, P4.1, P4.16, P5.5, P6.5, P7.6, R23.2, RV1.3, SW1.2, SW2.2, SW3.2, SW4.2, SW5.2, U1.3 (GND), U2.2 (-V), U2.5, U3.2 (-V), U3.5, U4.2 (-V), U4.5, U5.2 (-V), U5.5, U6.2 (-V), U6.5, U7.2 (-V), U7.5
/LCDD0: DS1.7 (D0), IC1.22 ((SCL)PC0), P4.7
/LCDD1: DS1.8 (D1), IC1.23 ((SDA)PC1), P4.8
/LCDD2: DS1.9 (D2), IC1.24 ((TCK)PC2), P4.9
/LCDD3: DS1.10 (D3), IC1.25 ((TMS)PC3), P4.10
/LCDD4: DS1.11 (D4), IC1.26 ((TDO)PC4), P4.11
/LCDD5: DS1.12 (D5), IC1.27 ((TDI)PC5), P4.12
/LCDD6: DS1.13 (D6), IC1.28 ((TOSC1)PC6), P4.13
/LCDD7: DS1.14 (D7), IC1.29 ((TOSC2)PC7), P4.14
/LCDE: DS1.6 (E), IC1.38 ((ADC2)PA2), P4.6
/LCDRS: DS1.4 (RS), IC1.40 ((ADC0)PA0), P4.4
/LCDRW: DS1.5 (R/W), IC1.39 ((ADC1)PA1), P4.5
/MUX0IO: M1.1, R21.1
/MUX0S0: IC1.5 ((~SS~)PB4), M1.10
/MUX0S1: IC1.6 ((MOSI)PB5), M1.11, P7.4
/MUX0S2: IC1.7 ((MISO)PB6), M1.14, P7.1
/MUX0S3: IC1.8 ((SCK)PB7), M1.13, P7.3
/MUX1IO: C19.2, M2.1, R24.2
/MUX1S0: IC1.14 ((RXD)PD0), M2.10
/MUX1S1: IC1.15 ((TXD)PD1), M2.11
/MUX1S2: IC1.16 ((INT0)PD2), M2.14
/MUX1S3: IC1.17 ((INT1)PD3), M2.13
/MUX2A: IC1.1 ((T0/XCK)PB0), M3.10
/MUX2B: IC1.2 ((T1)PB1), M3.9
/MUX2IO: M3.13, R2.2
/OFFSET: C17.1, R19.1, R29.2, U4.3 (+), U6.3 (+)
/POTE: DS1.3 (VO), P4.3, RV1.2
/PWMREF: IC1.21 ((OC2)PD7), R3.2
/PWMSIGNAL: IC1.4 ((AIN1/OC0)PB3), R7.2, R8.2, R9.2, R10.2
/RESET: C2.2, IC1.9 (~RESET), P7.5, R1.2, SW1.1
/VCC: C7.1, C8.2, C11.1, C12.1, C23.1, C25.1, C26.1, C27.1, DS1.2 (VDD), DS1.15 (LED+), IC1.10 (VCC), IC1.30 (AVCC), M1.24, M2.24, M3.16, P4.2, P4.15, P7.2, R1.1, R22.1, RV1.1, U1.1 (OUT), U2.6 (+V), U3.6 (+V), U4.6 (+V), U5.6 (+V), U6.6 (+V), U7.6 (+V)
/VCC/2: C9.2, C10.2, C13.2, C15.2, C22.1, R4.2, R5.2, R15.2, R17.2, R26.2, U5.1, U5.4 (-)
/x30nA: M3.12, R7.1
/x80nA: M3.14, R8.1
/x120nA: M3.15, R9.1
/x200nA: M3.11, R10.1
unnamed: C1.2, IC1.12 (XTAL2), X1.1
unnamed: C3.1, IC1.13 (XTAL1), X1.2
unnamed: C4.2, IC1.32 (AREF)
unnamed: C5.1, P1.1, U1.4 (ENABLE), U1.5 (IN)
unnamed: C6.1, U1.2 (NR)
unnamed: C9.1, R2.1, R4.1, R6.2
unnamed: C10.1, R3.1, R5.1, R11.2
unnamed: C13.1, R12.1, U2.3 (+)
unnamed: C14.1, R16.1, R19.2, U3.1
unnamed: C14.2, R11.1, R13.2
unnamed: C15.1, R13.1, U3.3 (+)
unnamed: C16.1, R14.1, R18.2, U2.1
unnamed: C16.2, R6.1, R12.2
unnamed: C18.1, R22.2, R23.1, U5.3 (+)
unnamed: C19.1, R25.2
unnamed: C20.1, R27.1, R30.2, U6.1
unnamed: C20.2, R24.1, R27.2, U6.4 (-)
unnamed: C21.1, R28.1, R31.2, U7.1
unnamed: C21.2, R25.1, R28.2, U7.4 (-)
unnamed: R14.2, R15.1, U2.4 (-)
unnamed: R16.2, R17.1, U3.4 (-)
unnamed: R18.1, R20.2, U4.4 (-)
unnamed: R21.2, U4.1
unnamed: R26.1, U7.3 (+)

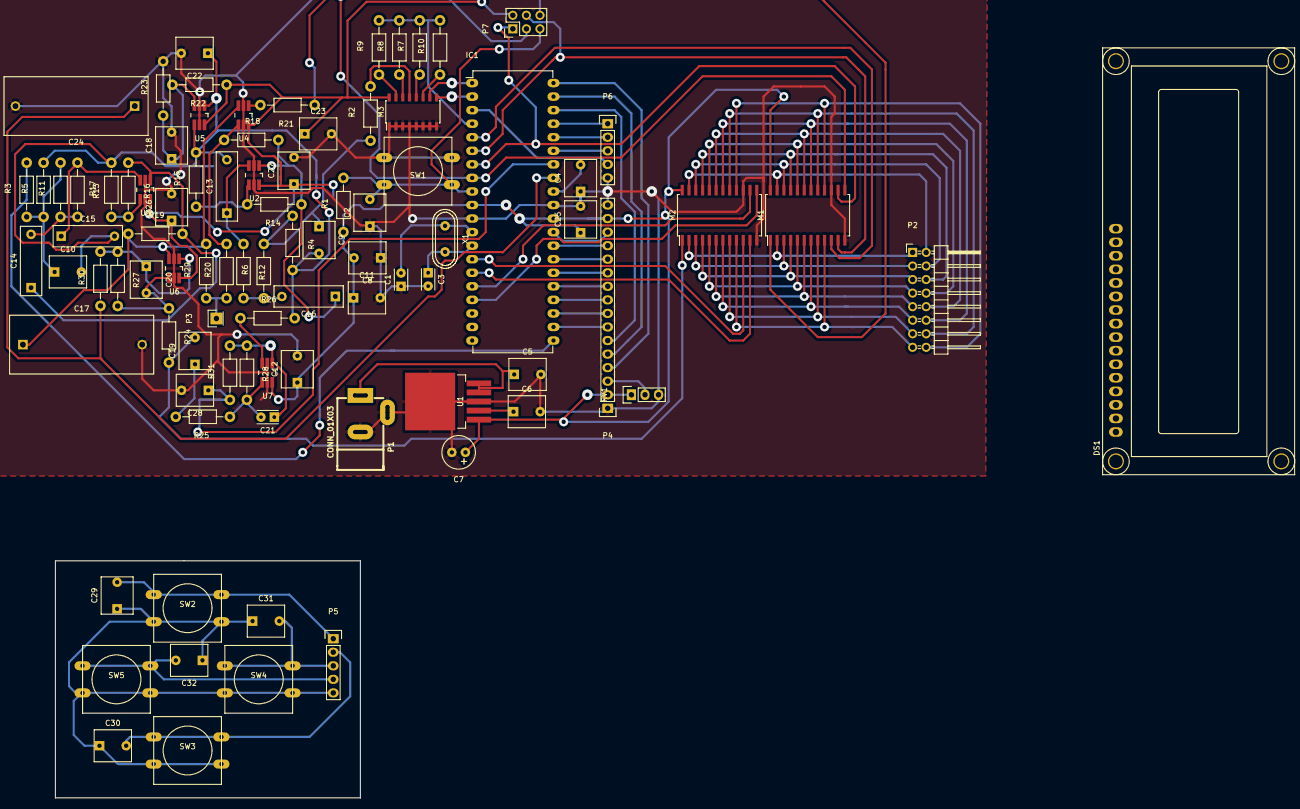
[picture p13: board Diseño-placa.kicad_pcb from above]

Board: 2 copper layers, 57.1 x 44.4 mm, 89 parts (0 on the bottom side), 83 nets.

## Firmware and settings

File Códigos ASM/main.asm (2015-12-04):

#ifdef AVRA
    .nolist
    .include "m32def.inc"
    .list
#endif


.include "configs.asm"
.include "pwm.asm"
.include "adc.asm"
.include "measure_routines.asm"
.include "MEDIR.asm"
.include "BCD.asm"
.include "LCD.asm"
.include "MENU.asm"
.include "CORREGIR_FIN.asm"


;||||||||||||||||||||||||||||||||||||||||||||||||||||||||||||||||||||||||||||||;
;|||||||||||||||||||||||||||||||||||| Main ||||||||||||||||||||||||||||||||||||;
;||||||||||||||||||||||||||||||||||||||||||||||||||||||||||||||||||||||||||||||;
MAIN:
    ldi     tmp,HIGH(RAMEND)
    out     SPH,tmp
    ldi     tmp,LOW(RAMEND)
    out     SPL,tmp  ; Stack pointer
    sei              ; Habilita las interrupciones (global)

;------------------------ Configuración de los puertos ------------------------;
;
;       PA0 --> RS  |                         PC0 --> D0  |
;       PA1 --> R/W | LCD                     PC1 --> D1  |
;       PA2 --> E   |                         PC2 --> D2  |
;       PA3 <-- ButtonLeft                    PC3 --> D3  | LCD
;       PA4 <-- ButtonRight                   PC4 --> D4  |
;       PA5 <-- ButtonOk                      PC5 --> D5  |
;       PA6 <== ADC: ImpedanceMeasure         PC6 --> D6  |
;       PA7 <== ADC: OffsetCalibration        PC7 --> D7  |
;
;
;       PB0 --> A   | MUX2                    PD0 --> S0  |
;       PB1 --> B   |                         PD1 --> S1  | MUX1
;       PB2 <== INT2: ButtonEsc               PD2 --> S2  |
;       PB3 ==> OC0: PWMSineWave              PD3 --> S3  |
;       PB4 --> S0  |                         PD4 *Unused*
;       PB5 --> S1  | MUX0                    PD5 *Unused*
;       PB6 --> S2  |                         PD6 *Unused*
;       PB7 --> S3  |                         PD7 ==> OC2: PWMOffsetAdjust
;
    ; Salidas y entradas
    ldi     tmp,0b00000111
    out     DDRA,tmp
    ldi     tmp,0b11111011
    out     DDRB,tmp
    ldi     tmp,0b11111111
    out     DDRC,tmp
    ldi     tmp,0b10001111
    out     DDRD,tmp

    ; Resistencias pull-up
    ldi     tmp,0b00111000
    out     PORTA,tmp
    ldi     tmp,0b00000100
    out     PORTB,tmp
    ldi     tmp,0b01110000
    out     PORTD,tmp

    ; Interrupción de escape
    ldi     tmp,(1<<INT2) ; Interrupción INT2 (flanco descendente por defecto)
    out     GICR,tmp

;------------------------------------------------------------------------------;
    jmp     MENU

    rjmp    MAIN ; Si se llega hasta aquí por error, se comienza de nuevo


;|//////////////////////////////////////|\\\\\\\\\\\\\\\\\\\\\\\\\\\\\\\\\\\\\|;
;|////////////////////////| Delay de 50 milisegundos |\\\\\\\\\\\\\\\\\\\\\\\\|;
;|//////////////////////////////////////|\\\\\\\\\\\\\\\\\\\\\\\\\\\\\\\\\\\\\|;
;
; Utiliza el Timer1. Solo usa el registro temporal, este nunca se salva.
;
DELAY_50ms:
    ldi     tmp,HIGH(TIMER1_50ms_DELAY_START)
    out     TCNT1H,tmp
    ldi     tmp,LOW(TIMER1_50ms_DELAY_START)
    out     TCNT1L,tmp                        ; Carga del contador del Timer1

    ldi     tmp,TIMER1_CLOCK_64_PRESCALER
    out     TCCR1B,tmp                        ; Activación del Timer1

keep_waiting:
    in      tmp,TIFR
    sbrs    tmp,TOV1      ; Saltea si el flag de overflow está encendido
    rjmp    keep_waiting

    ldi     tmp,TIMER1_OFF
    out     TCCR1B,tmp                        ; Desactivación del Timer1
    ldi     tmp,(1<<TOV1)
    out     TIFR,tmp                          ; Borrado del flag de overflow

    ret


;|//////////////////////////////////////|\\\\\\\\\\\\\\\\\\\\\\\\\\\\\\\\\\\\\|;
;|///////////////////////| Delay en segundos (1 a 255) |\\\\\\\\\\\\\\\\\\\\\\|;
;|//////////////////////////////////////|\\\\\\\\\\\\\\\\\\\\\\\\\\\\\\\\\\\\\|;
;
; param (R17) <- cantidad de segundos, 1 < param < 255
; Utiliza la rutina de delay de 50 ms. Salva todos los registros que arruina.
;
DELAY_PARAM_SECONDS:
    push    iter
    push    iter2 ; Registros salvados en el stack

    mov     iter,param ; Contador de segundos, se carga con el parámetro
loop_1s:
    ldi     iter2,20   ; Contador de 50 milisegundos: 20 * 50 ms = 1000 ms = 1 s
loop_50ms:
    rcall   DELAY_50ms
    dec     iter2      ; Decremento del contador de 50 milisegundos
    brne    loop_50ms  ; Si se contaron 20 vueltas de 50 ms se deja de repetir
    dec     iter       ; Decremento del contador de segundos
    brne    loop_1s    ; Si se contaron 60 vueltas de 1 s se deja de repetir

    pop     iter2
    pop     iter  ; Registros recuperados del stack
    ret

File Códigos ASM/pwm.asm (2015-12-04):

;||||||||||||||||||||||||||||||||||||||||||||||||||||||||||||||||||||||||||||||;
;||||||||| Interrupción de actualización del ciclo de trabajo del PWM |||||||||;
;||||||||||||||||||||||||||||||||||||||||||||||||||||||||||||||||||||||||||||||;
PWM_DUTY_CYCLE_UPDATE_ISR:
    push    tmp ; En una interrupción hay que salvar el registro temporal
    in      tmp,SREG
    push    tmp ; También hay que salvar el status register

    ld      tmp,X+    ; Próximo valor del ciclo de trabajo desde RAM
    out     OCR0,tmp  ; Valor actualizado de ciclo de trabajo
    dec     tbl_i     ; Decremento del iterador de la tabla en RAM
    brne    skip_go_beginning ; Saltea si tbl_i no es cero
    ; Go beginning
    rcall   SINE_RAM_TABLE_GO_BEGINNING
skip_go_beginning:
    pop     tmp
    out     SREG,tmp ; Se recupera el status register
    pop     tmp ; Se recupera el registro temporal
    reti


;|//////////////////////////////////////|\\\\\\\\\\\\\\\\\\\\\\\\\\\\\\\\\\\\\|;
;|///| Apuntado de la tabla del seno en RAM e inicialización del contador |\\\|;
;|//////////////////////////////////////|\\\\\\\\\\\\\\\\\\\\\\\\\\\\\\\\\\\\\|;
;
; NOTA: tbl_i (R18) y X (R27:R26) siempre en uso.
;
SINE_RAM_TABLE_GO_BEGINNING:
    ldi     XH,HIGH(PWM_SINE_RAM_TABLE)
    ldi     XL,LOW(PWM_SINE_RAM_TABLE) ; Tabla de onda escalada en RAM
    ldi     tbl_i,PWM_SINE_TABLE_LEN   ; Iterador de la tabla en RAM
    ret


;|//////////////////////////////////////|\\\\\\\\\\\\\\\\\\\\\\\\\\\\\\\\\\\\\|;
;|///////////////////////| Carga de la tabla del seno |\\\\\\\\\\\\\\\\\\\\\\\|;
;|//////////////////////////////////////|\\\\\\\\\\\\\\\\\\\\\\\\\\\\\\\\\\\\\|;
;
; param (R17) <- escalado de amplitud x 128, ejemplo: 25% = 32/128 => param = 32
; Al finalizar la tabla estará cargada en PWM_SINE_RAM_TABLE, escalada por
; param/128 y con un valor medio de PWM_SINE_MEDIAN. Salva todos los registros
; que arruina.
;
LOAD_SINE_RAM_TABLE_SCALED:
    push    R0
    push    R1
    push    tbl_i
    push    ZH
    push    ZL
    push    XH
    push    XL ; Registros salvados en el stack

    ldi     ZH,HIGH(PWM_SINE_FLASH_TABLE<<1)
    ldi     ZL,LOW(PWM_SINE_FLASH_TABLE<<1) ; Inicialización de puntero en flash
    rcall   SINE_RAM_TABLE_GO_BEGINNING ; Carga el puntero X y el contador tbl_i

loop_sine_table:
    lpm     tmp,Z+    ; Lectura desde flash, del sample original
    mulsu   tmp,param ; Sample escalado y multiplicado x 128 en R1:R0
    rol     R0 ;> División por 128: se multiplica por 2 el entero de 16 bits
    rol     R1 ;> con shifts y luego se divide por 256 quedándose con R1 (MSB)
    ldi     tmp,PWM_SINE_MEDIAN
    add     R1,tmp    ; En R1 queda el sample más la media
    st      X+,R1     ; Carga en RAM del sample final
    dec     tbl_i     ; Decremento del contador
    brne    loop_sine_table

    pop     XL
    pop     XH
    pop     ZL
    pop     ZH
    pop     tbl_i
    pop     R1
    pop     R0 ; Registros recuperados del stack
    ret


;------------------------------------------------------------------------------;
;---------------- Macros que utilizarán las siguientes rutinas ----------------;
;------------------------------------------------------------------------------;

; Carga en el puntero Z la dirección de flash recibida como argumento + param
.macro flash_point_Z_plus_param
    ldi     ZH,HIGH(@0<<1)
    ldi     ZL,LOW(@0<<1) ; Puntero en flash
    clr     tmp      ; Se borra el registro temporario
    add     ZL,param ; Se desplaza en la tabla según el parámetro de entrada
    adc     ZH,tmp   ; Se suma el acarreo a la parte alta (tmp = 0)
.endmacro

; Escribe el valor del MUX2 según R0, sin chequear su contenido
.macro set_MUX2_with_R0_value
    cli     ; Se desactivan las interrupciones para hacer el cambio
    in      tmp,PORTB                   ; Lectura desde el puerto B
    cbr     tmp,(1<<PORTB0)|(1<<PORTB1) ; Limpieza de los bit del MUX2
    or      tmp,R0                      ; Se graban los bit del MUX2 con R0
    out     PORTB,tmp                   ; Escritura hacia el puerto B
    sei     ; Se vuelven a activar las interrupciones
.endmacro


;|//////////////////////////////////////|\\\\\\\\\\\\\\\\\\\\\\\\\\\\\\\\\\\\\|;
;|/////////| Encender la senoidal, para el rango de medición deseado |\\\\\\\\|;
;|//////////////////////////////////////|\\\\\\\\\\\\\\\\\\\\\\\\\\\\\\\\\\\\\|;
;
; param (R17) <- rango, 4 opciones: MEAS_RANGE_X con X en {1, 2, 3, 4}
; Encenderá el PWM de la senoidal para un rango de medición determinado,
; especificado en el parámetro de entrada, por medio de un valor "enumerativo"
; MEAS_RANGE_X, no hace chequeos de borde, se asume que se recibe un valor
; correcto. Salva todos los registros que arruina.
;
PWM_SINE_START:
    push    R0
    push    param
    push    ZH
    push    ZL ; Registros salvados en el stack

    ; Selección del multiplexor MUX2
    flash_point_Z_plus_param MEAS_RANGE_FLASH_SIN_MUX2_VALUES
    lpm     R0,Z
    set_MUX2_with_R0_value

    ; Creación de tabla en RAM
    flash_point_Z_plus_param MEAS_RANGE_FLASH_SINAMPS
    lpm     param,Z  ; Valor correspondiente de amplitud para la rutina
    rcall   LOAD_SINE_RAM_TABLE_SCALED

    ; Inicialización del puntero X y el contador tbl_i, no se pueden usar más!
    rcall   SINE_RAM_TABLE_GO_BEGINNING

    ; Configuración del Timer0 como PWM
    ldi     tmp,PWM_FAST_PWM_CONFIG_T1
    out     TCCR0,tmp   ; Habilita el PWM en modo rápido
    in      tmp,TIMSK
    sbr     tmp,PWM_OV_INTERRUPT_MASK
    out     TIMSK,tmp   ; Habilita la interrupción de overflow Timer0

    pop     ZL
    pop     ZH
    pop     param
    pop     R0 ; Registros recuperados del stack
    ret


;|//////////////////////////////////////|\\\\\\\\\\\\\\\\\\\\\\\\\\\\\\\\\\\\\|;
;|////////////| Apagar la onda de salida (dejar PWM al 50 % fijo) |\\\\\\\\\\\|;
;|//////////////////////////////////////|\\\\\\\\\\\\\\\\\\\\\\\\\\\\\\\\\\\\\|;
;
; Apaga la onda del PWM, es decir que deja lo deja en su valor medio de forma
; constante (50 % de duty cycle). Salva todos los registros que arruina.
;
PWM_SINE_STOP:
    push    R0 ; Registros salvados en el stack

    ; Se pone el MUX2 en x30nA para minimizar errores de offset
    ldi     tmp,MUX2_x30nA
    mov     R0,tmp
    set_MUX2_with_R0_value

    ; Configuración del Timer0 como PWM
    ldi     tmp,PWM_FAST_PWM_CONFIG_T1
    out     TCCR0,tmp   ; Habilita el PWM en modo rápido
    in      tmp,TIMSK
    cbr     tmp,PWM_OV_INTERRUPT_MASK
    out     TIMSK,tmp   ; Deshabilita la interrupción de overflow Timer0

    ldi     tmp,PWM_SINE_MEDIAN
    out     OCR0,tmp    ; Pone el valor medio en la salida

    pop     R0 ; Registros recuperados del stack
    ret
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

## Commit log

2015-09-21 Comentar paquete unidades SI
    No lo necesitamos aún y en mi computadora no funciona así como está.
    Además, cambié el tamaño de la sangría.
2015-09-22 Revisión general y agregado de diagramas
    * Lógica general, orden de la información en las secciones.
    * Diagrama de flujo, hecho con 'dia'.
    * Diagrama en bloques, hecho con 'dia'.
2015-09-29 Actualización de correcciones y tabla de componentes
2015-09-30 Gantt y detalles finales
    (Faltan los precios de los componentes)
    [Gantt.xlsx]
2015-10-01 Agregado de precios y modificaciones menores
    * Precios obtenidos de mercadolibre y/o con un dolar estimativo de $12
    * Cambio de nombre del directorio anteproyecto/img/dia hacia anteproyecto/img/src
    * Leves modificaciones del Gantt y paso del mismo al formato ODF, exportando en PDF para evitar el uso de imágenes
    * Cambios menores en la carátula para ajustar el docente guía, el curso y detalles de formato
    [Gantt.xlsx, gantt.ods]
2015-10-01 Error de tipeo en el diagrama en bloques corregido
2015-10-21 Codigos de Assembler
2015-10-30 Actualización del esquemático para simulación
    Nota: se eliminan y dejan de versionar los archivos .raw
    de LTspice, ya que son muy grandes y se pueden regenerar
    simulando nuevamente. Así se evitan problemas al hacer
    'push' hacia el repositorio remoto.
2015-11-02 Comienzo esquemático Kicad
    [Diseño placa.kicad_pcb, Diseño placa.sch]
2015-11-03 Renombrado: anteproyecto -> Anteproyecto
    [gantt.ods]
2015-11-03 Actualización del esquemático (!)
    (!): la simulación no está funcionando en este momento.
2015-11-03 Cambios en el esquemático (*) (!)
    (*) Se solucionó el problema de que no simulaba.
    (!) El método propuesto para el offset no funciona.
2015-11-06 Espacio sobrante y falta de tilde en "Códigos ASM"
2015-11-07 Rutina de medir, corregir y calibrar (LCD)
2015-11-07 Cambio de interrupciones por polling
2015-11-09 Avances esquemático en Kicad
    [Diseño placa.sch]
2015-11-13 Agregado de algunas rutinas y archivos de ayuda
2015-11-14 Más del esquemático Kicad
    [Diseño placa.sch, Diseño-placa.kicad_pcb, Diseño-placa.sch]
2015-11-15 Esquemático de LTspice actualizado
    * Actualización con la última versión enviada por Ariel.
    * Eliminación del .plt que puede ya no ser válido para el nuevo .asc.
2015-11-16 Más esquemático Kicad
    [Diseño-placa.sch]
2015-11-17 Correcciones esquemático y asociación de componentes Kicad
    [Diseño-placa.sch]
2015-11-20 Reorganización del código y nuevas rutinas
    * Se agregó un archivo de Excel (OpenOffice) con cálculos de calibración.
    * Se renombró el directorio Extras Octave, a Extras, para poner contenido
    variado, incluyendo la planilla de cálculos mencionada.
    * Se reacomodó el código pensando en la futura integración de todo.
    * Se renombraron archivos y movieron contenidos, separando las partes.
    * Se crearon nuevas rutinas en el manejo del PWM y el multiplexor MUX2.
    [Cálculos de calibración.ods]
2015-11-22 Comienzo PCB
    [Diseño-placa.sch]
2015-11-22 Esquema informe
    [gantt.ods]
2015-11-24 Informe: Listado de componentes y esquemático
    [gantt.ods]
2015-11-24 Actualización del informe
    * Se actualizó el diagrama en bloques.
    * Se exportó el esquemático en PDF porque estaba pixelado.
    * ADC.asm renombrado a adc.asm
2015-11-24 Actualización PCB
    *Conector de programación
    *Capacitores de los pulsadores
    [Diseño-placa.kicad_pcb, Diseño-placa.sch]
2015-11-24 Actualizaciones de código
    * Varios reordenamientos y cambios menores.
    * Rutina de muestreo del ADC.
2015-11-25 PCB terminado
    [Diseño-placa.kicad_pcb, Diseño-placa.sch]
2015-11-25 Corrección tamaño de capacitores
    [Diseño-placa.kicad_pcb, _saved_Diseño-placa.sch]
2015-11-28 Actualización del informe
    * Revisión de los textos del anteproyecto.
    * Agregado de la planilla de cálculos de calibración.
    * Archivo assembly renombrado.
    [Cálculos de calibración.ods]
2015-11-28 Mejoramiento y agregado de rutinas
    * Mejoras generales, revisión del código.
    * Rutinas de delay de 50 ms y delay en segundos (de 1 a 255).
    * Rutina de medición de pico desde la tabla en RAM del ADC.
2015-11-29 Reacomodamiento general y resolución de problemas
    * Rutina que obtiene la medición escalando por el valor calibrado de cada
    rango.
    * "Medir y Corregir.asm" renombrado a "MENU.asm"
    * Detalles menores y agregado de tablas en flash con valores asociados a los
    rangos.
    * .gitignore actualizado para ignorar los archivos *.net de LTspice.
    * Eliminación de archivo agregado por error en un merge de Kevin.
    [MENU.asm, adc.asm, configs.asm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]
2015-11-29 Modificaciones menores en el código + informe.pdf
    * Agregado de rutina inicial de activación del PWM de Offset.
    * informe.pdf eliminado por error agregado.
    [configs.asm, main.asm, pwm.asm]
2015-11-29 Agregado de interrupción para el botón de escape
2015-11-30 PCB corrección de pistas conflictivas
    [Diseño-placa.sch, _saved_Diseño-placa.sch]
2015-12-01 Última versión PCB
    [Diseño-placa.kicad_pcb]
2015-12-01 Modificaciones varias
    * Makefile.
    * Actualización del .gitignore.
    * Cambios menores de integración en el código.
2015-12-01 Más informe
    [Diseño-placa.sch]
2015-12-01 Cambios varios y de último momento (warning!)
2015-12-04 Actualización para entrega de compromiso
    Los rangos de medición fueron reducidos por problemas de hardware, el código fue
    adaptado de forma tal que funcione para estos nuevos valores. También se
    agregaron algunas funcionalidades, incluyendo la finalización de la rutina de
    corrección.
    [MEDIR.asm, MENU.asm, configs.asm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]
2015-12-04 Actualización de recursos del informe
    * Diagrama de flujo.
    * PCB del circuito.
2015-12-04 Agregado de gráfico del osciloscopio
    [WaveData2240.csv]
2015-12-04 Agregado de la última versión del código
2015-12-10 Retoque y refinado del informe
    * Limpieza de archivos temporarios.
    * Explicación de la sección de cálculos.
    * Uso de listings para incluir el código fuente.
